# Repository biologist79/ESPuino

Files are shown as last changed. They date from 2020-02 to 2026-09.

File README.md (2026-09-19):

# ESPuino - RFID-controlled Audio Player based on ESP32 with I2S-DAC Support



## Forum

- EN: I've set up a primarily German-speaking community with much documentation. Also an
  international corner for non-German-speakers is available at <https://forum.espuino.de>.
  GitHub login can be used for signing in there (optional).
- DE: Ich habe ein primär deutschsprachiges Forum aufgesetzt, welches ich mit reichlich Doku
  versehen habe. Würde mich freuen, euch dort zu sehen: <https://forum.espuino.de>. Ihr könnt euch
  dort mit eurem Github-Login einloggen, jedoch auch "normal" anmelden. Dokumentation findet ihr
  insbesondere hier: <https://forum.espuino.de/c/dokumentation/anleitungen/10>.

## Handbook

- EN: A comprehensive handbook (German, English, French) covering setup, hardware, the web
  interface, and troubleshooting is available at <https://biologist79.github.io/ESPuino-Docs/>. It
  always describes the current state of the `dev` branch.
- DE: Ein ausführliches Handbuch (Deutsch, Englisch, Französisch) zu Aufbau, Hardware, Webinterface
  und Troubleshooting gibt es unter <https://biologist79.github.io/ESPuino-Docs/>. Es beschreibt
  immer den aktuellen Stand des `dev`-Branches.

## Firmwares

Ready-to-use firmwares are available for [download](https://github.com/biologist79/ESPuino-Firmware) for several
HALs with or without bluetooth support enabled. These are provided for
[master](https://github.com/biologist79/ESPuino-Firmware/tree/main/Firmwares/master) and
[dev-branch](https://github.com/biologist79/ESPuino-Firmware/tree/main/Firmwares/dev).

## News

> :warning: Due to memory restrictions and complexity, ESPuino doesn't run safely on ESP32
without PSRAM. So please make sure to use an ESP32-WROVER!

> :warning: As of January 8, 2026, MQTT topics have changed! Further infos [here](https://forum.espuino.de/t/neues-namensschema-fuer-mqtt/2553/34).

## Current development

There is a [development branch (dev)](https://github.com/biologist79/ESPuino/tree/dev) that contains
new features, that will be introduced and tested there first until they become part of the master
branch. Feel free to test but be advised this could be unstable.

## ESPuino - what's that?

The concept of ESPuino is a [more-or-less small enclosure](https://forum.espuino.de/t/zeigt-her-eure-espuinos/554/)
that contains a speaker so it can play music and audiobooks. Here is an example of a 3D-printed
unit, the [Biobox 3d](https://forum.espuino.de/t/biobox-3d/3130):

Biobox 3d

Primarily the device is controlled using RFID tags (usually cards), similar to those used for access control
(ski lifts, office access, etc.). To uniquely identify an RFID card, it carries a fixed ID.
ESPuino reads that ID (a 12-digit number) with an RFID card reader and triggers an action associated
on it. Which action to take is taught beforehand via ESPuino’s web interface: you upload audio
files to a microSD card, pick the desired audio file (or an entire folder) in the web interface’s
file browser and link it to the RFID card you placed. You mostly just click through the
web interface while manual input is possible (but usually unnecessary). When the RFID tag is presented
again, ESPuino loads the mapping and starts the desired playback. Present a different RFID tag and
the playback associated with that tag starts. In addition to audio files from the local microSD
card, web streams can be played, too. In Bluetooth mode you can also stream to the ESPuino from
your phone using [A2DP](https://de.wikipedia.org/wiki/A2DP), for example.

Further control elements on ESPuino are buttons and a [rotary encoder](https://forum.espuino.de/t/drehencoder-by-espuino/2414).
Buttons can be assigned dozens of different actions via the web interface — even double assignments (short
press vs. long press) are possible. By default, turning the rotary encoder controls the volume, but it
includes an integrated button, that's usually used to switch on ESPuino and
starts measurement of battery's voltage which is instantly indicated via LEDs (Neopixel). Additionally,
holding down a configured button while turning the encoder runs that button's own assigned rotary action
instead - e.g. seeking within a track or adjusting Neopixel brightness - freely configurable per
button and turning direction via the web interface. By default,
ESPuino is designed for three buttons and one rotary encoder, but this can be varied: from 0 up to 5
buttons, and no rotaty encoder or one rotaty encoder. If no rotary encoder is present, volume
control is handled, for example, via buttons.

A key feedback element is color-programmable LEDs (Neopixels), typically used as a
[Neopixel ring](https://duckduckgo.com/?t=ffab&q=neopixel+ring&ia=images&iax=images). They can
show, for example, track progress (if half the LEDs are lit, the track is half done), volume,
battery level, and error states — and
[much, much more](https://forum.espuino.de/t/was-zeigt-der-neopixel-des-espuino-alles-an/86)! ESPuino
also works without Neopixels, but that is not recommended because they convey a lot of information.

There is also an optional [headphone jack](https://forum.espuino.de/t/kopfhoererplatine-basierend-auf-ms6324-und-tda1308-bzw-lm4808m/1099)
that mutes the speaker when headphones are plugged in. Alternatively, Bluetooth headphones can be used.

ESPuino also communicates with the outside world: besides the web interface, it supports
[MQTT](https://de.wikipedia.org/wiki/MQTT), a [REST API](https://github.com/biologist79/ESPuino/blob/master/REST-API.yaml)
and an FTP server. New audio files can be copied to the microSD card via the web interface or
FTP — so the microSD card does not need to be removed.

## Hardware setup

You could start on a breadboard with jumper wires. However, the simplier way is to kickstart right away
with a PCB that was especially developed for ESPuino. There are [several available](https://forum.espuino.de/c/hardware/pcbs/11),
but ["ESPuino Complete"](https://forum.espuino.de/t/espuino-complete/3817) can be considered being the
latest one. This pcb can obtained via the [forum](https://forum.espuino.de/). It covers a charger
for LiFePO4 or LiPo batteries (for sure also runs with USB-C only) and provides connectors for up to 5 buttons,
rfid-reader, rotary encoder, i2c external, Neopixel, USB-C, µSD, speaker, [headphones PCB](https://forum.espuino.de/t/kopfhoererplatine-basierend-auf-ms6324-und-tda1308-bzw-lm4808m/1099) and some custom stuff.
[Port-expander](https://www.nxp.com/docs/en/data-sheet/PCA9555.pdf) and [MAX98357a](https://www.analog.com/en/products/MAX98357A.html)
are integrated, too. A [buck boost converter](https://www.ti.com/product/TPS63000) provides
stable 3.3 V while battery's voltage is [supervised](https://www.sg-micro.com/product/SGM809)
in order to prevent it from deep discharge. However, NEVER(!) use a lithium battery without a
further protection circuit that's already part of the battery pack!

Complete

> :warning: However, feel free to develop PCBs yourself. But again, be advised your ESP32 needs PSRAM in order to run ESPuino properly.

Optionally a [headphone-pcb](https://forum.espuino.de/t/kopfhoererplatine-basierend-auf-ms6324-und-tda1308/1099/)
can be attached to [Complete](https://forum.espuino.de/t/espuino-complete/3817) in order to connect headphones.
While headphone's plugged in, speaker is automatically disabled.

## Getting started (for users)

- [Much more documentation in german
  language](https://forum.espuino.de/c/dokumentation/anleitungen/10).
- There are already ready-to-use firmwares for [download available](https://github.com/biologist79/ESPuino-Firmware) that
  probably already fit your needs. Further informations can be found [here](https://forum.espuino.de/t/fertige-espuino-firmwares-zum-runterladen/3941). [Complete](https://forum.espuino.de/t/espuino-complete/3817) is always already shipped with running firmware, so your ESPuino should start right away.
- ESPuino opens a wifi access point that you need to join. For further details please refer [the first start](https://forum.espuino.de/t/der-erste-start-deines-espuino/29).
- Please make sure to read the [documentation of the web interface](https://forum.espuino.de/t/dokumentation-webinterface/2807).

## Getting started (for developers)

- In case you want (or need) to compile your own firmware, first you need to install Microsoft's [Visual Studio Code](https://code.visualstudio.com/).
- Install [PlatformIO Plugin](https://platformio.org/install/ide?install=vscode) into [Visual Studio
  Code](https://code.visualstudio.com/) and make sure to have a look at the
  [documentation](https://docs.platformio.org/en/latest/integration/ide/pioide.html).
  Step-by-step-manual is available
  [here](https://randomnerdtutorials.com/vs-code-platformio-ide-esp32-esp8266-arduino/.)
- Install [Git](https://git-scm.com/downloads) and make a copy ("clone") of my repository to your local
  computer using `git clone https://github.com/biologist79/ESPuino.git`. Using Git you can keep your
  local repository easily up to date without doing copy'n'paste. To keep it up to date run `git pull
  origin master`. Further infos
  [here](https://stackoverflow.com/questions/1443210/updating-a-local-repository-with-changes-from-a-github-repository)
  and
  [here](https://forum.espuino.de/t/espuino-in-platformio-anlegen-und-mit-git-aktuell-halten/891).
- (Optional) Install [GitLens](https://marketplace.visualstudio.com/items?itemName=eamodio.gitlens)
  as plugin (to have advanced Git features in VSCode).
- Now, that the Git repository is saved locally, import this folder into Platformio as a project.
- Select the [desired
  environment](https://forum.espuino.de/t/projekt-und-profilwechsel-in-visual-studio-code/768) (e.g.
  complete).
- Edit `src/settings.h` according your needs.
- Edit board-specific (`HAL`) config-file (e.g. `settings-complete.h` for Complete PCB) and switch to
  that HAL in VSC. If you're running a board that is not listed there: start with `settings-custom.h`
  and change it according your needs.
- Connect your PCB/develboard via USB, click the alien-head icon in the left sidebar, choose the project
  task that matches your desired HAL and run `Upload and Monitor`. All libraries necessary are
  fetched automatically and compilation of the code gets started. After that, your ESP32 is flashed
  with the firmware.
- Now have a look at the serial output at the bottom of Visual Studio Code's window. At the first
  run there might appear a few error messages (related to missing entries in NVS). Don't worry, this
  is just normal. However, make sure the µSD card is detected as this is mandatory for ESPuino to boot!
- If everything is fine, at the first run, ESPuino should open an access-point and ESPuino offers a
  captive portal (available in your browser's language, if supported) that is shown on your computer.
  If that's not the case, join a WiFi called
  "ESPuino" and enter `http://192.168.4.1` to your webbrowser. Enter WiFi credentials and the
  hostname there (or in the captive portal). Before saving, you can test the entered credentials
  directly from this page: ESPuino tries connecting to your WiFi in the background while the setup
  access point stays up, and reports success or a specific failure reason (e.g. wrong password,
  network not found) right there - no need to save, reboot and hope. After saving the configuration,
  restart ESPuino.
- After reboot ESPuino tries to join your WiFi (with the credentials previously entered). If that
  was successful, an IP is shown in the serial console. You can access ESPuino's web interface using a
  webbrowser via this IP; make sure to allow Javascript. If the mDNS feature is active in
  `src/settings.h`, you can use the hostname configured extended by .local instead the IP. So if you
  configured `espuino` as hostname, you can use `http://espuino.local` for web interface and FTP.
- Via FTP and web interface you can upload data (expect a throughput of roughly 650 kB/s via the web interface).
- FTP needs to be activated after boot if you need it! Don't forget to assign action
  `ENABLE_FTP_SERVER` in `settings.h` to be able to activate it. Neopixel flashes green (1x) if
  enabling was successful. It'll be disabled automatically after next reboot. Means: you have to
  enable it every time you need it (if reboot was in between). Sounds annoying and maybe it is,
  but's running this way in order to have more heap-memory available (for webstream) if FTP isn't
  needed.
- Via webbrowser you can configure various settings and pair RFID tags with actions. If
  MQTT/FTP-support was not compiled, their config tabs won't appear.

## SD-card: SPI or SD-MMC (1 bit)-mode? (for developers)

Having the µSD card working is mandatory, ESPuino doesn't start without working SD card (at least
unless `NO_SDCARD` hasn't been enabled previously). However, there are two modes available to
interface µSD cards: SPI and SDMMC (1 bit). Be advised that SDMMC is twice as fast as SPI and
needs one GPIO less. So basically it's a no-brainer and SDMMC is used for "ESPuino Complete".

## Which RFID-reader: RC522 or PN5180?

RC522 is in a way the ESPuino standard: it's cheap and works, but RFID tags have to be placed close
to the reader. PN5180 instead has better RFID range/sensitivity and can read ISO-15693 / iCode
SLIX2-tags aka 'Tonies' (you need a password to read Tonies), too. You can also wake up ESPuino with
the a RFID tag (after flashing PN5180 with a new firmware). This feature is called LPCD.
Disadvantages PN5180: it's more expensive and needs more GPIOs (6/7 instead of 4). In my opinion
it's worth it! Refer to PN5180's wiring section below for further information. Hint: if using 3.3 V
only make sure to connect these 3.3 V to PN5180's 5 V AND 3.3 V. Sounds weird but it's necessary.

## 3.3 V only or 5 V, too? (for developers)

ESP32 itself runs at 3.3 V only. But what about the periphery? Spoiler: "Complete" internally runs at
3.3 V only.

- My opinion: 3.3 V! Because it's simple. If you plan to use battery mode with LiPo/LiFePO4,
  there's no 5 V available (unless USB is connected or you make use of a boost converter).
- MAX98357A: provides more power at 5 V but also runs at 3.3 V. Anyway: it's still loud enough (in
  my opinion).
- Neopixel: specification says it needs 5 V but runs at 3.3 V absolutely fine.
- RC522: needs 3.3 V (don't ever power with 5 V!)
- PN5180: at 3.3 V make sure to connect both 5 V and 3.3 V pins to 3.3 V. If 5 V is available all
  the time: connect 5 V to 5 V and 3.3 V to 3.3 V.
- SD card: needs 3.3 V but if voltage regulator is onboard, it can be connected to 5 V as well
- Rotary encoder: 3.3 V (don't power with 5 V! Encoder doesn't care if connected to 3.3 or 5 V, but
  GPIOs of ESP32 do!)

## WiFi

WiFi is mandatory for web interface, FTP, MQTT and webradio. However, it can be temporarily or
permanently disabled (and ESPuino remembers this state after the next restart). There are two ways
to (re-)enable/disable WiFi:

- Use a special [modification card](https://forum.espuino.de/t/was-sind-modifikationskarten/37) that
  can be configured via web interface.
- Assign action `CMD_TOGGLE_WIFI_STATUS` to a button (or multi-button). This toggles the current
  WiFi status.

## Bluetooth

> :warning: **Bluetooth can now run in parallel with WiFi**, so streaming webradio via
  Bluetooth or accessing the web interface while a Bluetooth mode is enabled is possible.
  However, this combination is still not well tested and both stacks running at once puts
  considerably more pressure on the ESP32's limited RAM, so memory problems (up to crashes)
  are possible - use with caution. Switching between Bluetooth modes (or back to normal
  mode) still requires a restart.

### ESPuino as A2DP sink (stream to ESPuino)

ESPuino can be used as Bluetooth sink (A2DP sink). In this mode you can stream audio (e.g. from a
mobile device) via Bluetooth to your ESPuino. This mode can be enabled/disabled via a RFID
modification card or by assigning action `CMD_TOGGLE_BLUETOOTH_MODE` to a button (or multi-button).
Applying this will restart ESPuino immediately. Activated Bluetooth is indicated by four
slow rotating _blue-violet_ LEDs. After the Bluetooth device is paired the LEDs turn to blue.

### ESPuino as A2DP source (stream from ESPuino)

ESPuino can also be used to stream audio (A2DP source) to a Bluetooth headset or external Bluetooth
speakers. This mode can be enabled/disabled via a RFID modification card or by assigning action
`CMD_TOGGLE_BLUETOOTH_SOURCE_MODE` to a button (or multi-button). Applying this will restart ESPuino
immediately. Activated Bluetooth is indicated by four slow rotating _blue-violet_ LEDs. After the
Bluetooth headset is connected LEDs turn to blue.

## Port expander (for developers)

There might be situations where you run out of GPIOs. To address this, a port expander
[PCA9555](https://www.nxp.com/docs/en/data-sheet/PCA9555.pdf) can be used to extend the number of
input channels (output mode is only supported in special cases). PCA9555 provides 2 ports with 8
channels each - so 16 channels in total. To activate PCA9555 you need to enable
`PORT_EXPANDER_ENABLE`. Like GPIOs in your develboard-specific settings-file, you can assign
numbers. Range is `100` (port 0 channel 0) -> `115` (port 1 channel 7). Via `expanderI2cAddress` the
port expander's I2C-address can be changed. It's `0x20` if pins `A0`, `A1`, `A2` are wired to GND.

## After ESPuino is connected to your WiFi

After making ESPuino part of your LAN/WiFi, the 'regular' web interface is available at the IP assigned by
your router (or the configured hostname). Using this interface you can:

- configure WiFi
- make bindings between RFID tag, file/directory/URL and playback mode
- make bindings between RFID tag and a modification type
- configure MQTT and its topics (if enabled)
- configure FTP (if enabled)
- configure initial volume, minimum volume, maximum volume (speaker / headphone), brightness of
  Neopixel (night mode / default) and inactivity time
- configure voltage levels for battery mode (and optionally let ESPuino shut down automatically on
  critically low voltage)
- configure type of rfid reader (however, not necessary because of [autodetection](https://forum.espuino.de/t/autoerkennung-von-rfid-reader/4453))
- view logs / status / current track / cover art (if available)
- control player
- run modifications (like modification card)
- upload audiofiles (called web transfer)
- do OTA updates (ESP32-WROVER with 16 MB of flash memory only)
- import + delete NVS-RFID-assigments
- restart + shutdown ESPuino

> :information_source: As you apply a RFID tag to the RFID reader, the corresponding ID is pushed to
  the web interface automatically. So there's no need to enter such IDs manually (unless you want to). The
  file path is filled out automatically by selecting a file/directory in the file browser.

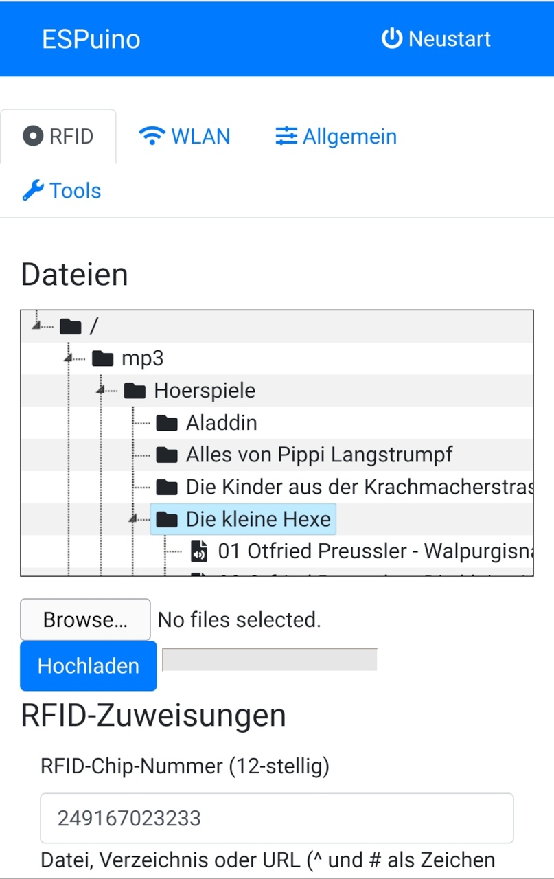
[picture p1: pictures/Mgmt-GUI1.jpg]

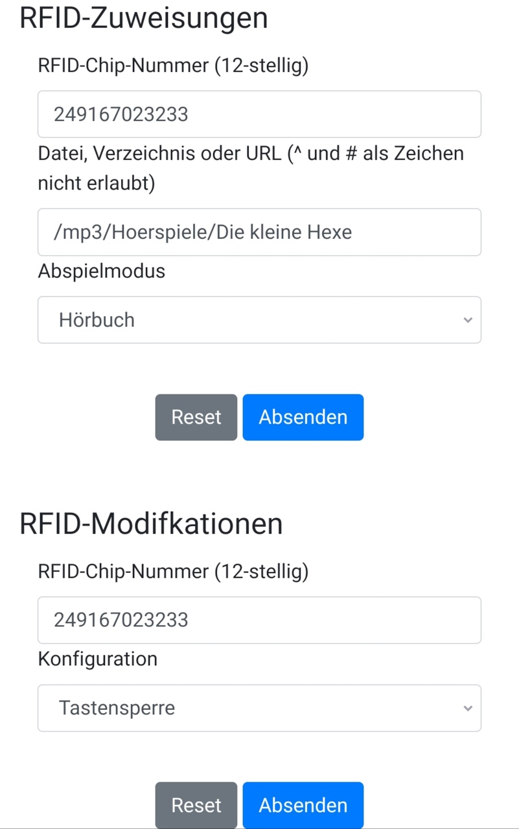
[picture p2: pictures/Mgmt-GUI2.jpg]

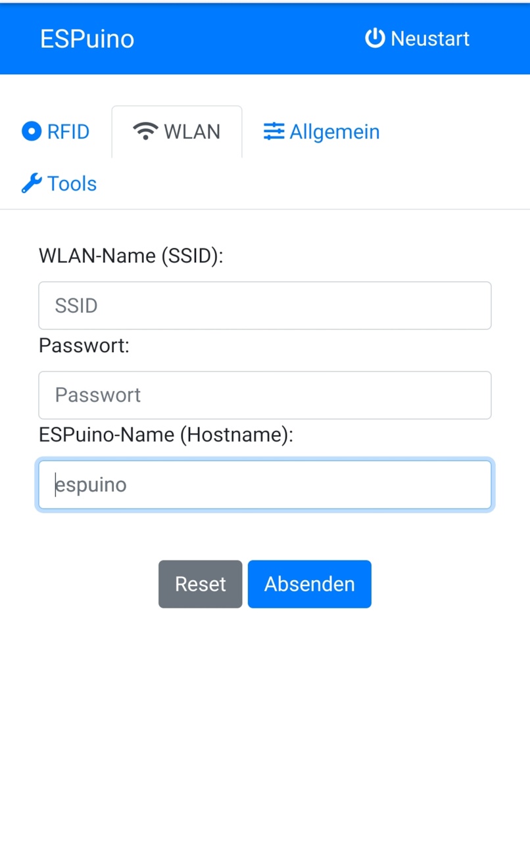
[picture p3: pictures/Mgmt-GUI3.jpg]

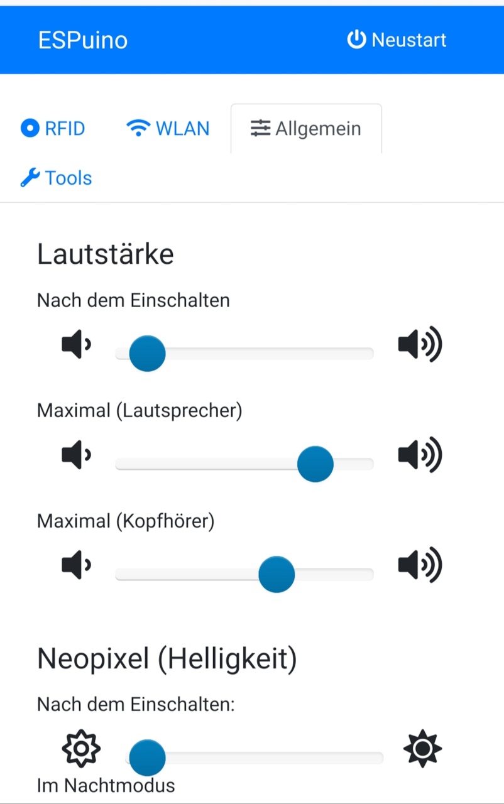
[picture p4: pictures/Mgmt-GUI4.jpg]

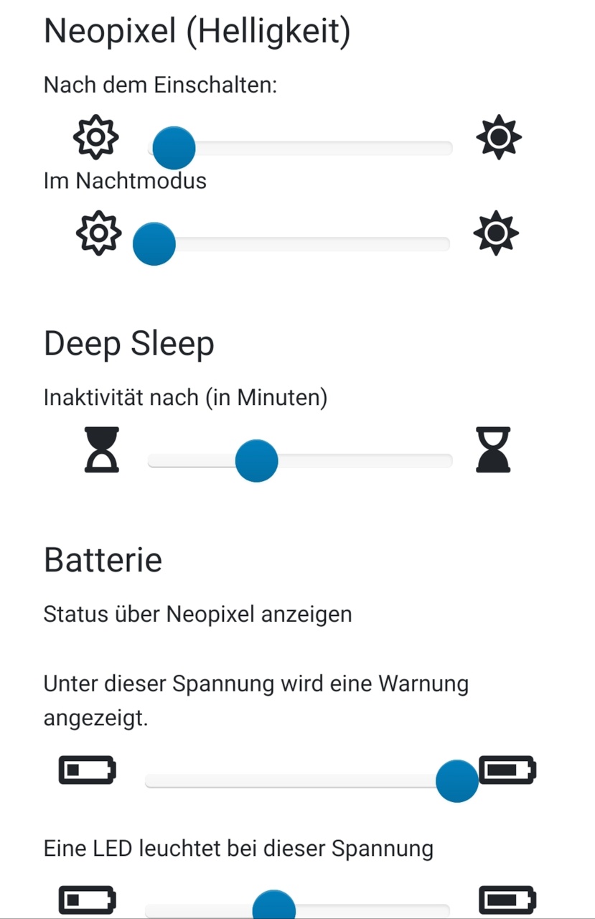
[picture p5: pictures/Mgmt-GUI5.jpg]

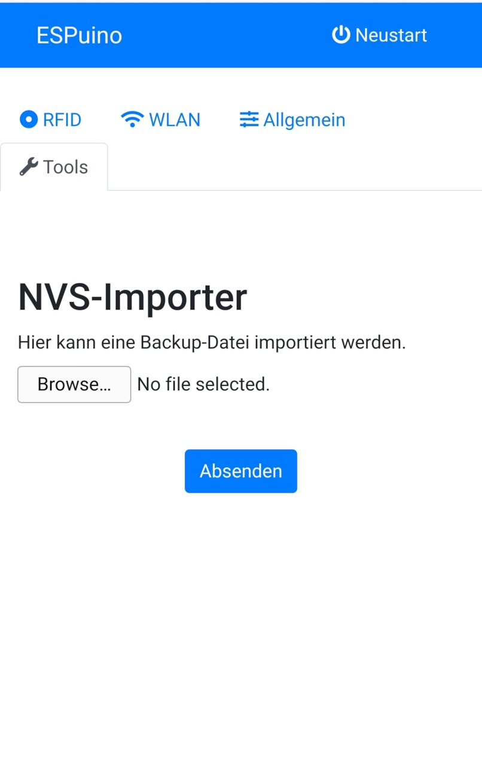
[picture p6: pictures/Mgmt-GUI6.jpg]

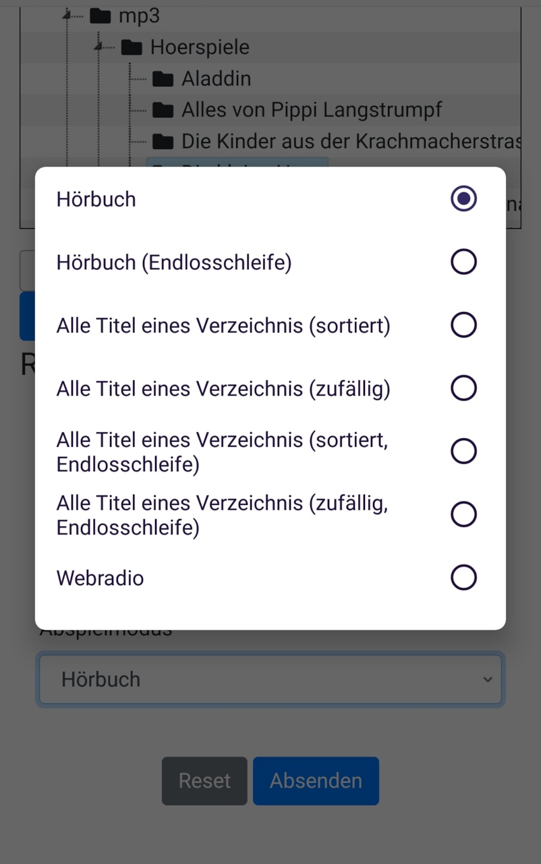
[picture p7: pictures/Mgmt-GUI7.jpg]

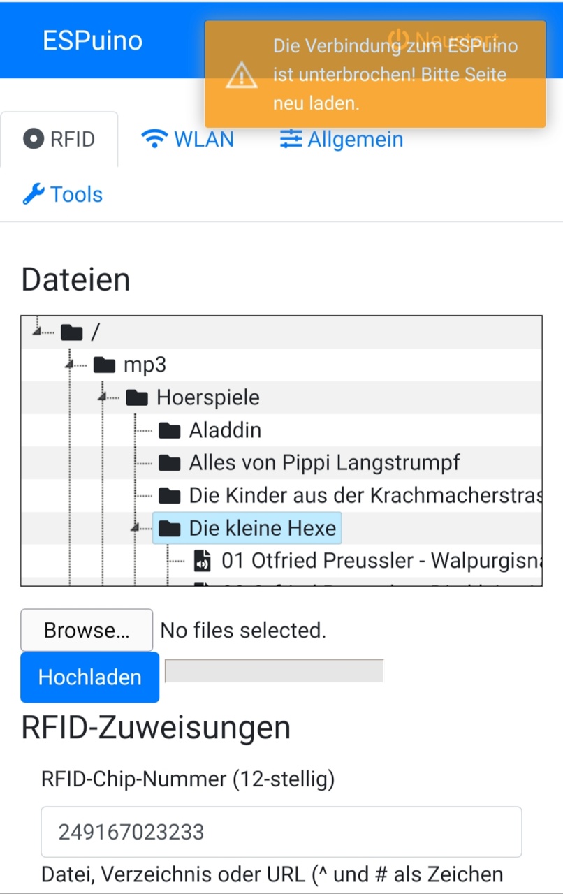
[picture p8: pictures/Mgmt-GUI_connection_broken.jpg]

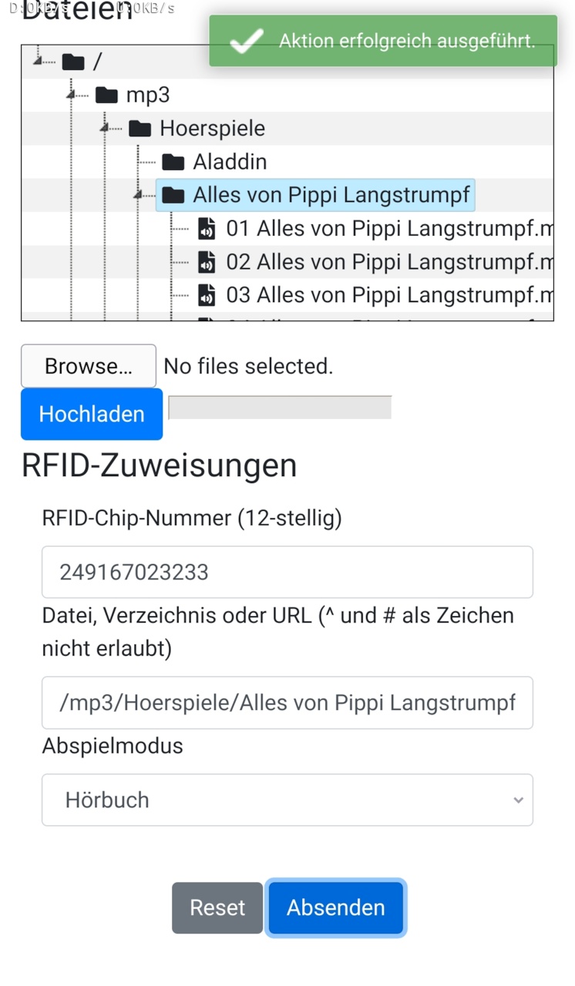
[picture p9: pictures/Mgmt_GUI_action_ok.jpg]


## Interacting with ESPuino

### Playback modes

It's not just simply playing music; different playback modes are supported:

| Type | Action |
| --- | --- |
| `Single track` | Plays one track one time |
| `Single track (loop)` | Plays one track forever |
| `Single track of a directory (random). Followed by sleep` | Picks and plays one single track out of a directory and falls asleep subsequently. Neopixel gets dimmed.|
| `Audiobook` | Single file or playlist/folder; last play position (file and playlist) is saved (when pushing pause or moving to another track) and reused next time |
| `Audiobook (loop)` | Same as audiobook but loops forever |
| `Audiobook with subdirectories (recursive)` | Same as audiobook, but with subdirectories |
| `Folder/playlist (sorted)` | Plays all tracks in order from a folder one time |
| `Folder/playlist (random order)` | Plays all tracks in random order from a folder one time |
| `Folder/playlist (sorted)` | Plays all tracks in order from a folder forever|
| `Folder/playlist (random order)` | Plays all tracks in random order from a folder forever |
| `All tracks of a random subdirectory (sorted)` | Plays of tracks in order of a randomly picked subdirectory of a given directory |
| `All tracks of a random subdirectory (random order)` | Plays all tracks in random order of a randomly picked subdirectory of a given directory |
| `All tracks of a directory + subdirectories (random, recursive)` | Same as All tracks of a random subdirectory (random order) but with subdirectories |
| `All tracks of a directory + subdirectories (sorted, recursive)` | Same as All tracks of a random subdirectory (sorted) but with subdirectories |
| `Webradio` | always only one "track": plays a webstream |
| `List (files from SD and/or webstreams) from local .m3u-File` | Can be one or more files / webradio stations with local .m3u as sourcefile |

### Modification RFID tags

There are special RFID tags, that don't start music by themselves but can modify ESPuinos behaviour. If applied
a second time, it's previous action/modification will be reversed.

So first make sure to start the music then use a modification card in order to apply your desired
modification:

| Type | Action |
| --- | --- |
| Lock/unlock all buttons | Locks / unlocks all buttons (might be useful for toddlers|
| Sleep after 5/30/60/120 minutes | ESPuino falls asleep automatically after the given period |
| Sleep after end of current track | ESPuino falls asleep after the current track |
| Sleep after end of playlist | ESPuino falls asleep after the current playlist |
| Sleep after five tracks | ESPuino falls asleep after five tracks |
| Dim Neopixel | Dim Neopixel to nightmode |
| Loop track | Loops / unloops current track |
| Loop playlist | Loops / unloops current playlist |
| Toggle WiFi (enable/disable) | Enables / disables WiFi. Please note: disabling WiFi while webstream is active will stop a running webstream instantly! |
| Toggle Bluetooth sink (enable/disable) | Restarts ESPuino immediately. In this mode you can stream to your ESPuino via BT whereas websteam / SD is not available. Hint: if you lost this modification card you can 'escape' this mode with an RFID tag that's unknown to ESPuino. |
| Toggle Bluetooth source (enable/disable) | Restarts ESPuino immediately. In this mode your ESPuino can stream via BT to an external device whereas websteam / SD is not available. Hint: if you lost this modification card you can 'escape' this mode with an RFID tag that's unknown to ESPuino.|
| Toggle through the different modes | Normal => BT-Sink => BT-Source => Normal |
| Speech output of IP-address or current time | Speech output of IP address or current time |
| Toggle Ambient Light | Enables / disables ambient light |

> :information_source: All sleep modes do dimming (Neopixel) automatically because it's supposed to
  be used in the evening when going to bed. Well, at least that's my children's indication :-)
>
> :information_source: Track and playlist loop mode can both be activated at the same time, but
  unless track loop isn't deactivated, playlist loop won't be effective

### Neopixel LEDs (optional)

Indicates various things. Don't forget configuration of number of LEDs via via webinterface.
Most ESPuino designs make use of Neopixel rings, but a linear strip is also possible. Even a single
LED can be used.

> :information_source: Some Neopixels use a reversed addressing which leads to the 'problem', that
  all effects are shown counter clockwise. If you want to change that behaviour, just change it via webinterface.

#### Boot

- While booting: every second LED (rotating orange)
- Unable to mount SD: LEDs flashing red (will remain forever unless SD card is available or
  `SHUTDOWN_IF_SD_BOOT_FAILS` is active)

#### Status

- **Idle**: four LEDs slowly rotating (white if WiFi connected; green if WiFi disabled or ESPuino is
  about to connect to WiFi)
- **Bluetooth**: four LEDs slow rotating coloured blue
- **Error**: all LEDs flashing red (1x) if an action was not accepted
- **OK**: all LEDs flashing green (1x) if an action was accepted
- **Power Off**: red-circle that grows until long-press-time is reached
- **Buttons Locked**: track-progress-LEDs coloured red

#### Playback

- **Busy**: violet; four fast rotating LEDs when generating a playlist. Duration depends on the
  number of files in your playlist.
- **Track Progress**: rainbow; number of LEDs relative to play-progress
- **Playlist Progress**: blue; appears only shortly in playlist-mode with the beginning every new
  track; number of LEDs relative to progress
- **Webstream**: two slow rotating LEDs that change their colours rainbow-wise as the stream
  proceeds
- **Volume**: green => red-gradient; number of LEDs relative from current to max volume
- **Paused**: track-progress-LEDs coloured orange
- **Rewind**: if single-track-loop is activated a LED-rewind is performed when restarting the given
  track

#### Battery Status (optional)

- **Undervoltage**: flashes three times red if battery-voltage is too low. This voltage-level can be
  configured via web interface. Optionally, ESPuino can be told to shut down automatically once the
  voltage drops below a configurable critical level (off by default; enable it via web interface).
- Short press of rotary encoder's button provides battery-voltage visualisation via Neopixel. Upper
  und lower voltage cut-offs can be adjusted via web interface. So for example if lower voltage is set to 3.2
  V and upper voltage to 4.2 V, 50% of the LEDs indicate a voltage of 3.7 V.

### Buttons

> :warning: This section describes my default-design: 3 buttons + rotary-encoder. Feel free to
  change number of buttons (up to 5) and button-actions according your needs in `settings.h` and
  your develboard-specific config-file (e.g. `settings-complete.h`). At maximum you can activate five
  buttons + rotary-encoder. Minimum duration for long press (to distinguish vom short press) in ms
  is defined by `intervalToLongPress`. All actions available are listed in `src/values.h`. If using
  GPIO \>= 34 make sure to add a external pullup-resistor (10 k).

- **Previous** (short): previous track / beginning of the first track if pressed while first track
  is playing
- **Previous** (long): first track of playlist
- **Next** (short): next track of playlist
- **Next** (long): last track of playlist
- **Pause/Play** (short/long): pause/play
- **Rotary Encoder** (turning): vol +/-
- **Rotary Encoder** (button long): switch off (only when on)
- **Rotary Encoder** (button short): switch on (when switched off)
- **Rotary Encoder** (button short): show battery-voltage via Neopixel (when switched on and
  `MEASURE_BATTERY_VOLTAGE` is active)
- **Previous** (long; keep pressed) + **Next** (short) + release (both): toggle WiFi
  enabled/disabled
- **Any button** (held) + **Rotary Encoder** (turning): runs that button's own configured rotary
  action (e.g. seek within the track, adjust Neopixel brightness) instead of changing the volume -
  freely assignable per button and turning direction via the web interface, off (`--`) by default
  for most buttons

#### Virtual RFID cards

Any of the button actions can also be assigned to [virtual RFID cards](https://forum.espuino.de/t/virtual-rfid-cards/3218/2).
Those cards then can be assigned on the web interface like normal cards.
To select a virtual RFID card, just press the configured button action,
the virtual RFID automatically gets filled in in the web interface.

### Audiobook mode

This mode is different from the others because the last playback position is saved, when...

- next track starts.
- first/previous/last track requested by button.
- pause was pressed.
- track is over.
- playlist is over (position is reset to the first track and file position 0).
- As per default last playback position is not saved when applying a new RFID tag. You can change this
  this behaviour via webinterface.
- As per default last playback position is not saved when doing shutdown. You can change this
  this behaviour via webinterface.

### FTP (optional)

- FTP needs to be activated after boot! Neopixel flashes green (1x) if enabling
  was successful. It'll be disabled automatically after next reboot. Means: you have to enable it
  every time you need it (if reboot was in between). Sounds annoying and maybe it is, but it's
  running this way in order to save heap memory when FTP isn't needed.
- Why FTP? In order to avoid exposing the SD card or disassembling ESPuino all the time for
  adding new music, it's possible to transfer music to the SD card using FTP. Another possibility
  is to do via web interface (webtransfer).
- Default user and password are set to `esp32` / `esp32` but can be changed via web interface.
- Secured FTP is not available. So make sure to disable SSL/TLS.
- Software: my recommendation is [Filezilla](https://filezilla-project.org/) as it's free and
  available for multiple platforms.
- Please note: if music is played in parallel, the transfer rate decreases! So consider to stop
  playback when doing file transfers.

### Energy saving

As already described in the modifications section, there are different sleep modes available.
Additionally the ESP32 controller will be put to deep sleep after 10 minutes of inactivity
(configurable via `maxInactivityTime`) unless ESPuino doesn't play music, has a FTP client connected
and any input via buttons. Every button interaction resets the counter.

### Backups

As all assignments between RFID IDs and actions (playback mode, file to play, ...) is saved in ESP32's
NVS, the problem is that it's all gone when the ESP is broken. So that's where a backup comes in
handy. Every time you change or add a new assignment between a RFID tag and an action via web interface, a
backup file is saved on the SD card. The file's name can be changed via `backupFile`. So better
don't delete it! Using the web interface you can use the upload form to import such a file.

### MediaHub (optional)

MediaHub is an optional way to manage the RFID-tag assignments of one or more ESPuinos
**centrally**, instead of configuring each device's SD card and NVS individually. It's a small,
self-hosted server (a Docker container running on your own network) that holds the assignments. A
card assigned to a MediaHub server fetches its content and playback mode from the server when
tapped, and downloads the referenced files to its own SD card on first use - kept in sync
afterwards, with force-refresh and integrity checks. Webradio/webstream assignments work too. You
register your MediaHub server(s) in the web interface (Files/RFID → MediaHub); the hub itself runs
separately, see [ESPuino-MediaHub](https://github.com/biologist79/ESPuino-Mediahub).

For a full description, setup and discussion, refer to the [MediaHub thread in the
forum](https://forum.espuino.de/t/espuino-mediahub/4607).

### Smarthome/MQTT (optional)

Everything that can be controlled via RFID tags and buttons, can also be controlled via MQTT
(excepting toggling WiFi status as this doesn't make sense). All manual interactions (buttons, RFID
tags) are also sent to MQTT in parallel, so everything is always in sync (unless
Wifi/MQTT-connection is broken).

In order to use it it's necessary to run a MQTT broker; [Mosquitto](https://mosquitto.org/) for
instance. After connecting to it, ESPuino subscribes to all command-topics. State-topics are used to
push states to the broker in order to inform others if anything changed (change of volume, new
playlist, new track, you name it).

In my home setup I'm using [openHAB](https://www.openhab.org/) to "encapsulate" MQTT into a nice
GUI, that's accessible via app + web. For further information (and pictures) refer to the [openHAB
directory](https://github.com/biologist79/ESPuino/tree/master/openHAB).

> :information_source: I [described](https://github.com/biologist79/ESPuino/tree/master/openHAB) a
  sample config for openHAB2. However, meanwhile openHAB5 is available and all the stuff described
  can also be configured via web interface. Be advised that openHAB is pretty complex and you have to spend
  some time to get familiar with it.

However, there's also stuff available for [Home Assistant](https://forum.espuino.de/t/home-assistant-integration/3763).

#### MQTT topics

Feel free to use your own smarthome environments (Home Assistant, Node Red...). The MQTT topics available are
described as follows.

> :information_source: Topics follow the pattern: `[<base_topic>/]device_id/topic[/setter_token]`. Command topics use the optional setter token appended to the topic (for example: `<baseTopic>/<deviceId>/<topic>/<setter_token>`, e.g. `home/ESPuino-01/loudness/set`), while state topics are published on the topic without the setter token (for example: `<baseTopic>/<deviceId>/<topic>`, e.g. `home/ESPuino-01/loudness`). For example, to change the volume to `8`, publish `8` to the command topic for `topicLoudness` (e.g. `.../loudness/set`); ESPuino will confirm by publishing the value on the state topic for `topicLoudness` (`.../loudness`). To get hands on MQTT I recommend this [one](https://www.hivemq.com/mqtt-essentials/) as introduction (covers more than you need for ESPuino).

| topic-variable | range | meaning |
| --- | --- | --- |
| topicSleep | Cmnd: 0 or OFF; State: ON or OFF | Cmnd: power off (send '0' or 'OFF'); State: sends current power state |
| topicRfid | Cmnd/State: 12 digits | Cmnd: emulate an RFID tag by sending a 12-digit id (e.g. `123789456089`); State: current RFID tag id |
| topicTrack | String | State: current track info (e.g. "(2/10) /mp3/.../file.mp3") |
| topicTrackControl | 1 -> 9 | Cmnd: playback control (`1`=stop; `3`=play/pause; `4`=next; `5`=prev; `6`=first; `7`=last; `8`=next folder; `9`=previous folder) |
| topicCoverChanged | (flag) | State: indicates cover image may have changed (load only if visible) |
| topicLoudness | Cmnd/State: 0 -> 21 | Set/report loudness (depends on minVolume / maxVolume) |
| topicSleepTimer | Cmnd/State: EOP / EOT / EO5T / 1->2^32 / 0 | Cmnd: set sleep timer (EOP/EOT/EO5T or minutes; 0 to deactivate). State: current timer value (e.g. `EOP`, `EOT`, `EO5T`, `0`, ...) |
| topicSleepTimerState | State: JSON | State: live sleep-timer status as JSON, e.g. `{"mode":"MINUTES","remainingMinutes":29,"remainingTracks":0}`. `mode` is `OFF`/`MINUTES`/`EOT`/`EOP`/`EO5T`; `remainingMinutes` counts down for a minute-timer, `remainingTracks` for `EOT`/`EO5T`/`EOP`. Read-only companion to `topicSleepTimer` |
| topicState | Online, Offline | `Online` when powering on, `Offline` when powering off |
| topicCurrentIPv4IP | IPv4-string | Sends ESPuino's IP-address (e.g. `192.168.2.78`) |
| topicPausePlay | idle, play, pause | Sends playback state: `idle` (no playback), `play` (playing), `pause` (paused) |
| topicLockControls | Cmnd/State: ON or OFF | Set/report whether physical controls are locked |
| topicPlaymode | 0 - 10 | State: current playback mode (single track, audiobook...; see [playback modes](#playback-modes)) |
| topicRepeatMode | Cmnd/State: 0 - 3 | Set/report repeat mode (`0`=no; `1`=track; `2`=playlist; `3`=both) |
| topicLedBrightness | Cmnd/State: 0 - 255 | Set/report Neopixel brightness |
| topicBatteryVoltage | float | Voltage (e.g. 3.81) |
| topicBatterySOC | float | Current battery charge in percent (e.g. 83.0) |
| topicWiFiRssi | int | State: numeric WiFi signal-strength (dBm) |
| topicSRevision | String | State: software revision string |

### REST API

Even [REST API](./REST-API.yaml) is available with various GET, POST, DELETE and PUT-calls.

## Development and Contributions

### Code Formatting

Automatic code formatting via `clang-format` is used. The configuration/rules can be found in
`.clang-format`. If you use Visual Studio Code as IDE, the support for this is automatically
available through the C++ extension.

When editing source code, use Ctrl+Shift+I to run the auto-formatting on the file or Ctrl+K Ctrl+F
for the selected code.

See the [documentation](https://code.visualstudio.com/docs/cpp/cpp-ide#_code-formatting) for more
options like run auto-formatting on saving or editing the file.

The CI (via "GitHub Actions") checks changes when they are pushed in order to keep the source code
clean and provide feedback to the developers and maintainers.

To keep the output of `git blame` clean despite the massive changes when introducing new formatting
rules, we have a `.git-blame-ignore-revs` that lists the commits to ignore. In VSCode this should be
used automatically if you use the "GitLens" extension. Otherwise make sure you apply the config
fragment for git by running `git config --local include.path ../.gitconfig` once in your local
clone.

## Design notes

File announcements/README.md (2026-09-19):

# Announcements

Short spoken messages ESPuino can play while music is running — currently only the low-battery
warning. Playback is interrupted for the length of the announcement and then resumes at exactly the
same spot; the web interface and MQTT never see the interruption.

The feature is off by default. Switch it on under **General → Power**, where you also point it at the
file to play.

## Using the files here

1. Copy the file for your language onto the SD card, e.g. to `/ESPuino/announcements/`.
2. In the file browser, right-click it and choose **Use as battery warning** — that fills in the path
   and jumps to the setting. Alternatively type the path into the field yourself.
3. Tick the checkbox and save.

If the file is missing or cannot be played, playback simply carries on untouched and an error is
written to the log.

| File | Voice | Spoken text |
| --- | --- | --- |
| `battery-low_de.mp3` | Anna | „Der Akku ist fast leer. Bitte laden." |
| `battery-low_en.mp3` | Samantha | "The battery is almost empty. Please charge." |
| `battery-low_fr.mp3` | Thomas | « La batterie est presque vide. Merci de la recharger. » |

MP3, mono, 22.05 kHz, 64 kbit/s, around 20 KB each. `.wav`, `.flac`, `.m4a`, `.aac`, `.ogg` and
`.opus` are played as well, so any format you already have is fine — MP3 is simply the cheapest one
for the ESP32 to decode.

## Recording your own

Nothing here is special — any short audio file does. A different voice, your own wording, or a
parent's voice recorded on a phone all work just as well, and for children the last one is usually
the nicest.

These files were generated on macOS with the built-in `say` plus ffmpeg:

```bash
say -v Anna -o /tmp/announcement.aiff "Der Akku ist fast leer. Bitte laden."
ffmpeg -i /tmp/announcement.aiff -codec:a libmp3lame -b:a 64k -ac 1 -ar 22050 battery-low_de.mp3
```

`say -v '?'` lists the available voices. Besides the neutral system voices there are friendlier ones
such as `Grandma` and `Grandpa`, which tend to suit a children's room better.

The second step is worth it: `say` writes stereo at a high bitrate, and mono at 64 kbit/s cuts the
file to roughly a fifth without any audible difference for speech. Without ffmpeg at hand, macOS can
also produce a playable file on its own — `say -o battery-low_de.m4a "..."` writes AAC directly — but
it cannot encode MP3.

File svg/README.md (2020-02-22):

`holes_n_ring.svg`: Used to CNC a ring and the holes into a wood-enclosure<br />
`inner ring.svg`: Used to cnc a ring that the speaker is screwed to. The ring is glued to the enclosure.

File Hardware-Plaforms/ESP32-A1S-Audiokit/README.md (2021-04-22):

## Things to know
* As there's a lack of GPIOs, it's necessary to share a single SPI-instance by SD and RFID.
* The board provides 6 keys but due to lack of free GPIOs, we need them for other purposes. Additionaly the problem is, that all keys are equipped with capacitors (maybe to debounce) which makes it hard to use those GPIOs for other purposes. That's why I unsoldered R66, 67, 68, 69, 70 (all 0 Ohms) to free these GPIOs from the capacitors.
* Please note: key1 still works but if you additionaly want to use keys2-6, you can use GPIO36 along with analogRead() by using voltage-dividers. But first one has to calculate + solder resistor-pairs 56/61, 57/62, 58/63, 59/64 to 'build' those voltage-dividers. Without doing that online Key1 is usable as it doesn't need resistors. However, didn't solder/test dividers so far.
* When switching over to use analogRead() one has to modify Button_Cyclic() in my code.
* Additionaly I unsoldered resistor R14 in order to deactivate LED D4 (probably not necessary)

## GPIOs (outdated! Best have a look at settings-espa1s.h)
Please note: You need to unsolder R66, 67, 68, 69, 70 first to use the board that way!

| GPIO | Usage | Pin | Comment |
| --- | ---| --- | --- |
| 0 | internal (I2S) | MCLK | |
| 2 | SD (int.) + RFID | SPI.MISO | Solder wire to SD.7 for RFID |
| 4 | Rot. Encoder | BUTTON | Solder wire to SD.8 |
| 5 | Rot. Encoder | CLK | Via 14-pin-header |
| 12 | RFID | SPI.CS | Via JT_MTDI |
| 13 | internal (SD) | SPI.CS | CS for SD |
| 14 | SD (int.) + RFID | SPI.SCK | Via JT_MTMS |
| 15 | SD (int.) + RFID | SPI.MOSI | Via JT_MTDO |
| 18 | Rot. Encoder | DT | Via 14-pin-header |
| 19 | Power | | For switch on/off external hardware via MOSFET (optional) |
| 21 | internal (amp) | | To switch on/off amp |
| 22 | unused? | | Via 14-pin-header |
| 23 | Neopixel | DI | Via 14-pin-header |
| 25 | internal (I2S) | DSIN | |
| 26 | internal (I2S) | LRC | |
| 27 | internal (I2S) | BCLK | |
| 32 | internal (I2C) | CLK | |
| 33 | internal (I2C) | DATA | |
| 34 | internal (SD) | DETECT | To detect if SD is present (not used) |
| 35 | internal (I2S) | DOUT | |
| 36 | internal (Key) | A/D | Analog read for keys 1-6 or digial read for only key 1 |
| 39 | internal (HP) | DETECT | Detects if headphone is plugged in |

Now, question is what to do with GPIO22. Could be used to externally connect keys for analogRead() via voltage-dividers.

## Power-consumption
* IDLE: 105 mA
* Deepsleep (without RFID + Neopixel): 30 mA

## Things to consider
* I didn't battery-power this board (guess it works but didn't test). But as current in deepsleep still is 30 mA, this probably doesn't make sense.
* When using a switch (instead of putting 'only' to deepsleep), GPIO 19 (power) could be omitted. Along with GPIO 22, these buttons could be used as buttons 'previous' and 'next'. Third button could be omitted by assigning short-press-action of rotary-encoder for 'pause/play'.
* In order to safe energy consider the unsolder LEDs.

## Please note
* Some additional informations regarding this board can be found [here](https://www.mikrocontroller.net/topic/474383?goto=6429727) and [here] (https://www.mikrocontroller.net/topic/492149).

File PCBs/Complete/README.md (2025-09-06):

# ESPuino complete

This is a pcb, that was developed by myself in 2025. It's the latest pcb available for ESPuino and fully described (in German language) [here](https://forum.espuino.de/t/espuino-complete/3817). Please contact me via my forum in case you need one fully soldered and ready-to-use.

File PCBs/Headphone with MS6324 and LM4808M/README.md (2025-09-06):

# Headphone-PCB

This is a pcb, that was developed by myself. It makes use of a DAC named 'MS6324' with a LM4808M as amp. It's described in detail with pictures [here](https://forum.espuino.de/t/kopfhoererplatine-basierend-auf-ms6324-und-tda1308/1099). Please contact me via my forum in case you need one fully soldered and ready-to-use.
It's compatible with [ESPuino complete](https://forum.espuino.de/t/espuino-complete/3817) and [mini4L](https://forum.espuino.de/t/espuino-mini-4layer/1661).

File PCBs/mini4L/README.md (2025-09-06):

# ESPuino mini 4-Layer

This is a pcb, that was developed by myself back in 2023. It's used by hundreds of ESPuino users and fully described (in German language) [here](https://forum.espuino.de/t/espuino-mini-4layer/1661). It's successor is [ESPuino complete](https://forum.espuino.de/t/espuino-complete/3817). Kicad and Gerber files will be released soon.
It's compatible with my self-developed [LiFePO4-develboard](https://forum.espuino.de/t/esp32-develboard-d32-pro-lifepo4/1109) and [Wemos Lolin D32 pro](https://www.wemos.cc/en/latest/d32/d32_pro.html). Pin-wise it's compatible with [Wemos Lolin D32](https://www.wemos.cc/en/latest/d32/d32.html), too - but as D32 doesn't feature PSRAM, this is useless for ESPuino.

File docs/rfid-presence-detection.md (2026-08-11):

# RC522 constant-presence detection: root cause & fix

Context: In `pauseIfRfidRemoved` mode, playback would flap (pause/resume) while a
card sat perfectly still on the reader, and card-removal detection was unreliable
on RC522 clones. During debugging we first tried papering over this with a growing
"consecutive misses" debounce (3 → 8 cycles ≈ 400 ms). That treats the symptom.
This note records the actual root cause and the fix.

## Root cause: REQA never reliably re-detects a stationary card

The old presence loop polled with `PICC_IsNewCardPresent()`. Under the hood that
sends **REQA (`0x26`)**. From the MFRC522 library's own header:

| Command | Opcode | Wakes cards in state… |
|---|---|---|
| `REQA`  | `0x26` | **IDLE only** ("Sleeping cards in state HALT are ignored") |
| `WUPA`  | `0x52` | **IDLE and HALT** |
| `HLTA`  | `0x50` | moves an ACTIVE card → HALT |

The ISO-14443A state machine is: `IDLE → (REQA/WUPA) → READY → (Select) → ACTIVE → (HLTA) → HALT`.

In `pauseIfRfidRemoved` mode the old code deliberately did **not** `HaltA()` after
reading the card (`RfidMfrc522.cpp`, the `if (!gPlayProperties.pauseIfRfidRemoved)`
guard around `PICC_HaltA()`). So the card was left in the **ACTIVE** state — and an
ACTIVE card does not answer REQA. The loop then relied on a block of "voodoo"
(from miguelbalboa/rfid issue #188) that re-ran `PICC_ReadCardSerial()`
(anticollision + Select) on retries and checked for a magic `control == 13 || 14`.

Whether that re-Select succeeds on any given poll depends on which state the card
(and a sloppy clone's state machine) happens to be in at that instant. That is the
coin-flip we were seeing. Requiring N consecutive misses only hides dropped polls,
at the cost of N × ~50 ms of removal latency — it can never make the underlying
poll deterministic.

## The fix: keep the card in HALT, poll with WUPA

Park the card in a **known** state (HALT) after every read, and poll with the one
command that wakes a HALTed card. Each poll becomes a clean yes/no.

```cpp
template <typename Reader>
static bool RfidMfrc522_CardStillPresent(Reader &reader) {
    byte bufferATQA[2];
    byte bufferSize = sizeof(bufferATQA);
    // mirror PICC_IsNewCardPresent()'s register reset; some readers need it
    reader.PCD_WriteRegister(Reader::TxModeReg, 0x00);
    reader.PCD_WriteRegister(Reader::RxModeReg, 0x00);
    reader.PCD_WriteRegister(Reader::ModWidthReg, 0x26);
    auto result = reader.PICC_WakeupA(bufferATQA, &bufferSize); // WUPA wakes HALT
    reader.PICC_HaltA();                                        // straight back to HALT
    return (result == Reader::STATUS_OK || result == Reader::STATUS_COLLISION);
}
```

Companion change: in `pauseIfRfidRemoved` mode we now `PICC_HaltA()` immediately
after the initial read, so the card enters the poll loop already in HALT. The
`control`/voodoo block and the 8-cycle debounce are gone; the loop is just:

```cpp
while (RfidMfrc522_CardStillPresent(reader) || ++misses < removalDebounceCycles) { … }
```

`removalDebounceCycles` is kept at **2** (≈100 ms) purely to swallow the rare
genuinely-dropped poll from RF noise. Because each WUPA poll is now deterministic,
this can be dropped to **1** to test raw reliability with zero miss tolerance.

### Template note (both reader types)

`RfidMfrc522_TaskImpl` is instantiated for both the SPI `MFRC522` class and the
I2C `MFRC522_I2C` class. Those two libraries differ in ways that matter here:

- Register addresses: SPI values are `<< 1` shifted (`TxModeReg = 0x24`), I2C are
  raw (`TxModeReg = 0x12`).
- `StatusCode`: SPI `STATUS_OK = 0`, I2C `STATUS_OK = 1`.
- `PICC_WakeupA` returns `MFRC522::StatusCode` (SPI) vs `byte` (I2C).

Using `Reader::TxModeReg` / `Reader::STATUS_OK` and `auto result` lets the compiler
pick the correct constants and types per instantiation, so one helper serves both.

## Verified

`pio run -e esp32-s3-devkitc-1` — recompiles `RfidMfrc522.cpp` and links the full
firmware **SUCCESS**. That env defines `RFID_READER_TYPE_RUNTIME` and
`I2C_2_ENABLE`, so both the SPI and I2C template instantiations are exercised.

(Note: `-e lolin_d32_pro_sdmmc_pe`, the repo default env, fails to build on the
current machine for **unrelated, pre-existing** reasons — a FastLED
`addLeds<CHIPSET, LED_PIN, COLOR_ORDER>` version mismatch in `Led.cpp` and
undeclared `I2S_BCLK/LRC/DOUT` pins in `AudioPlayer.cpp`, i.e. that env's per-user
pin config isn't present here. Neither involves `RfidMfrc522.cpp`.)

## If it's still unreliable after this — secondary avenues

These are hardware/tuning, in rough order of effort-to-payoff:

1. **Antenna gain is at max (`mfrc522Gain` default `0x07`, ~48 dB).** For a card
   sitting *directly* on the coil, max gain can saturate the receiver and garble
   the ATQA. Counterintuitively, try `0x04`–`0x05`. Quick test via the `mfrc522Gain`
   NVS pref.
2. **Power decoupling.** RC522 clones brown out on the RF transmit burst. Add a
   10–100 µF cap across the module's 3V3/GND and make sure the 3.3 V rail is solid.
   Many "random" dropped polls are actually supply dips.
3. **Hardware swap — PN532.** If the clone is simply bad, no firmware saves it. The
   PN532 has proper in-field target detection (vs. repeated REQA/WUPA polling) and
   is the reliable choice for continuous-presence use; several Tonuino/Toniebox-style
   builds moved to it for exactly this reason.

## Live test results (2026-07-05, ESP32-S3 + RC522 clone, SPI, version reg 0x82)

Bench-tested for ~2 h on real hardware in `pauseIfRfidRemoved` mode with an
audiobook playlist and multiple Mifare cards:

- **Protocol fix confirmed.** No pause/resume flapping while a card sits
  stationary on the reader; verified stretches of 38+ s continuous presence
  with playback progressing. Genuine removals are detected in 100–400 ms
  (2-cycle debounce) — down from the 400 ms+ the old 8-cycle debounce needed
  just to stay stable.
- **Secondary avenue #1 (antenna gain) also confirmed.** With the default
  `mfrc522Gain` (7 = 48 dB max), a card lying *directly on* the reader coil
  got a phantom removal 100–400 ms after every detect (receiver saturation) —
  log signature: `RFID-tag removed` → immediate pause at position 0. The same
  card at ~3 cm was rock solid. Setting `mfrc522Gain = 5` fixed contact
  distance completely. Reminder: the pref is only read in `RfidMfrc522_Init`,
  so it needs a reboot to apply.
- Side effect worth knowing: with max gain those phantom removals paused
  playback instantly after a card was applied, which presents as "the box
  doesn't start playing" — an audio-looking symptom whose actual cause is RF.

## Optional hardening (not yet done)

`WUPA` confirms *a* card is present, not that it's the *same* UID — a card swapped
during playback would read as "still present". If that matters, change the poll to
`WUPA → PICC_Select → compare UID → HaltA`. Slightly slower, still deterministic.

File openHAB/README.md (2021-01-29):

# OpenHAB-integration for ESPuino

## Disclaimer
[OpenHAB](https://www.openhab.org/) is a pretty complex software for home automation. I just extracted that parts of my local config, that are necessary for ESPuino. Hopefully I didn't forget anything :-) Said this I want to rule out I didn't test this minimal setup and that this document's aim isn't to provide a fully-featured howto. For further informations please have a look at the project's [documentation](https://www.openhab.org/docs/) or the [community](https://community.openhab.org/).

## What's necessary (hardware)
* I always recommend Raspberry Pi as it consumes only a few watts.
* Make sure to at least use model 3b+. If you don't yet own a Raspi, go for Raspi 4b with at least 2 GB of RAM (maybe better 4 GB).
* Important is a good power supply. If in doubts use the [official one](https://www.amazon.de/Raspberry-Pi-offizielles-Netzteil-Model/dp/B07TMPC9FG). Better don't use one from an "old cellphone" as it's hard to know if it fits Raspi's needs.
* Raspberrys usually use µSD-card as main-storage. In general, this is fine and tiny-sized as well, but the problem is, that openHAB logs extensively. And unfortunately this is something, that µSD don't like so this probably leads to fast wear. So better use a SSD instead of µSD. Unfortunately, Raspi4b doesn't support to boot from SSD out-of-the-box. Please refer these [instructions](https://kofler.info/usb-boot-fuer-den-raspberry-pi-4/) to know what's necessary to "persuade" Raspi4b to boot from an USB-drive. Trust me: it's really worth it to use a SSD-drive. Especially with a Raspi4b (that provides USB3) it's much much more faster than µSD.
* Good news for people using Raspi3b+: it supports booting from USB-drive out-of-the-box.
## What's necessary (software)
* In order to make use of my config-files you need to have a running openHAB-installation. Mine is running on a Raspberry Pi 4b (4GB Ram) with openHAB3. In general there are two ways to install openHAB:
* [Raspberry Pi OS with manual openHAB-installation](https://www.openhab.org/docs/installation/rasppi.html)
* [openHABian](https://www.openhab.org/docs/installation/openhabian.html). After testing it myself I also recommend to use openHABian as it's much simplier.
* Make sure to choose openHAB3 as openHAB2 will be discontinued mid-term.
* After completing the installation, [UI](http://<ip>:8080) should be browsable. In order to get ESPuino running you need at least the MQTT-binding (Add-ons -> Bindings) and the Map-transformation (Add-ons -> transformations). And you need to setup items, rules and sitemap.
* Beside of openHAB you need a MQTT-broker. You can use a public one but if there's already a Raspberry Pi running with openHAB, it probably makes sense to install [Mosquitto](https://mosquitto.org/) as MQTT-broker in parallel.

## GUI or text?
* When it comes to configuration, there are two possibilities: GUI or txt-Files.
* It seems to be sorta religion of which one to choose :-) However, as of openHAB3, GUI is simplier, but's a lot of stuff to click that would be probably faster to configure as text-file. Refer [this one](https://www.openhab.org/docs/configuration/#textual-vs-graphical-configuration) for further informations.
* Please note: my examples are txt-based and taken from openHAB2. With changing from openHAB2 to openHAB3, I moved over to configuration via GUI. Anyway: the sitemap still needs to be configured as txt-file.
## MQTT
After your MQTT-broker is set up have look at mqttConnections.things in order to configure the MQTTT-connection between openHAB and the broker. In doubt restart openHAB as changes sometimes don't get recognized immediately without restart. If nothing happens have a look at the logfiles /var/log/openhab/openhab.log or /var/log/openhab/events.log. In general, to debug MQTT-stuff, [MQTT fx](https://mqttfx.jensd.de/) is a good tool to refer.

## How does it look like?
Depends on you like it :-) Here's some screenshots of my sitemap-presentation as described in my GitHub-repository.
App's screen when ESPuino is running and playing a music-folder:<br />
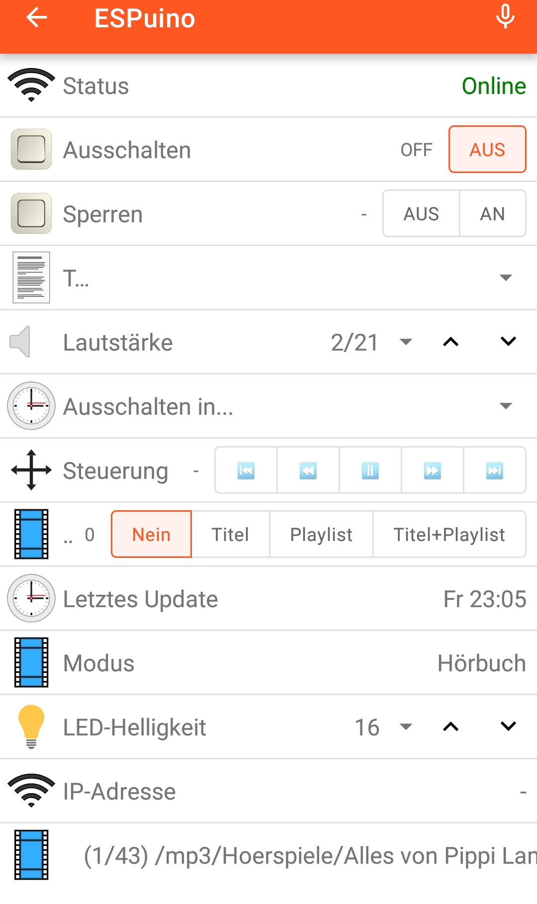
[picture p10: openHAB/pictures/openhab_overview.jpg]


RFID-tags can also be 'emulated' via app. It's not really comfortable, as this list isn't synced with the RFIDs known to ESPuino, but at least it's possible (+handy for a few RFIDs):<br />
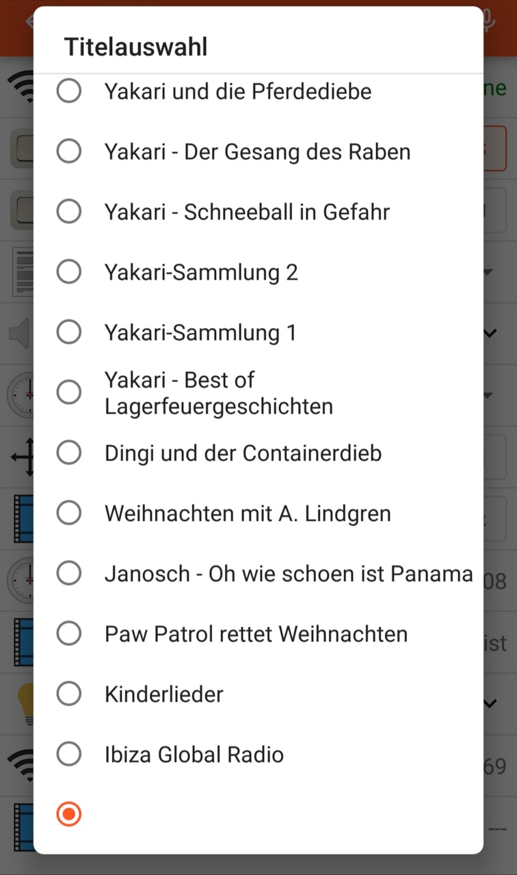
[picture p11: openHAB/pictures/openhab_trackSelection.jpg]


Sleep-timer can be adjusted this way:<br />
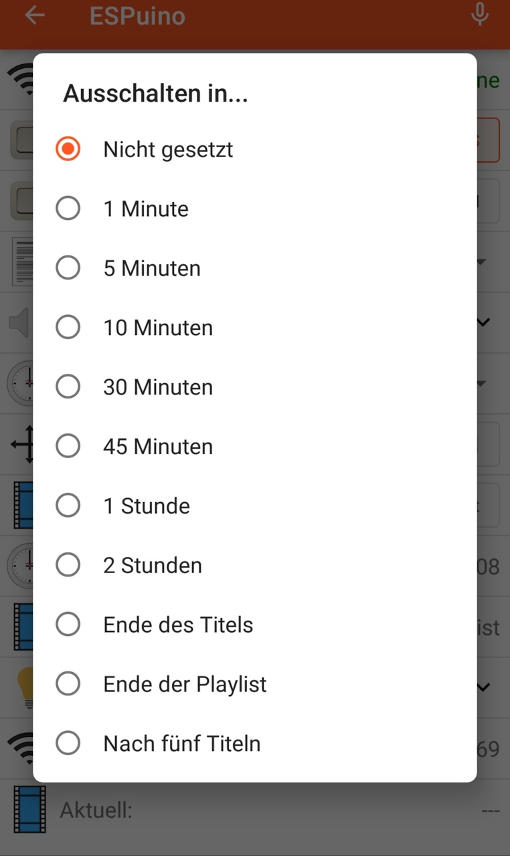
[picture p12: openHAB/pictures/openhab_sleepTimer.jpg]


When ESPuino is not online (doesn't matter if deepsleep or totally powered off):<br />
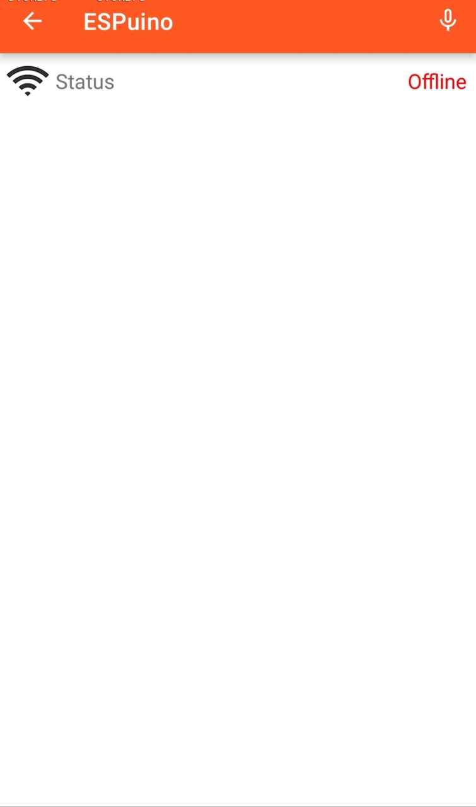
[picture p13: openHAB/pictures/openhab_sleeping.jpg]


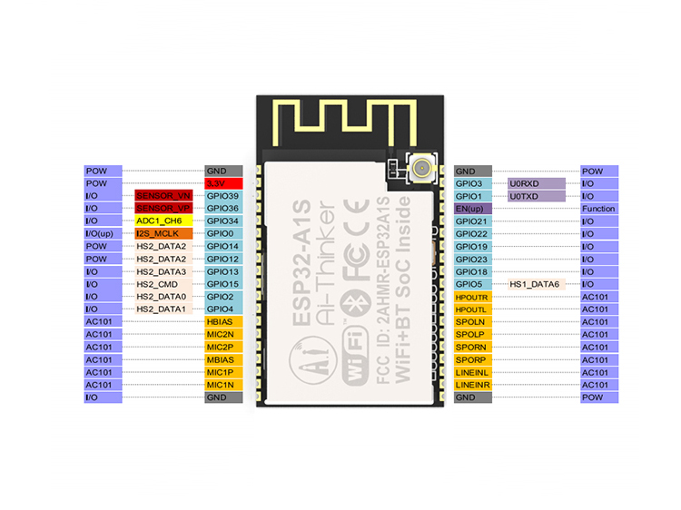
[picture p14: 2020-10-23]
Hardware-Plaforms/ESP32-A1S-Audiokit/docs/ESP32-A1S-Pinout.jpg

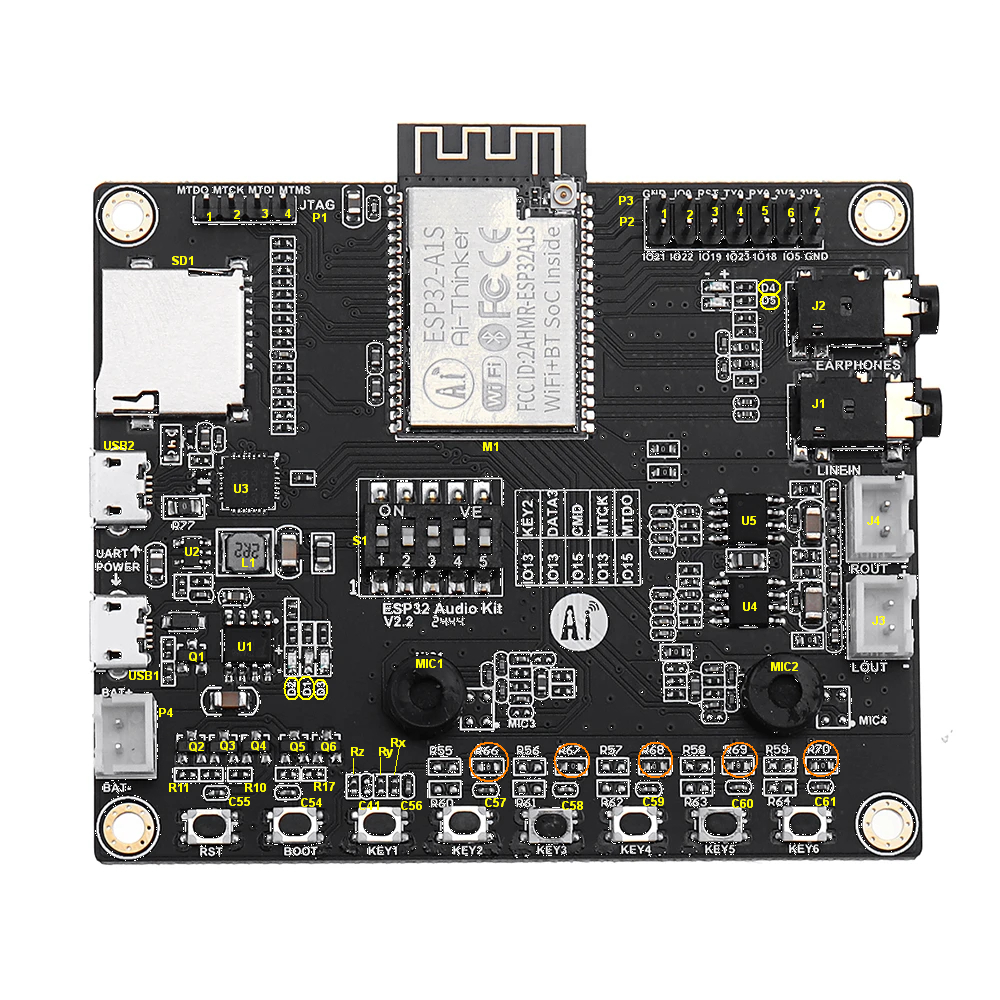
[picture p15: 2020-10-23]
Hardware-Plaforms/ESP32-A1S-Audiokit/docs/ESP32-Audio-Kit2.2 ff.png

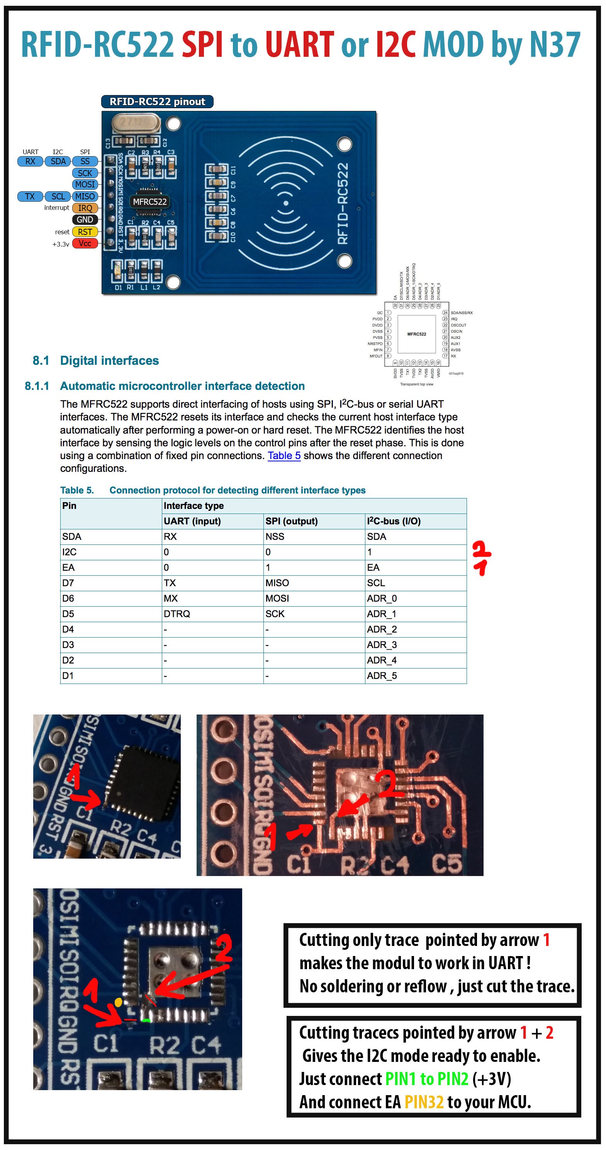
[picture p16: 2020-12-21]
Hardware-Plaforms/MRFC522-RC522-RFID.jpg

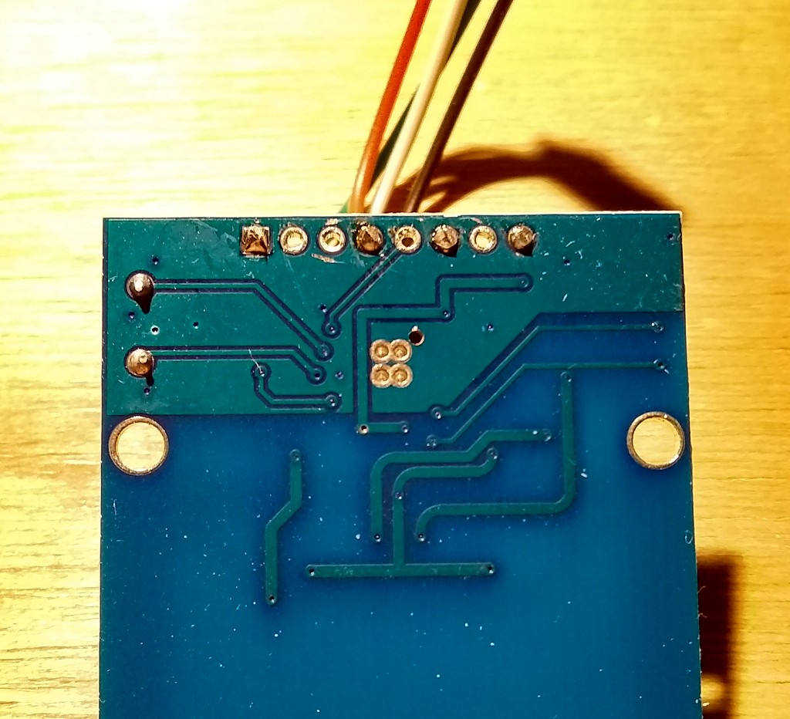
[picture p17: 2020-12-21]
Hardware-Plaforms/drill.jpg

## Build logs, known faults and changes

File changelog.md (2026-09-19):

# Changelog

## DEV-branch

## Version 3.1 (19.09.2026)

* 18.09.2026: Optionally speak a warning when the battery runs low, instead of only blinking the LEDs - nobody looks at the ring while a story is playing. Playback is interrupted for the announcement and resumes at exactly the position it left off, while title, position and progress stay frozen so neither the web interface nor MQTT sees the interruption. Off by default; set it up under General -> Power, ready-made announcements in German, English and French ship in `announcements/` (#463). Idea and discussion: [forum #4766](https://forum.espuino.de/t/ansage-wenn-akku-fast-leer/4766).

* 18.09.2026: Bluetooth: the tab is now a single mode switch (off / headphones / speaker) with a live connection indicator instead of three separate panels, connect and reconnect handling is more robust, and the volume finally reaches Bluetooth headphones - rotary encoder, buttons and web interface now control the headset (#461), thanks to @joker-mik.

* 15.09.2026: Optionally flash all LEDs green when an RFID tag is accepted - visible confirmation that the card was recognized (off by default, General -> LED); so far only modification cards acknowledged themselves. It is hooked to the accepted tag rather than to the reader detecting one, so a card resting on the antenna in "pause when card is removed" mode cannot make the ring flicker.

* 14.09.2026: Add an optional volume limit for night mode: when night mode is switched on, the volume in effect at that moment becomes a temporary upper limit (plus one step of headroom), lifted again when night mode ends - so a player taken to bed cannot be turned up to full blast with the speaker right at a child's ear. A fixed maximum configured up front was the obvious alternative but a poor one, since audiobooks differ so much in loudness that the limit would have to be set very low and then corrected in the web interface all the time. The ceiling is taken once, on activation, and then frozen (letting it follow the volume down would pin you to whatever level you briefly dialled in during a quiet passage), it is never persisted, and it covers every volume source - rotary encoder, buttons, web interface, MQTT and Bluetooth. Off by default; enable it under General -> Options ("Limit volume in night mode"). Along the way night mode moved from `Led.cpp`, where it lived inside `#ifdef NEOPIXEL_ENABLE` and therefore did not exist at all on builds without LEDs, to `System.cpp`; and a latent bug was fixed where night mode and ambient light shared a single saved-brightness slot, so after switching both off again the brightness stayed at the inner mode's level. Also fixes the LEDs jumping back to full brightness when the settings were saved while night mode was active: reloading the settings overwrote the current brightness with the configured initial one, a special case the ambient light already had and night mode never did. Idea and discussion: [forum #4755](https://forum.espuino.de/t/maximale-lautstaerke-im-nachtmodus/4755).

* 14.09.2026: Fix a reboot loop on boards that run the SD card over SPI (e.g. a Lolin D32 pro built before the switch to SD-MMC). FastLED's clockless-SPI backend, enabled unconditionally since May 2025, claims `SPI2_HOST` via its own private bookkeeping - which on those boards is the very same peripheral `SdCard.cpp` already drives as Arduino's `HSPI`. Arduino's SPI implementation writes the registers directly and never registers with the IDF `spi_master` driver, so nothing fails at startup and both end up driving SPI2 at once; as soon as an SD access overlapped an LED refresh the device panicked (`spi_hal_setup_trans` assert, `led_strip_refresh_wait_done` timeouts) and rebooted, with garbled white/yellow output on the LED ring on the way. The SPI backend is now only used when the SD card runs in SD-MMC mode - which is what all three ready-made firmwares build with, so nothing changes for the Complete or the mini4L, while SPI-SD builds fall back to the RMT driver they used before. Reported and confirmed fixed in [forum #4758](https://forum.espuino.de/t/espuino-nach-update-in-reboot-schleife/4758).

* 14.09.2026: Fix the build failing when `MQTT_ENABLE` is disabled in `settings.h`. The `sleep_timer_state` code added on 27.08.2026 landed in the gap between two `#ifdef MQTT_ENABLE` blocks, so `Mqtt_PublishSleepTimerState()` was compiled unconditionally even though the topic constant it publishes on only exists with MQTT enabled (`'topicSleepTimerState' was not declared in this scope`). Affects self-compiled firmware without MQTT only - nothing was broken at runtime, and the ready-made firmwares all build with MQTT. Reported in [forum #4758](https://forum.espuino.de/t/espuino-nach-update-in-reboot-schleife/4758/5).

* 13.09.2026: Web-UI: clicking a help question mark no longer scrolls the page back to the top. The help icons were anchors with `href="#"`; they are focusable via `tabindex="0"` anyway, which is all the focus-triggered popover needs.

* 13.09.2026: Make both seek step sizes configurable in the web UI (Encoder/buttons tab) instead of only at compile time. The **button** seek step (`jumpOffset`, default 30s) was a compile-time constant in `settings.h` with no runtime override, so changing how far "seek forwards"/"seek backwards" jumps required rebuilding the firmware; it is now stored in NVS and adjustable from 1 to 120 seconds. The **rotary** seek step (`rotSeekStep`, default 10s per detent, used when a turn action is mapped directly to seek instead of the seek preview) already existed in the settings API but had no control in the web interface at all, so it could only be changed with a raw REST call - it now has one too (1 to 60 seconds). Both are read per use, so a change applies immediately without a restart. The compile-time knobs are gone: `jumpOffset` and `JUMP_OFFSET_ROTARY` no longer live in `settings.h` (nor in `settings-override.h.sample`) but as internal defaults `SEEK_STEP_BUTTON_DEFAULT` / `SEEK_STEP_ROTARY_DEFAULT` in `values.h`, so nobody is misled into configuring them at compile time. **Breaking for custom builds**: a `settings-override.h` that still defines `jumpOffset` or `JUMP_OFFSET_ROTARY` has no effect any more - set the values in the web interface instead.

## Version 3.0 (07.09.2026)

* 05.09.2026: Make the battery-voltage correction (`offsetVoltage`) configurable in the web UI (General -> Battery) instead of only via `settings-*.h`. The ADC calibration offset was previously a compile-time constant; it is now stored in NVS and adjustable in hundredth-volt steps, positive or negative. It takes effect immediately on save (`Battery_Init()` re-reads it) and the per-board compile-time value is kept as the default fallback (Complete: -0.04 V). Handbook: [Feinjustierung](https://biologist79.github.io/ESPuino-Docs/hardware/aufbau/#nach-dem-zusammenbau-die-feinjustierung).

* 01.09.2026: Add MediaHub - an optional way to manage RFID-tag assignments **centrally** from a small self-hosted server (a Docker container on your own network) instead of configuring each device on SD/NVS individually. A card assigned to a MediaHub server (playmode 18; the assignment stores `mediahub://<host:port>`) fetches its content and playback mode from that server's manifest when tapped and downloads the referenced files to SD on first use, keeping them in sync afterwards (force-refresh, resync-on-change, SHA-256 verification, an LED download animation and SD-full handling); webradio/webstream assignments are supported too. Servers are registered in the web UI (Files/RFID -> MediaHub). The firmware side lives in `src/MediaHub.cpp`; the hub itself runs separately as [ESPuino-Mediahub](https://github.com/biologist79/ESPuino-Mediahub). Details/discussion: [forum #4607](https://forum.espuino.de/t/espuino-mediahub/4607) (#435).

* 28.08.2026: Fix the "sleep after 5 tracks" (EO5T) RFID modification card - it never actually put the device to sleep (it toggled a `sleepAfter5Tracks` flag that `AudioPlayer_Loop()` never reads, while the real "sleep after N tracks" mechanism keys off `playUntilTrackNumber`, only ever set by the MQTT EO5T command) and it was missing from the modification-card dropdown in the web UI entirely. The card now sets `playUntilTrackNumber` like MQTT does and is selectable in the UI; it reports correctly on the `sleep_timer_state` topic (which detects EO5T via `playUntilTrackNumber`). Also fixes `sleep_timer_state` briefly reporting the full playlist length instead of 0 right before an EOP/EO5T timer sleeps.

* 27.08.2026: MQTT: add a live sleep-timer status topic `sleep_timer_state` publishing JSON (`{"mode":...,"remainingMinutes":...,"remainingTracks":...}`) so a home-automation system can show the remaining time/tracks - `mode` is `OFF`/`MINUTES`/`EOT`/`EOP`/`EO5T`, updated once per minute (minute-timer) and on track changes (`EO5T`/`EOP`). A single JSON topic instead of several scalar topics, published non-retained like the other state topics and re-published on reconnect. The existing `sleep_timer` topic is unchanged (backward compatible). Also fixes two `sleep_timer` bugs along the way: reconnect published the internal millis-timestamp instead of the configured value, and cancelling/rejecting a timer published to the wrong topic (`state` instead of `sleep_timer`). Reimplemented from the idea in #446, thanks to @TMHEINE.
* 27.08.2026: Fix MQTT topics using an all-zero MAC (`ESPuino-000000000000`) instead of the real one - the `<MAC>` token in the device id is resolved in `Mqtt_Init()` at early boot, before the WiFi driver is up, and `WiFi.macAddress()` returns zeros until then. `Wlan_GetMacAddress()` now reads the MAC straight from eFuse via `esp_read_mac()`, which is always available and yields the same value; the web interface already showed the correct MAC because it reads it later at request time.
* 16.08.2026: Apply the configured maximum volume (speaker / headphone) immediately after saving instead of only after the next restart - lowering the limit in the web UI now takes effect right away, and a currently-higher volume is clamped down to the new maximum (#454), thanks to @joker-mik.
* 16.08.2026: Web-UI: fix horizontal overflow on narrow/mobile screens - file-selector and submit buttons now stack on small screens (RFID/NVS import and firmware upload), the audiobook auto-save-interval control moves to its own row, and the RFID-assignment list renders better on mobile (#452), thanks to @joker-mik.
* 16.08.2026: Web-UI: show SD-card storage usage (used / total / free / percentage with a progress bar, in decimal MB/GB) above the file browser, refreshed when opening the Files/RFID tab and after file operations; includes DE/EN/FR translations (#451), thanks to @joker-mik.
* 16.08.2026: Web-UI: report settings that block saving instead of failing silently - the general settings form spans several tab-panes, and native validation cannot flag an invalid control on a hidden pane, so Save did nothing and only left a "not focusable" console error. The form is now validated in JS: an error toast names the offending settings and the tab holding the first one is opened so it can be corrected. Hidden sections that don't apply to the device (no LEDs / no battery) are disabled so they no longer block saving either (#449), thanks to @mgoodfellow.
* 16.08.2026: RfidMfrc522: don't treat a corrupted WUPA reply as a removed card in `pauseIfRfidRemoved` mode - only a clean timeout (empty field) now counts toward removal, while a transmission error (parity/CRC out of the reader's ErrorReg - a card did answer, the frame was just mangled by RF noise) no longer does, with a 1.5s no-clean-answer backstop. After a removal the RF field is now cycled so a card that never actually left returns to IDLE and is seen again by REQA, instead of staying invisible until physically re-applied (#448), thanks to @mgoodfellow.
* 13.08.2026: Reduce audio-decode CPU load so buttons/rotary stay responsive with heavy codecs (AAC/m4a) - the decode task shares core 1 with `loop()` (which polls the controls), and a CPU-hungry decoder could starve it, making input sporadic and playback stutter (forum #4675). The audio library's per-sample VU-meter computation is now disabled outright (ESPuino never reads it), and its per-sample IIR tone filter is only enabled while the equalizer is actually non-flat (all gains 0 by default), so the common case runs neither. No functional change; the equalizer re-enables the filter automatically as soon as a gain is set.

## Version 2.10 (11.08.2026)

* 11.08.2026: Fix build failing when `NEOPIXEL_ENABLE` is disabled - `LED_BRIGHTNESS_STEP`/`LED_BRIGHTNESS_MIN` were only defined inside the `#ifdef NEOPIXEL_ENABLE` block in Led.h, but Cmd.cpp references them in the always-compiled `CMD_BRIGHTNESS_UP/DOWN` handler (the LED functions it calls are already no-op stubs without NEOPIXEL). Both constants are now defined unconditionally, so a build without Neopixels compiles again (#453), thanks to @z3ky for reporting.
* 08.08.2026: Enable firmware-update-over-web on the ESP32-S3 devkit - the S3 environment never set a partition table, so it silently fell back to the global `[env]` default (`custom_4mb_noota.csv`): half of the devkit's 8MB flash was unusable and, with a single factory-app and no `otadata`/`ota_0`/`ota_1` partitions, an update over the web interface could never work. The env now uses `custom_8mb_ota.csv` and defines `BOARD_HAS_16MB_FLASH_AND_OTA_SUPPORT`, like the equally-sized `esp32-wrover-devkitc-v4-8mb` board, so "Firmware-Update" no longer answers with "OTA not supported". **Breaking for existing S3 installs**: the partition layout changes, so this build has to be flashed over USB once, and because NVS moves with it the saved settings are reset - back them up via the web interface first.
* 30.07.2026: Fix folder uploads via the web interface flattening their structure - since the switch to raw per-file uploads (#434) each file was stored under its bare name, dropping any subfolders, so a whole folder got "unpacked" into the target directory. The upload now sends each file's `webkitRelativePath` (its path within the selected folder) so the subfolder structure is preserved again; plain single-file uploads are unaffected. Thanks to Jonas1 for reporting.
* 23.07.2026: Add a configurable minimum volume ("Minimal") to the volume settings - the volume can no longer be turned below this floor from any source (rotary, buttons, Bluetooth, web), e.g. so a box can never be accidentally muted entirely. The boot volume (initial or remembered-last) is also raised to the floor if it sits below it. Defaults to 0 (unchanged behaviour); must be lower than both maximum volumes. The runtime clamp already existed but was never wired to a setting; based on the idea in #392, thanks to @lukas227.
* 23.07.2026: Fix "RFID-Karte wurde entfernt" incorrectly triggering a "Playmode kann nicht verändert werden, wenn keine Playlist aktiv ist" error when a card is removed after the playlist has already finished naturally - `pauseIfRfidRemoved`'s card-removed handler in both RfidMfrc522.cpp and RfidPn5180.cpp now only queues the PAUSEPLAY command while a playlist is actually active/paused.
* 23.07.2026: RfidMfrc522: deterministic WUPA/HALT presence poll for `pauseIfRfidRemoved`, replacing the non-deterministic REQA-based removal detection that caused spurious pause/resume flapping on a perfectly stationary card (and, as a result, NVS write wear from repeated position saves and occasional spurious deep-sleep due to desynced play/pause state). Also fixes reassigning a tag via the web UI having no effect until reboot while `pauseIfRfidRemoved` is active - the reader's last-seen-tag cache is now invalidated on every path that changes what a tag means (assign, mod-card, delete, NVS erase/restore) (#413), thanks to @mgoodfellow.
* 23.07.2026: PN5180: deterministic re-reads for a resting ISO-14443 card - poll with WUPA instead of REQA and park read cards in HALT so a stationary card answers every poll instead of only from the IDLE state, plus one silent re-init sweep at the debounce boundary to tell a temporarily wedged reader apart from a genuinely removed card before declaring removal. Fixes the same spurious pause/resume flapping and phantom-removal symptoms as the MFRC522 fix above (#444), thanks to @sadilek.
* 22.07.2026: Fix defensive `strncpy` call for `gPlayProperties.playRfidTag` to reserve space for and explicitly write the NUL-terminator, instead of copying into the full buffer size - not currently exploitable (the source is always a fixed-length RFID tag ID), but matches the pattern fixed for a genuinely unterminated case in #443, thanks to @oberbichler for flagging it.
* 22.07.2026: Fix timer and port-expander ISRs missing `IRAM_ATTR` on Arduino-ESP32 v3 - if either ISR fired while the flash cache was disabled (e.g. during an NVS/flash write), it would crash; the port-expander ISR was the higher risk since it can fire at any time. Both are now unconditionally kept in IRAM regardless of Arduino-ESP32 version (#442), thanks to @oberbichler.
* 22.07.2026: Fix missing NUL-termination when copying a track path from NVS - a stored path of ≥255 characters left the buffer unterminated, risking an out-of-bounds read when passed on to the audio player (#443), thanks to @oberbichler.
* 21.07.2026: Remove compile-time LED/NeoPixel defaults (`NUM_INDICATOR_LEDS`, `NUM_CONTROL_LEDS`, `CONTROL_LEDS_COLORS`, `NUM_LEDS_IDLE_DOTS`, `OFFSET_PAUSE_LEDS`, `PROGRESS_HUE_START`, `PROGRESS_HUE_END`, `ATMO_HUE`, `ATMO_SATURATION`, `DIMMABLE_STATES`, `LED_OFFSET`) - all of these were already fully runtime-configurable via the web interface, the macros only fed the pre-first-save NVS default (now hardcoded, same values as before). `CHIPSET`/`COLOR_ORDER` are unaffected - those are genuine compile-time FastLED template parameters and can't be runtime-configurable. **Breaking for custom builds**: a `settings-override.h` still defining one of the removed macros will silently no longer have any effect - set the value once via the web UI instead.
* 21.07.2026: Web-UI: give settings sliders live value badges and circular +/- step buttons instead of a bare drag handle, and group related settings across all tabs into rounded cards for a clearer, more compact layout.
* 20.07.2026: Make the MFRC522 scan interval a web-UI setting ("MFRC522 Scan-Intervall") instead of the compile-time-only `RFID_SCAN_INTERVAL` - default unchanged at 100ms. A restart is required for a change to take effect, same as the other MFRC522/PN5180-specific settings.
* 20.07.2026: Fix LEDs staying lit forever in deepsleep after `SHUTDOWN_IF_SD_BOOT_FAILS` triggers - the LED task was still running its idle animation when `esp_deep_sleep_start()` was called, and NeoPixels simply hold their last-sent color with no active refresh. Now clears the LEDs before sleeping.
* 20.07.2026: Remove unused compile-time macro `PLAY_MONO_SPEAKER` - mono/stereo playback has long been a runtime web-UI setting only (nothing in the codebase ever checked this macro), so it was dead documentation.
* 20.07.2026: Battery: make automatic shutdown on critical voltage a web-UI toggle instead of the compile-time-only `SHUTDOWN_ON_BAT_CRITICAL` - off by default, same as before for anyone who didn't compile with the flag. **Breaking for custom builds**: a `settings-override.h` still defining `SHUTDOWN_ON_BAT_CRITICAL` will silently no longer have any effect - enable "Bei kritischer Spannung automatisch abschalten" in the battery settings instead.
* 20.07.2026: Remove compile-time toggles `STATIC_IP_ENABLE`, `PLAY_LAST_RFID_AFTER_REBOOT`, `PAUSE_WHEN_RFID_REMOVED`, `DONT_ACCEPT_SAME_RFID_TWICE`, `RESUME_ON_SAME_RFID` and `NEOPIXEL_REVERSE_ROTATION` - these were already fully configurable at runtime via the web interface; the macros only controlled the pre-first-save default (`true` vs `false`) and are now always initialized to `false`. **Breaking for custom builds**: a `settings-override.h` that still defines one of these macros will silently no longer have any effect - enable the corresponding option in the web UI instead. Static IP itself is unaffected, it has been a fully runtime/per-network web-UI setting for a while; the removed macro only fed a one-time migration for pre-multi-network configs.

## Version 2.9 (19.07.2026)

* 19.07.2026: Rotary gestures: add CMD_SEEK_PREVIEW as a second seek variant for "hold button + turn encoder" - turning previews a target position (yellow ring + blue LED cursor) instead of jumping immediately, committing once the encoder is idle for a configurable delay or on release; selectable independently per button/direction alongside the existing immediate-jump seek gesture (#439)
* 18.07.2026: AudioPlayer: opt-in periodic play-position checkpoint for long audiobook chapters - saves progress every N seconds (NVS "savePosIntv", default off) so a mid-chapter power loss doesn't lose up to an hour of progress (#438), thanks to @mgoodfellow
* 18.07.2026: AudioPlayer: fix audiobook resume-seek for CBR MP3s without a Xing/Info header - the audio library's seek-on-connect only works when a nominal bitrate is known; the seek is now deferred until the first stable bitrate reading instead (#437), thanks to @mgoodfellow
* 17.07.2026: "hold button + turn encoder" gestures - holding a configured button while turning the rotary encoder runs that button's assigned action (seek, LED brightness, ...) instead of changing the volume, configurable per button/direction in the web UI (#436), thanks to @mgoodfellow
* 16.07.2026: Tools tab: keep the saved-RFID-assignments List/Export/Erase buttons always visible instead of hiding them (with dangling separator lines) when there are no assignments yet - grey them out and show the assignment count in each button label instead
* 16.07.2026: Explorer file upload: send each file as its own raw (application/octet-stream) request instead of bundling the whole batch into one multipart/form-data POST - no MIME boundary parsing on the ESPuino side, ~450 -> ~650 kiB/s measured (#434)
* 15.07.2026: Wlan/Web/accesspoint: test WiFi credentials live from the setup page - after saving, the box tries them on the station interface while the setup AP stays up, and shows connecting/failed/success right there instead of save -> reboot -> hope (#433), thanks to @mgoodfellow
* 15.07.2026: Bt: small memory tweaks (#427), thanks to @Joe91
* 14.07.2026: Wlan/Web/accesspoint: tell the user WHY a WiFi connection attempt failed (wrong password / network not found / rejected / associated but no IP) instead of a silent retry-then-fallback (#432), thanks to @mgoodfellow
* 14.07.2026: accesspoint: honor browser language and add a language selector, instead of always defaulting to German (#431), thanks to @mgoodfellow
* 14.07.2026: accesspoint: fix the blank save button caused by a locale key renamed during the settings-tabs restructure (#429), thanks to @mgoodfellow
* 13.07.2026: CI: also publish bootloader.bin and partitions.bin per board alongside firmware.bin
* 12.07.2026: Add missing help tooltips across the web UI settings (WiFi, MQTT, FTP, Bluetooth, volume/playlist, LED, sleep/battery) and align tooltip placement next to the field label consistently
* 12.07.2026: GitHub firmware update list: show 10 builds instead of 5, and show the ESPuino commit's description as a hover tooltip on the commit link
* 11.07.2026: Fix intermittent false "card removed" events with PN5180: avoid an unnecessary hardware reset on every poll while a tag is being tracked, clear stale IRQ flags before each ISO15693 inventory poll, switch to a PN5180-Library fork with shorter RF-field/transceive timeouts, and make the removal-debounce configurable in the web UI (General -> RFID-Reader) (#428)
* 11.07.2026: Improve web-upload throughput: disable WiFi power-save and enlarge the TCP receive window during uploads/OTA (~360-400 -> ~430-464 kiB/s measured), restored again afterwards to keep idle power draw low (#416)
* 11.07.2026: Restructure web UI settings tabs: split "General" into focused sub-tabs (Playback, RFID-Reader, Rotary encoder & buttons, LED, Power), add a new "Updates" tab, consistent row layout and left-aligned buttons across WiFi/MQTT/FTP/Bluetooth/RFID-reader, compact button-assignment tables, scrollable RFID assignments modal, and various smaller UX fixes
* 10.07.2026: Automatically derive Software-revision from the Git commit date at build time instead of maintaining it by hand in src/revision.h
* 10.07.2026: Fix connection watchdog false-positive and spurious "action performed successfully" toasts (#426)
* 10.07.2026: Add firmware update from GitHub: list and install the last 5 builds from biologist79/ESPuino-Firmware directly in the web UI, with OTA progress shown on the LED ring
* 10.07.2026: Self-host management webinterface locally (no more CDN dependency) & make AP SSID/password/timeout configurable via the web UI (#417)

## Version 2.8 (10.07.2026)

* 10.07.2026: Fix stack buffer overflow in RfidPn5180_WakeupCheck() when formatting the card UID for NVS lookup (#421)
* 10.07.2026: Fix intermittent boot-hang with PN5180-LPCD enabled by deferring RFID-task start until after peripheral init (#420)
* 09.07.2026: Remove unmaintained MAX17055 fuel-gauge support (MEASURE_BATTERY_MAX17055). Voltage-based battery measurement (MEASURE_BATTERY_VOLTAGE) is unaffected. (#419)
* 08.07.2026: Fix DONT_ACCEPT_SAME_RFID_TWICE / PLAY_LAST_RFID_AFTER_REBOOT in combination with WiFi not yet available
* 25.06.2026: update some libaries and platform (#411), thanks to @Joe91
* 19.06.2026: Feature: ResumeOnSameRFID (#398), thanks to @joker-mik
* 07.06.2026: Memory and stability improvements and more (#407), thanks to @Joe91
* 25.05.2026: Fix broken BT, FTP, support special chars in filesystem (#405), thanks to @Joe91

## Version 2.7 (12.05.2026)

* 08.05.2026: Type to rfid (PN5180, RC522-spi, RC522-i2c is now being autodetected at start (#403), thanks to @Joe91
* 05.05.2026: Add missing mqtt topics in preview of webinterface
* 19.04.2026: improvement to the i18n files (#399)
* 28.03.2026: Bug fix: Suppression of sound artifacts on the speaker during Bluetooth playback (#397)
* 28.03.2026: feature: Atmolight (#393)

## Version 2.6 (28.02.2026)

* 08.01.2026: More flexible MQTT-handling and new MQTT naming scheme (#373)

## Version 2.5 (01.01.2026)

* 01.01.2026: Add bluetooth source connection handling and flushing (#384)
* 01.01.2026: Refactor button handling logic (#387)
* 01.01.2026: Refactor shutdown button logic for clarity (#385)
* 01.01.2026: Simplify channel to bit mapping in Port_ChannelToBit (#386)
* 09.12.2025: Web UI: Allow escape from Bluetooth mode
* 07.12.2025: WiFi / Bluetooth coexistence
* 30.11.2025: Allocate playlist, tasklist in PSRAM if available
* 30.11.2025: Web UI: Show SD card icon and volume label
* 30.11.2025: BT-Source: Allocate ringbuffer in PSRAM to save heap, use lazy initialization
* 26.11.2025: Web UI: Add missing WiFi & BT commands in button command selects
* 24.11.2025: Audio Library Update: Switch to callbacks, restore cover images (#383), thanks to @sfields !
* 24.11.2025: Bugfix crash in BT-Sink mode
* 31.10.2025: Audio_Loop necessary after task removal
* 26.10.2025: Make LFP-voltages default

## Version 2.4.4 (24.10.2025)

* 24.10.2025: Fix: Remove of error indication while track change
* 23.10.2025: New feature: recursive playlists (#381)
* 23.10.2025: Cleanup log messages
* 22.10.2025: Switch to long commit IDs
* 17.10.2025: Regression fix: remove volume-queue from IRreceiver.cpp

## Version 2.4.3 (09.10.2025)

* 08.10.2025: Bump to ESP-IDF 5.5.1
* 08.10.2025: Use importlib instead of setuptools
* 28.09.2025: Update PN5180 lib
* 27.09.2025: Enable firmware builds with BT

## Version 2.4.2 (18.09.2025)

* 16.09.2025: Fix broken Bluetooth headset mode (BT-Source)
* 15.09.2025: Fix "Abspielposition beim Ausschalten merken"

## Version 2.4.1 (14.09.2025)

* 11.09.2025: Update audio-lib and Fast-LED (#375), thanks to @Joe91
* 27.08.2025: support of virtual RFID-Cards in Webserver (#376), thanks to @Joe91

## Version 2.4 (24.08.2025)

* 16.08.2025: Measuring of battery voltage: analogRead() -> analogReadMilliVolts()
* 15.08.2025: Reduce voltage-stepping in webinterface from 0.1 V to 0.05 V
* 13.08.2025: Enforce usage of port-expander for some HALs
* 13.08.2025: No more Audio-Task (#374), thanks to @Joe91 !
* 12.06.2025: Fix compilation error with NEOPIXEL_REVERSE_ROTATION (#369), thanks to @SZenglein !
* 12.06.2025: Clear ping- and trackProgress intervals when websocket reconnects (#368), thanks to @SZenglein !
* 10.05.2025: MQTT: switch from pubsubclient to IDF-MQTT (#363), thanks to @Joe91
* 05.05.2025: Switch DEV-branch to Arduino 3.2.0 (ESP-IDF 5.4.1)
* 30.04.2025: Fix loosing Websocket Ping/Pong connection, thanks to @Joe91 !
* 24.04.2025: Make PAUSE_WHEN_RFID_REMOVED & DONT_ACCEPT_SAME_RFID_TWICE configurable at runtime (#362)
* 18.04.2025: Make MQTT compatible with Arduino 3, thanks to @Joe91 !
* 22.03.2025: Make PLAY_LAST_RFID_AFTER_REBOOT configurable at runtime
* 17.03.2025: Refactor select fields for buttons & modifications, thanks to @trainbird !
* 08.03.2025: Bluetooth: Support avrc (buttons), thanks to @sfields !
* 03.02.2025: ESPAsyncWebServer moved to new location: <https://github.com/ESP32Async/ESPAsyncWebServer>
* 03.02.2025: PlatformIO package 6.10.0 (Arduino 2.0.17, ESP-IDF 4.4.7)
* 28.01.2025: Make led, rotary & button settings configurable at runtime #358
* 27.12.2024: Fix audio dropouts in BT-Source mode
* 27.12.2024: ArduinoJson 7 (#357)
* 18.12.2024: Use saved SSID as LAST_SSID, when no successfull connection was possible #355, thanks to @nona00 !
* 18.12.2024: Check if #POWER defined, thanks to @QDaniel !
* 18.12.2024: Prepare for Arduino 3.1.0
* 16.12.2024: Add verbose log to indicate, that the restart is on purpose (#356), thanks to @thebino !
* 16.12.2024: LPCD: Only wake up if card is present in NVS (#352), thanks to @fox34 !
* 25.11.2024: Moving some settings to the Web UI (#350), thanks to @trainbird !
* 17.11.2024: Simplify 'SdCard_ParseM3UPlaylist' and fix parsing, thanks to @h4kun4m4t4t4 !
* 29.10.2024: Update Audio lib
* 29.10.2024: Enable CONFIG_ESP32_REV_MIN_3 to save some IRAM
* 22.10.2024: Cleaning up `management.html` (#348), thanks to @trainbird !
* 22.10.2024: Update Arduino-IRremote to support the ESP 3.0 core
* 29.09.2024: Removal of support for non-PSRAM HALs (Lolin32, LolinD32, DevkitC) and ESP32-A1S
* 29.09.2024: Prepare for Arduino 3.0.5
* 27.09.2024: PlatformIO package 6.9.0

## Version 2.3 (23.09.2024)

* 19.09.2024: Document the virtual cards in the UI #333, thanks to @caco3 !
* 18.09.2024: Re-designed tools page (#337), thanks to @caco3 !
* 16.09.2024: Fix sleep after playlist not toggling nightmode #336, thanks to @dneukirchen !
* 12.09.2024: PlatformIO package 6.8.1 (Arduino 2.0.17, ESP-IDF 4.4.7)
* 12.09.2024: Change default settings to match "ESPuino-mini 4Layer" board
* 11.09.2024: Fix string's expected length for rfid-cmnd via mqtt
* 11.09.2024: Ignore mqtt messages with length zero
* 10.09.2024: Porting to new web server library completed
* 09.06.2024: Consume about 50% less CPU time in Audio library
* 09.06.2024: Replace 3rd party library toastr (#331), thanks to @trainbird !
* 09.06.2024: Modernized webserver & optimized JSON delivery (#332)
* 20.05.2024: PlatformIO package 6.7.0 (Arduino 2.0.16, ESP-IDF 4.4.7)
* 20.05.2024: Disable bluetooth support for A1S (IRAM too small)
* 09.05.2024: Upgrade to Bootstrap v5.0 + Web-UI Enhancements (#328), thanks to @caco3 !
* 23.04.2024: Enhance UI minification (#323), thanks to @caco3 !
* 22.04.2024: Added virtual RFID-Cards (#319), thanks to @caco3 !
* 18.04.2024: Correct calculation of newFilePos for SEEK_POS_PERCENT, thanks to @sfields!
* 18.04.2024: Correct calculation of gPlayProperties.currentRelPos, thanks to @sfields!
* 18.04.2024: Get title from-VORBISCOMMENT and ID3, thanks to @sfields!
* 18.04.2024: Correct log for SSID name, thanks to @sfields!
* 18.04.2024: Add button to expand/shrink file list (#317), thanks to @caco3 !
* 18.04.2024: Fix remote UI debugging (#316), thanks to @caco3 !
* 14.04.2024: Embed swagger UI #314, thanks to @caco3 !
* 07.04.2024: Equalizer settings to WebUI #313, thanks to @trainbird !
* 28.03.2024: Audio lib, fix a memory leak with flac files
* 28.03.2024: Fix some warnings with upcoming Arduino 3 (ESP-IDF v5.1)
* 16.03.2024: Reduce memory usage by measurement of JSON payload length
* 15.03.2024: MQTT receive: Bug fix and avoid payload copy (#309), thanks to @eikel
* 15.03.2024: Add coverimage support for ogg, vorbis, opus (and some flac), thanks to @sfields !
* 19.02.2024: Add coverimage support for M4A files in Web-UI
* 18.02.2024: Add coverimage support for flac files in Web-UI, thanks to @sfields !
* 15.02.2024: Rework playlist generation (#275), thanks to @laszloh !
* 15.02.2024: Update sorting strings (#306), thanks to @freddy36 !
* 15.02.2024: Set title and navbar heading to hostname (#305), thanks to @freddy36 !
* 15.02.2024: Include mac address in info (#304), thanks to @freddy36 !
* 12.02.2024: Use natural sort (#296), thanks to @freddy36 !
* 09.02.2024: Remove explorerCreateParentDirectories (#301), thanks to @freddy36 !
* 08.02.2024: Remove convertFilenameToAscii (#298), Playlist fixes (#299), thanks to @freddy36 !
* 08.02.2024: Apple touch icon
* 07.02.2024: Fix dangling pointer in explorerHandleFileStorageTask (#297), thanks to @freddy36 !
* 07.02.2024: Reduce WiFi memory consumption (#295), thanks to @laszloh !
* 05.02.2024: Increase JSON buffer for /debug endpoint
* 02.02.2024: Improve progress calculation/indication, thanks to @freddy36 !
* 01.02.2024: Use NVS interator when reading RFID keys, save 4KB RAM , thanks to @laszloh !
* 01.02.2024: Use dynamically allocated buffer for file upload, save 32KB RAM , thanks to @laszloh !
* 30.01.2024: Add French Language (#292), thanks to @damda58 !
* 30.01.2024: Fix some audio dropouts with high-quality OPUS files
* 30.01.2024: Keep original mtime for gzip compressed files, avoiding uneccesary Web.o rebuilds (#293), thanks to @freddy36 !
* 23.01.2024: Updated documentation on LPCD setting, thanks to @derpicknicker1 !
* 21.01.2024: Build (tag 2.2) is broken when NEOPIXEL_ENABLE is not set #289, thanks to @RolinBert !
* 21.01.2024: PN5180: Save about 500 Bytes of RAM

## Version 2.2 (17.01.2024)

* 14.01.2024: Modify CMD_DIMM_LEDS_NIGHTMODE to toggle night light mode (#287), thanks to @laszloh !
* 11.01.2024: More free heap on boards with PSRAM (CONFIG_SPIRAM_MALLOC_ALWAYSINTERNAL)
* 10.01.2024: LPCD for ISO-15693 cards
* 05.01.2024: REST-API specification, thanks to @pauel !
* 02.01.2024: Partly revert: Fix webstream playlist abort when track fails (#285), thanks to @sfields !
* 02.01.2024: Show critical voltage slider only if SHUTDOWN_ON_BAT_CRITICAL defined
* 29.12.2023: Show station logo in Web-UI (if available)
* 29.12.2023: /rfid endpoint: List all assigned nvs entries (#280)
* 29.12.2023: Enhanced capabilities for task runtime debugging
* 28.12.2023: Bugfix 1: DONT_ACCEPT_SAME_RFID_TWICE_ENABLE and web frontend, thanks to @sfields !
* 28.12.2023: Add configuration for critical (shutoff) voltage in Web-UI, thanks to @SZenglein !
* 28.12.2023: New official PlatformIO package 6.5.0 (Arduino 2.0.14, ESP-IDF 4.4.6)
* 28.12.2023: Improve port expander handling (#283), thanks to @r-schmidt !
* 23.12.2023: Update audio library, avoid waiting in i2s_channel_write() to have more time in other tasks #636
* 22.12.2023: Web-UI: Preselection of root folder after load to avoid nasty warning when uploading files
* 17.12.2023: Update audio library, fixes click-noise seeking in file
* 13.12.2023: Immediately go to sleep if battery is critical (#274), thanks to @SZenglein !
* 12.12.2023: Long press behaviour, execute cmd directly after longpress-time (#279), thanks to @Joe91 !
* 12.12.2023: Fix false-positive error (Audio playback timeout)
* 10.12.2023: Distribute vTaskDelay() in main loop to avoid rare audio dropouts
* 10.12.2023: Fix wrong states on PE output pins (and SD-card failure on restart) #278, thanks to @36b6fp6s !
* 09.12.2023: Fix webstream playlist abort when track fails (#276), thanks to @laszloh !
* 07.12.2023: Show RC522 firmware version at startup, same as PN5180
* 04.12.2023: fix stuttering sound with some WAV & MP3 files, thanks to @wolle !
* 04.12.2023: change trackprogress communication from websocket to http to improve stability
* 04.12.2023: Remove some convertAsciiToUtf8() #272
* 30.11.2023: Fix a nullptr access after trying to replay an invalid filename (#271), thanks to Olaf!
* 29.11.2023: Updated audio library to play more MP3s, faster track change & delivery of the cover image
* 25.11.2023: Save some cpu time in audio task by only updating the playtime statistics every 250ms
* 22.11.2023: Web-UI: Search for files feature #268
* 21.11.2023: New command CMD_TOGGLE_MODE to switch Normal => BT-Sink => BT-Source
* 21.11.2023: Bugfix: Some commands e.g. Play/Pause did not work in BT-Source mode
* 21.11.2023: Faster pairing animation in BT-Source mode to better distinguish between the two BT modes
* 19.11.2023: Give audiotask a higher task priority, fixes crackling sound
* 19.11.2023: bugfix_same_rfid_twice init #262, see Github comments
* 17.11.2023: Show track progress, current playtime & duration in web-ui (#267)
* 16.11.2023: Fix delay with getLocalTime()
* 14.11.2023: Multi Wlan improvements (#266), thanks to @laszloh !
* 13.11.2023: Update third party libraries
* 08.11.2023: Fix HTML syntax errors, found with static code analysis tool "HtmlHint"
* 08.11.2023: Better logging for boards without PSRAM, fewer logs when compiling with NO_SDCARD
* 07.11.2023: Set timezone after startup, thanks to @Joe91 !

## Version 2.1 (07.11.2023)

* 04.11.2023: LPCD: wakeup check for ISO-14443 cards also with IRQ connected to port-expander
* 04.11.2023: Bugfix for showing wrong loglevel
* 03.11.2023: Web-ui: Fix overlapping info/log after pressing refresh button
* 01.11.2023: Fix folder upload with special chars & playtime formatting
* 31.10.2023: Code Formatting via clang-format #264, thanks to @laszloh & @fschrempf !!
* 27.10.2023: PlatformIO package 6.4.0, Arduino version stays at 2.0.11
* 26.10.2023: LPCD, RFID_IRQ on port-expander: fix compiler warning
* 26.10.2023: portTICK_RATE_MS is deprecated, use portTICK_PERIOD_MS instead (<https://github.com/espressif/esp-idf/issues/51>)
* 26.10.2023: Cppcheck: Fix some warnings/hints
* 22.10.2023: Bugfix PortExpander: beginTransmission()/endTransmission() must be balanced
* 21.10.2023: Enhanced logging: Show Loglevel
* 14.10.2023: New define NO_SDCARD, enable to start without any SD card, e.g. for a webplayer only.
* 05.10.2023: Enable "Arduino as component" by default
* 02.10.2023: Optimize Arduino as component (Disable BLE, BT-HFP & SPI ethernet)
* 25.09.2023: Handle unicode characters in NVS backup, write UTF-8 BOM in backup.txt
* 23.09.2023: Fix some log messages, update FTP & A2DP libraries
* 22.09.2023: Bugfix_same_rfid_twice init (#262) - Thanks to @Joe91 !!
* 06.09.2023: Arduino as component #261 - Thanks to @Joe91 !!
* 01.09.2023: Regression: start an initial WiFi scan on startup, fix redirect to captive portal
* 31.08.2023: Show nvs rfid assignments in web-ui & allow to delete single tags
* 31.08.2023: invoke "/rfid" endpoint (#260)
* 22.08.2023: Unify endpoints for accesspoint.html/management.html (#258)
* 15.08.2023: Web-ui: Change /restart endpoint to POST, refresh button for info & log modal
* 12.08.2023: Web-ui improvements
* 08.08.2023: check & avoid excessive "PING" calls from web-ui
* 08.08.2023: Configurable volumecurve #256, thanks to @Niko & @Wolle
* 08.08.2023: Refactor "/info" endpoint to make frontend/backend more independant #257
* 07.08.2023: LOG message for starting mDNS service
* 04.08.2023: Support for .oga audio files (Ogg Vorbis Audio container)
* 04.08.2023: Web-UI: Replace the template processor (#253)
* 02.08.2023: Bugfix M3U-playlist + PREVIOUSTRACK, thanks to @Niko!
* 31.07.2023: Restart system: avoid peripheral power down while restarting
* 31.07.2023: increase stacksize for audio-task (audio-streams with SSL)
* 22.07.2023: New command CMD_TELL_CURRENT_TIME for announcing the current time
* 21.07.2023: Show overall playtime total in web-ui
* 21.07.2023: Refactor shutdown procedure, add new command CMD_RESTARTSYSTEM
* 20.07.2023: Allow to configure the timezone in settings.h
* 19.07.2023: Show received timestamp of NTP request in log
* 11.07.2023: Fix regression, SD-card was not working in SPI mode
* 09.07.2023: New ftp server by peterus #254. Thanks to @Joe91 for contribution !!
* 08.07.2023: Allow to compile without SD-card (webplayer only)
* 04.07.2023: fix volume jumping at startup when initVolume <> factory default (3u)
* 29.06.2023: Update PN5180 library to fix compilation with DCORE_DEBUG_LEVEL=5
* 25.06.2023: Some spelling corrections, thanks to @SciLor !
* 23.06.2023: CMD_TELL_IP_ADDRESS: IP as text (replace thousand separator with word "point")
* 23.06.2023: web-upload improvement (#249). Thanks to @Joe91 !!
* 23.06.2023: Refactor web: Move dependant html-code from web.cpp to management.html (#250)
* 20.06.2023: PlatformIO package 6.3.2
* 20.06.2023: Move ScanWiFiOnStart to global WiFi configuration (#248)
* 18.06.2023: Stricter hostname validation (#246). Thanks to @SZenglein !!
* 18.06.2023: Some Web-UI improvements (#247)
* 17.06.2023: CMD_TOGGLE_WIFI_STATUS: Escape from BT-mode, WiFi cannot coexist with BT and can cause a crash
* 13.06.2023: Bluetooth configuration tab in web-interface (#244)
* 13.06.2023: Introduce new playmode "RANDOM_SUBDIRECTORY_OF_DIRECTORY_ALL_TRACKS_OF_DIR_RANDOM"
* 07.06.2023: Use bssid to connect to best WIFI and added option to always perform a WIFI-scan #241
* 06.06.2023: List available WiFi's in accesspoint view
* 06.06.2023: Remove support for Arduino 1.0.6 & playlist cache
* 05.06.2023: FastLED 3.6.0, PlatformIO package 6.3.1
* 01.06.2023: Improve neopixel display in Bluetooth speaker mode (BT-Sink) (#239)
* 01.06.2023: Reduce floating the log with redundant RSSI-messages: Log RSSI value only if it has changed by > 3 dBm
* 31.05.2023: Wifi: Log BSSID in scan and connection success, Wifi fixes (#240)
* 26.05.2023: Fix compiler warnings if MQTT_ENABLE is not defined
* 26.05.2023: Error in log: `[E][Preferences.cpp:96]` remove(): nvs_erase_key fail
* 23.05.2023: Migration from single-wifi setup: Initialize "use_static_ip"
* 22.05.2023: DEV branch has stricter compiler rules, fix some of (mostly harmless) warnings
* 22.05.2023: BTSource: fix Stack canary watchpoint triggered (BtAppT)
* 19.05.2023: Show Arduino version at startup & in web-info
* 19.05.2023: Add support for saving multiple wifi networks (#221)
* 09.05.2023: Bluetooth.cpp: Fix logging crash in sink mode (#238)
* 06.05.2023: README.md: Improve formatting, style, language and content
* 03.05.2023: Add support for control LEDs to be connected at the end of the NeoPixel Ring (#198)
* 27.04.2023: Remove usage of pgmspace.h header
* 27.04.2023: Move message formatting into LogMessages
* 26.04.2023: Configure button with active HIGH
* 20.04.2023: Speedup playlist generation & file listing by factor > 20
* 14.04.2023: Removing HAL for ESPmuse (stale development)
* 12.04.2023: Restrict value ranges to guard array access
* 11.04.2023: Merge pull request #226 from fschrempf/bugfix_rfid_assign
* 08.04.2023: Enforcing uniform codestyle
* 08.04.2023: Allow to escape from bluetooth mode with an unknown card, switch back to normal mode
* 03.04.2023: Merge pull request #223 from laszloh/bugfix/snprintf_warning, fix for snprintf trunctation warnings
* 03.04.2023: Add missing translations
* 31.03.2023: build.yml: Trigger workflow for all branches
* 27.03.2023: Merge pull request #219 from laszloh/feature/modern_cpp
* 25.03.2023: Transition to c++17
* 24.03.2023: Lost feature „PLAY_LAST_RFID_AFTER_REBOOT“
* 23.03.2023: Change volume animation to triggered mode
* 22.03.2023: Merge pull request #215 from fschrempf/execute-commands
* 22.03.2023: Change rotary encoder to delta mode
* 22.03.2023: Fix errorous indicator in case no audio is playing
* 22.03.2023: Fix for stuck LED-Shutdown animation
* 21.03.2023: Pause some tasks for speedup & smoother HTTP upload
* 21.03.2023: Feature: command-execution on control-site of webserver
* 21.03.2023: Merge pull request #210 from fschrempf/led_rework_cleaned_frieder
* 21.03.2023: Set default environment to arduino2 on dev-branch
* 18.03.2023: Bugfix: Corrupted files after HTTP-upload
* 18.03.2023: Major rework of LED animation task
* 13.03.2023: Fix for playing files via Web-UI for Arduino >=2.0.5
* 13.03.2023: Fix captive portal, Add fallback text AP setup
* 10.03.2023: Merge pull request #204 from laszloh/bugfix/heap_handling
* 10.03.2023: Always free playlist memory when SdCard_ReturnPlaylist is called
* 10.03.2023: Fix heap corruption due to insufficent memory allocation
* 10.03.2023: Harmonize return value of SdCard_ReturnPlaylist
* 10.03.2023: Correct the name of the "sort" function to randomize
* 10.03.2023: Create DEV(eloper) branch

## Version 1

* 22.04.2021: Introduced refactoring-branch
* xx.05.2021: Fixing/stabilizing code
* 08.06.2021: Added global support for PA/HP-enable
* 15.06.2021: Added interrupt-handling to PCA9555
* 22.06.2021: Changed ESP32's partition-layout in order to provider bigger NVS-storage
* 30.06.2021: Added directive `CACHED_PLAYLIST_ENABLE` for faster playlist-generation
* 08.07.2021: Added support to monitor WiFi's RSSI
* 09.07.2021: Making branch `refactoring` the the master
* 09.07.2021: Making master the new branch `old` (not maintained any longer!)
* 13.07.2021: Adding OTA-support via webGUI
* 23.07.2021: Adding new playmode: from local .m3u-file (files or webstreams)
* 30.09.2021: Added feature `PAUSE_WHEN_RFID_REMOVED` for RC522 after having it already for PN5180 (thanks @elmar-ops for contribution)
* 27.10.2021: Added feature `SAVE_PLAYPOS_BEFORE_SHUTDOWN`. When enabled last playposition for audiobook is saved when shutdown is initiated. Without having this feature enabled, it's necessary to press pause first, in order to do this manually.
* 28.10.2021: Added feature `SAVE_PLAYPOS_WHEN_RFID_CHANGE`. When enabled last playposition for audiobook is saved when new RFID-tag is applied. Without having this feature enabled, it's necessary to press pause first, in order to do this manually.
* 13.11.2021: Command `CMD_TELL_IP_ADDRESS` can now be assigned to buttons in order to get information about the currently used IP-address via speech.
* 29.01.2022: Directive `INVERT_POWER` can now be used it invert power-GPIO. And port-expander can now be used for power.
* 28.02.2022: Directive `MEASURE_BATTERY_MAX17055` added. Provides support for [MAX17055](https://www.maximintegrated.com/en/products/power/battery-management/MAX17055.html).
* 31.08.2022: Directive `DONT_ACCEPT_SAME_RFID_TWICE` added. Blocks unwanted reapplies of the same rfid-tag (in case it's not a modification-card or rfid-tag is unknown in NVS).
* 02.10.2022: ESPuino is now able to stream audio to external BT-devices. This is currently in testing. Big thanks to @tueddy for providing this feature!
* 18.10.2022: New playmode: pick random subdirectory of a given directory and play it's content alphabetic ordered
* 08.01.2023: New feature: `PAUSE_ON_MIN_VOLUME`. Playback is paused automatically if volume reaches minVolume (usually 0).

## Old (monolithic main.cpp)

* 11.07.2020: Added support for reversed Neopixel addressing.
* 09.10.2020: mqttUser / mqttPassword can now be configured via webgui.
* 16.10.2020: Added English as supported lanuage.
* 01.11.2020: Added directive `SD_NOT_MANDATORY_ENABLE`: for debugging puposes SD can be bypassed at boot.
* 17.11.2020: Introduced a distinct volume for headphone for optional headphone-PCB.
* 20.11.2020: Added directive `MEASURE_BATTERY_VOLTAGE`: monitoring battery's voltage is now supported.
* 25.11.2020: WiFi can now be enabled/disabled instantly by pressing two buttons.
* 28.11.2020: Battery's voltage can now be visualized by Neopixel by short-press of rotary encoder's button.
* 28.11.2020: Added directive `PLAY_LAST_RFID_AFTER_REBOOT`: ESPuino will recall the last RFID played after reboot.
* 05.12.2020: Added filebrowser to webgui (thanks @mariolukas for contribution!)
* 05.12.2020: Moved all user-relevant settings to src/settings.h
* 06.12.2020: Added PCB for Wemos Lolin32
* 08.12.2020: Reworked MQTT-timeout-Management
* 09.12.2020: mDNS-feature added. If ESPuino's name is "ESPuino", you can use `ESPuino.local` instead it's of IP-address.
* 11.12.2020: Revised GUI-design (thanks @mariolukas for contribution!) + (untested) PCB added for Wemos Lolin D32 + gerberfiles for headphone-PCB
* 18.12.2020: Added SD-MMC 1 Bit-mode (`SD_MMC_1BIT_MODE`). This mode needs one GPIO less and provides almost doubled speed (compared to SPI) for FTP-transfers (thanks @tueddy for contribution!)
* 18.12.2020: Added support for RFID-reader PN5180 (`RFID_READER_TYPE_PN5180`). PN5180 has better RFID-range/sensitivity and can read ISO-15693 / iCode SLIX2-tags aka 'Tonies' (thanks @tueddy for contribution!)
* 20.12.2020: Due to memory-issues with webstreams, FTP needs to be activated by pressing pause+next-button now
* 23.12.2020: User-config is now split into general part (settings.h) and develboard-specific part (e.g. settings-lolin32.h)
* 13.01.2021: Added fileexlorer to webgui (thanks @grch87 for contribution!). Now files and directories can be renamed, uploaded and deleted via webgui.
* 17.01.2021: Added directive `STATIC_IP_ENABLE`: (optional) static IPv4-configuration
* 18.01.2021: Added directive `PN5180_ENABLE_LPCD`: awake from deepsleep with PN5180 is now possible (but needs another GPIO)
* 25.01.2021: Added directive `USE_LAST_VOLUME_AFTER_REBOOT`: Remembers volume used at last shutdown after reboot. This overwrites initial volume from GUI.
* 28.01.2021: Removed cached RFID-filebrowser and replaced by realtime-browser
* 01.02.2021: Introducing PCB: Lolin32 with SD_MMC + PN5180
* 06.02.2021: German umlauts now supported. When uploading via FTP make sure to change charset to CP437.
* 09.02.2021: Added support for bluetooth-sink (a2dp). Thanks @grch87 & @elmar-ops for providing this feature!
* 25.02.2021: Added support for dynamic button-layout. Rotary-encoder is now optional and up to five buttons can be used.
* 25.02.2021: Actions can be freely assigned to buttons (multi-button, single-button (short), single-button (long))
* 25.02.2021: Added support for webcontrol: basic control (volume, play/pause, next, previous, first, last track) can now be controlled via webgui.
* 25.02.2021: Added support for .m4a and .wav-files.
* 26.02.2021: Shutdown via webgui is now available.
* 05.03.2021: Added support for remote control via infrared. Make sure to enable `IR_CONTROL_ENABLE` to use this feature and don't forget to assign corresponding rc-commands of *your* remote control to actions.
* 19.03.2021: Added support for port-expander PCA9555. Can be used for everything, that is "button-like": buttons, headphone-detect, PN5180.IRQ.
* 28.03.2021: Added support for fileseek. With commands `CMD_SEEK_FORWARDS` and `CMD_SEEK_BACKWARDS` it's possible to jump a number of seconds defined in `jumpOffset`.
* 30.03.2021: Added support for stereo/mono via `PLAY_MONO_SPEAKER`. If active, mono is used while headphones remain stereo (if `HEADPHONE_ADJUST_ENABLE` is active).
* no more updates will follow!

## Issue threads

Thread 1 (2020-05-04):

RC522 very slow / unresponsive with this code

georg90, 2020-05-04:
Hi! First of all - great job! I was looking for adding FTP support to the Tonuino project when I found your repo, thanks for the great documentation.
I really like the way of handling audio on the esp rather than using the dfplayer.

When trying out your image, I noticed that the RFID reader is quit slow / doesn't pick up cards as easy as with sample code from the repo.

I changed cables etc, but when I use a basic sketch to try out the chip, it works as supposed.

I had a quick look at your code and couldn't find a delay other than the 300ms in line 1467.

Since I am not too much into the library for the RC522, my fist guess is, that line https://github.com/biologist79/Tonuino-ESP32-I2S/blob/bfb8d81af2914f16de721057272625c5ad056082/src/main.cpp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 will check for a new card. If I hold the same card, it will not trigger. However, if I try three different tags, all not known to the device, it will only pick up 1 of them instantly. Sometimes it helps to hold the card above or underneath the device, however it picks them up rather slow..

I will investigate further, maybe others have the same issue and we can exchange ideas here. Thanks!

biologist79, 2020-05-05:
Thanks for your feedback!

Did this coding-part in the very beginning of my project. When I remember right my goal was to eliminate issues with triggering "new card present" too many times at once. However, try to set it to 1 ms and see, if it fits your needs.

Anyway, I'm aware there's a fork that was especially made for changing rfid-behaviour in the way that music stops, when the card is removed (https://github.com/mcgreg1/Tonuino-ESP32-I2S/blob/master/src/main.cpp#L1573). As it seems he has reduced the "rfid-debounce" to 100 ms as well.

georg90, 2020-05-06:
It's better now. Thanks for the hint ;-) 100ms seems to help.

I will create a fork and upload my code at some point. Maybe its helpful (I added remote debugging and changed the button logic to my needs. and a few other things)

Closed 2020-05-06.

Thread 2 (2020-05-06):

Feature: Add Audio Feedback

georg90, 2020-05-06:
Hi again.
I am currently trying to implement audio feedback. So e.g. when the box starts, next track etc. there is also a voice output.

Currently I see two options:
1. Working with the Queue system in place (drawback: When interrupting a queue (=playlist) we loose the state of where we where.
2. Have an independet implementation that handles audio feedback.

I like option 2, I tried option 1 and it breaks the playlist, when being used within a queue being played. For option 1 I am currently missing more information on how the MAX device and the I2S protocol is designed. Can we have a parallel connection ? Or how can we enable sound output while keeping te queue structure in place?

Any ideas welcome.

Thanks a lot.

biologist79, 2020-05-07:
One thing first: Is it really necessary to give an audio-feedback? Just asking because what I personally like more or less the most about my tonuino-project is the Neopixel So I ended up in showing some informations using leds. Don't want to say your way is wrong, just want to make sure you gave it a thought So for jumping to the first or last track there's already an animation available.

However, regarding your questions...
I2S: Just had a look at Espressif's specs and they say "ESP32 contains two I2S peripherals. These peripherals can be configured to input and output sample data via the I2S driver.". So at least in theory it should be possible to run two instances in parallel. You could try to use a second instance of the audio-library used but I don't know if there's enough global memory available to do that (was by far the biggest issue I had while developing my fork). If that happens (just as hint) the ESP will end up in a boot-loop. I just mention this as it took me a while to point out the problem. But to be honest I don't know if I2S technically supports such a 2:1-connection. Anyway, I2S seems to be very robust. If you play music for instance and disconnect an I2S-pin, the music is gone (and possibly you hear ugly noises) but after reconnecting music is immediately back. So I cannot answer it - just a few thoughts about it.

Changing playQ later is not easy
1) Guess you already recognized the big array (bit-field) starting at around line 130 that stores all properties of the playlist. I'd enrich this structure by uint8_t specialFileNumber and give it a 4 bit adress-space. As per default it's zero indicating that playing feedback-file is inactive. For states 1-7 I'd reuse what I called track-control (starting at around line 90). So 1 = stop; 2 = play... Additionaly, as you mentioned startup-sound is desired, maybe add an 8th state called startup or so. Next you need an array of char-arrays that contains the special file-names to play - call it maybe specialFiles[]. Make sure to store these char-arrays (strings) in PROGMEM to save memory. Inside there's something like "/mp3/specialFiles/pause.mp3". specialFiles[0] is null. Starting with specialFiles[1] you reuse track-control's numerical logic as this enables you to address this array later simply using the states of track-control.

2) For playAudio() re-use the existing track-control-structure. So for example if pause/play was hit, add a line in the section of pause-handling setting specialFileNumber = PAUSE. Same for next track and so on...

3) Introduce a global if/else-branch to distinguish between "normal play mode" und "special file mode". So if playProperties.specialFileNumber > 0 special-file-handling is called. When playling special file is over give control back to normal play mode by setting playProperties.specialFileNumber back to 0.

Should work this way in general but maybe in detail it's a bit more complicated

Things to mention:

a) For pause/play it's a bit complicated because you have to jump back into the old file at the right position. So you have to make sure to save the current playPosition every time pause/play is pressed. Currently playPosition is only saved in audiobook-mode.
b) Make sure vTaskDelay() is called if no track is played. If you don't do ESP will end up in a crash as the infinite loop will run that fast there's no time left for the ESP to manage other things (Wifi for example).

Hope that helps.

georg90, 2020-05-07:
First of all, thanks for the detailed description and thoughts.
I, too, like the neopixels a lot! However, my enclosure currently doesn't feature LEDs other than for status (on/off). Therefore I'd like to enable audio output for the most basic tasks.

I followed you're approach and got it working (partially).

When the music playback is stopped, I can successfull play the audio commands using this function in `trackQueue`:

```
// Audio feedback handling
            #ifdef AUDIO_FEEDBACK_ENABLE
                if (playProperties.specialFileNumber > 0) {
                  playProperties.trackFinished = false;
                  loggerNl("Handling audio feedback", LOGLEVEL_NOTICE);
                  audio.connecttoSD(specialFiles[playProperties.specialFileNumber]); // this is the array with the path to the mp3
                  playProperties.specialFileNumber = 0; // setting back to default mode
                  audio.loop(); // starting the audio loop
                  vTaskDelay(portTICK_PERIOD_MS*10); // delaying the task to keep esp alive
                }
            #endif
```

When the box is playing, this is firing, too, but nothing is played (no audio output). My assumption is the following track (e.g. the next track) is overwriting the output of the audio. I though this is prevented by using `playProperties.trackFinished = false;` which is set to `true` when `eof_mp3` is called. But it seems this is still continuing and breaking the audio playback when a playlist is there.

biologist79, 2020-05-07:
I guess the problem is that you revert `playProperties.specialFileNumber` back to 0 immediately. Because in this case `audio.loop()` is only called exactly once. But this isn't sufficient as it has to be called on and on until track's end was reached. So make sure to allow this.

Unfortunately the audio-lib used doesn't provide a method that allows checking if music is still playing. Would make things a bit easier but `eof_mp3` works too.

georg90, 2020-05-07:
Yes, I had this in mind and changed it already. But without success.

```
␛[0m(D) Kontroll-Kommando empfangen via Queue: 5
␛[0m(D) Handling audio feedback
␛[0m(D) info        : Reading file: 03_prev_track.mp3
␛[0m(D) info        : file has no mp3 tag, skip metadata
␛[0m(D) info        : stream ready
␛[0m(D) info        : syncword found at pos 0
␛[0m(D) info        : Channels=1
␛[0m(D) info        : SampleRate=44100
␛[0m(D) info        : BitsPerSample=16
␛[0m(D) info        : Bitrate=32000
␛[0m(D) info        : Reading file: Bobo Siebenschl04.mp3 // This is the next file (no eof_mp3 being called)
```

Using this in `eof_mp3`
```
void audio_eof_mp3(const char *info) {  //end of file
    snprintf(logBuf, sizeof(logBuf) / sizeof(logBuf[0]), "eof_mp3     : %s", info);
    loggerNl(logBuf, LOGLEVEL_INFO);
    #ifdef AUDIO_FEEDBACK_ENABLE
        if (playProperties.specialFileNumber > 0) {
            playProperties.specialFileNumber = 0;
        }
    #endif
    playProperties.trackFinished = true;
}
```

It seems the file is not played at all and being overwritten. `eof_mp3` is never called.

georg90, 2020-05-07:
Did some more try/error:

Moved the check up (above `trackQStatus`) and changed the logic to something like this:
```
        // Audio feedback handling
        #ifdef AUDIO_FEEDBACK_ENABLE
            if (playProperties.specialFileNumber > 0) {
              playProperties.trackFinished = false;
              loggerNl("Handling audio feedback", LOGLEVEL_NOTICE);
              audio.connecttoSD(specialFiles[playProperties.specialFileNumber]);
              while(!playProperties.trackFinished) {
                audio.loop();
              }
              vTaskDelay(portTICK_PERIOD_MS*300);
            }
        #endif
```
This works, but the played files are played with a little noice / cut at the beginning and end. Did you experience something like this with the MAX device? The files play fine on my PC. Maybe it's due to only being mono sound files? Longer files play fine..

biologist79, 2020-05-08:
Sounds good :-) Glad to hear my idea works.
Indeed I had such issues but wasn't sure if it's maybe a hardware-issue. To be honest I didn't do more investigastion on it as playing of short files was out of scope for me.

While developing the feature "play whole folder" I used some tiny mp3s in order to save time and doing a sort of stress test. In fact I took some files from the original tonuino-project that are used to spell numbers 1-4. So really short. Do not really remember if it was noisy but at least it was cut.

But yes, maybe mono is the problem, because usually (when I got it right) stereo-files are so to say multiplexed into a single channel. By having only one channel maybe this is an issue.

Regarding noises I recently had a private chat with somebody that reported ugly noises when changing volume fast via rotary encoder. In fact I also discovered this as a little bit of an issue but wasn't really "impressive". However, by reducing gain on the MAX for him it seems to be far better now. Per default it's 9dB and because volume @1 was too lood for me (primary usage is my son's sleeping room) I changed it very early down to 3 dB. So just as hint, don't know if that would things make better for you.

georg90, 2020-05-08:
Thanks again. Gain was something I was thinking about changing anyway. However, a quick test revealed it didn't help in this case.

For everyone ending up here from google etc.

I could "fix" it by adding some silence (50/100ms) in front and the back of the audio track. My files (<2 seconds) play fine now.

I consider this "done" now :)

biologist79, 2020-05-09:
Good job!
Thanks a lot for your reply. Guess this is something I could consider to integrate into my repository as weel.

Closed 2020-05-08.

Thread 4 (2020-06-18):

Board

BluetriX, 2020-06-18:
Hi!

Ist geplant ein Board (PCB) für das Projekt zu machen? Ich habe gerade die Bauteile vor mir aber ich bin erst bei der Hälfte und es sieht schon wüst aus.

Ich könnte ein Board entwerfen und es zur Verfügung stellen.

Könntest du dann den Entwurf checken?

biologist79, 2020-06-18:
Hi,

das ist ein recht komplexes Thema :-)
Auf https://discourse.voss.earth/ gibt es unter 3rd-Party (muss man
allerdings registriert sein und hat dann, weil es eben 3rd-Party ist,
auch nicht sofort Zugriff drauf) einen Thread
(https://discourse.voss.earth/t/esp32-fork-tonuino-mit-i2s-und-smarthome-integration/4973),
den ich im Zuge meiner Softwareentwicklung geöffnet habe. Dort gab es
jedenfalls schon verschiedene Vorstöße von verschiedenen Leuten, die da
was gestartet haben. Ich für meinen Teil habe bisher immer alles auf
einer Streifenraster-Platine aufgelötet, weil ich für eine Entwicklung
zu faul war. Insofern: Ja, da existiert was und grundsätzlich ist es
auch wünschenswert, wenn man das etwas mehr in geordnete Bahnen lenkt,
weil die ganze Theorie dahinter nicht jedermanns Sache ist. Tatsächlich
hat mir ein User netterweise zwei Platinen zukommen lassen für einen
ESP32s mit 38 Pins. Das erwähne ich deshalb, weil ich dabei auch gelernt
habe, dass es unterschiedliche ESP32s gibt (meine haben nur 30 Pins).

Nun ist es aber so, dass verschiedene Leute unterschiedliche
Vorstellungen haben, und insofern gibt es da unterschiedliche
Bestrebungen und Schwerpunkte. Ich will in Kürze einen zweiten Tonuino
bauen, der als Devel-Board einen Lolin32 (Vorgänger vom Lolin D32)
benutzt. Der Grund dafür ist, dass der Lolin32 (und auch der D32)
bessere Festspannungsregler haben (deutlich weniger Stromverbrauch im
Deepsleep) und sich insofern besser für den Akkubetrieb eignen.
Gleichzeitig haben sie auch einen Anschluss für einen LiPo-Akku und eine
dafür integrierte Ladeelektronik. Und nicht zuletzt muss man zum Flashen
keine Taste drücken, was insbesondere deswegen interessant ist, weil man
zum Flashen dann den Tonuino nicht mehr öffnen muss.

Das Ganze bringt nur ein Problem mit sich: Im Akkubetrieb hat man keine
5V mehr zur Verfügung. Für den RFID-Reader kein Problem, der braucht ja
eh nur 3.3V. SD-Kartenleser muss man sich einen passenden besorgen, auch
kein Ding. Der beschriebene DAC kommt auch mit 3.3V aus; passt
ebenfalls. Nur den Neopixel betreibt man dann außerhalb der Spec, weil
der eigentlich für 5V gedacht ist. Aber ich habs mal ausprobiert: Der
läuft auch mit 3.3V. Heißt aber natürlich, dass man die
Transistorschaltung auf 3.3V anpassen muss, was auf jeden Fall andere
Bauteile nötig macht. Ich habe vor einer Weile mal zwei Mosfets
bestellt: NDP6020P und IRF530NPBF. Allerdings habe ich noch nicht
ausprobiert, ob das auch wirklich funktioniert, damit 3.3V zu schalten.

Ansonsten gibts noch Leute, die arbeiten mit einer Powerbank - versorgen
also weiterhin mit 5V. Hier hat man jedoch das Problem, dass diese im
Deepsleep alles abschaltet und man dann schauen muss, wie man sie wieder
aufweckt. Aber auch hierfür gibt es Lösungen (mit denen ich mich im
Detail nicht befasst habe), aber ich fand die Variante mit LiPo direkt
an den Lolin 32 "sexy".

Insofern entwickelt sich das Ganze gerade in verschiedene Richtungen und
ich kann dir leider nix Fertiges präsentieren. Die Lolin32-Variante ist
so gesehen schon bei Entwicklung etwas obsolet, da der Lolin32 halt
durch den Lolin D32 abgelöst wurde (was ich bei Bestellung aber nicht
wusste und jetzt habe ich ihn halt hier). Aber im Endeffekt ändert sich
dadurch nur die Pin-Belegung (nehme ich mal an).

Vielleicht schaust mal in o.g. Forum vorbei im genannten Thread. Da
findest auf jeden Fall mehrere Leute, die aktuell dieses Bestreben
haben.

biologist79, 2020-06-18:
Achso, wenn du was entwickelst und mir zukommen lässt, dann kann ich mir
das natürlich auch gerne mal anschauen.  Aber vielleicht musst du dir
die Arbeit auch gar nicht machen. Denn so, wie ich das Projekt aktuell
beschrieben habe (ESP32s, jedoch 38 Pins), gibt es bereits mindestens
eine fertige Platine.

jobe451, 2020-10-04:
Hallo
Leider scheint der obige Link zum Discourse-Thema nicht mehr zu funktionieren.

Also habe ich habe den Versuch unternommen ein Board zu erstellen:
https://easyeda.com/jobe451/tonuino-esp32-i2s

- ESP 32 DevKitC
https://de.aliexpress.com/item/32950878456.html?spm=a2g0s.9042311.0.0.27424c4dD4RElf
- SD-Card-Reader (Regular und Micro)
https://de.aliexpress.com/item/32523546123.html?spm=a2g0s.9042311.0.0.27424c4dTV2BOP
- Lautsprecher
https://de.aliexpress.com/item/4000103165668.html?spm=a2g0s.9042311.0.0.27424c4dKKr5zp
- Verstärker
https://de.aliexpress.com/item/32999952454.html?spm=a2g0s.9042311.0.0.5e2d4c4de9Tqyo
- RFC Reader
https://de.aliexpress.com/item/32647697060.html?spm=a2g0s.9042311.0.0.5e2d4c4de9Tqyo
- Neopixel
https://de.aliexpress.com/item/32835427711.html?spm=a2g0s.9042311.0.0.5e2d4c4de9Tqyo
- Rotary Encoder:
https://de.aliexpress.com/item/33041814942.html?spm=a2g0s.9042311.0.0.5e2d4c4de9Tqyo

Anmerkungen:
- Ich habe versucht einen Verpolungsschutz einzubauen und dazu auch einen IRF9520 vorgesehen. Ob das so klappt weiss ich nicht, theoretisch, ja - bin da aber ein ziemlicher Amateur.
- Ich plane mehrere Boards zu bauen und dazu reguläre SD-Karten oder Micro-SD-Karten zu nutzen. Entsprechend hat es Anschlussstellen für beide Varianten.
- RFID-Karten, Buttons, Neopixel, usw sehe ich vor mit Dupont-Steckern zu verbinden.

Ein Feedback dazu würde ich sehr schätzen.

biologist79, 2020-10-04:
Hi,

der Link funktioniert schon. Das Problem ist nur, dass man im Forum angemeldet sein muss und selbst wenn man das ist, kriegt man das auch dann nicht gleich zu sehen. Grund hierfür ist, dass mein Entwicklungszweig von dem, was die Urheber des Projektes entwickelt haben, komplett abweicht (teilweise funktionell, aber vor allem von der Hardware und insbesondere der Codebasis). Insofern gilt mein Projekt dort als 3rd-party. Und da sich das Originalprojekt insbesondere auch an Anfänger richtet, wird 3rd-party am Anfang erstmal ausgeblendet, um diese nicht zu verunsichern. Ist ein bisschen schade, aber gut, ich bin dort mit meinem Projekt gewissermaßen nur zu Gast und gebe die Regeln nicht vor.

Zum Rest: Ich schaue mir das heute Abend mal genauer an und gebe dann Feedback. Ich wollte ja selbst schon lange eine solche Platine fertig haben, aber irgendwie ist in den Sommermonaten die große Faulheit eingekehrt :-) Ich habe zwar angefangen einen Plan zu zeichnen, aber als es dann zu konkreten Überlegungen wie Kopfhöreranschluss kam, habe ich es dann erstmal aufgeschoben.

biologist79, 2020-10-04:
@jobe451 Sieht ok aus würde ich sagen. Was ich an deiner Stelle noch einbauen würde, ist eine Reduzierung des Gains (https://cdn-shop.adafruit.com/product-files/3006/MAX98357A-MAX98357B.pdf Seite 28). Weil ich habe die Erfahrung gemacht, dass sonst die 21 Lautstärkestufen im unteren Bereich etwas grob gestuft sind. Oder anders gesagt: Ich konnte manchmal nicht so leise abspielen, wie ich es gerne getan hätte.
Zum Verpolschutz kann ich wenig sagen. Außer, dass ich eine Seite gefunden habe, wo es so beschrieben stand, wie du es gemacht hast.
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
biologist79, 2020-12-04:
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

Oben rechts ist ein Anschluss zur optionalen Kopfhörer-Platine. Diese habe ich hier ja bereits hochgeladen. MAX und SD werden einfach eingesteckt. Hab gerade vorhin gesehen, dass die beiden RFID-Stecker in unterschiedlicher Orientierung hier drauf sind. Aber das kannst du dir ja dann selbst aussuchen, wie rum der Stecker montiert ist :-)

biologist79, 2020-12-04:
Sodele, PCBs kamen eben. Heute Abend wird gelötet und getestet 👍

biologist79, 2020-12-05:
Ich habe irgendwie noch ein Problem mit dem RFID-Reader, das ich mir nicht erklären kann. Da muss ich nochmal schauen. Ansonsten läuft die Platine, nachdem ich den Widerstand am Gate des N-Channels-Mosfets von 4.7 auf 1k reduziert habe. Mir völlig unklar, warum das auf dem Breadboard immer funktioniert hat und eingelötet nicht.

biologist79, 2020-12-06:
So. Hab's hochgeladen. Ich werde demnächst auch nochmal einen PCB mit Lolin D32 machen. Da kann man sich den Spannungsteiler für die Messung der Batteriespannung sparen. Aber das wird ein paar Wochen dauern. Abgesehen von geringfügig mehr Arbeit funktioniert die Lolin32-Lösung aber genauso gut.

tuffelh, 2020-12-07:
Vielen Dank dafür! Gleich bestellt... Dann wird die neue Box noch zu Weihnachten fertig :-D

BluetriX, 2020-12-07:
Vielen Dank für das Bord - wenn ich die Gerberfiles (zip) zu jlcpcb hochlade gibt es keine Vorschau und er möchte die Bordmaße haben. Ich vermute ich mache einfach was falsch. Hast du einen Tipp?

biologist79, 2020-12-07:
Lässt einfach so stehen, wie es ist und klickst auf "Quote now". Danach ziehst du das ZIP-File rein und dann wird das selbst korrigiert.

BluetriX, 2020-12-07:
Ok - hab es nun nochmal genauso gemacht wie vorhin und nun kommt eine Vorschau etc, Vermutlich ein Schluckauf bei JLCPCB vorhin. Danke

biologist79, 2020-12-07:
Ich habe vorhin die Teileliste nochmal aktualisiert. Schaut, dass ihr auch den dort genannten uSD-Leser verwendet, damit auch Pin-Kompatibilität gewährleistet ist. Ich mache die Tage nochmal 2-3 Bilder von einer fertig gelöteten Platine und lade sie hoch.

erniberni, 2020-12-10:
hast du eventuell 1 Platine übrig? Würde meine Erfahrunge natürlich einbringen.
Ich habe heute alles als Kabelverhau aufgebaut, es funktioniert, aber ich denke mit Schrecken an den Einbau in ein Gehäuse

biologist79, 2020-12-10:
Also eine habe ich tatsächlich noch übrig. Schreib mir mal ne Mail an tonuino@ts-cs.de.

biologist79, 2020-12-10:
Eine Sache ist mir im Nachgang jetzt noch eingefallen: Und zwar wäre es ganz nett, wenn man einen Reset-Schalter hätte. Hintergrund ist: Betreibt man den Tonuino nicht im Batteriebetrieb, so kann man im Zweifelsfalle einfach den Stecker rausziehen. Mit Batterie geht das halt nicht. Ich habe mir jetzt für meine eigenen Tonuinos überlegt, dass ich einen Mikroschalter unten oder hinten am Gehäuse platziere und diesen an den Pins EN + GND anschließe. Drückt man das, so startet der ESP neu. Grundsätzlich wäre es natürlich schöner, diese beiden Pins auch auf der Platine zu haben. Ich lade nochmal demnächst eine rev2 hoch, bei der ich das mache. Ist jetzt für die rev1 aber auch kein Beinbruch: Lötet man die Drähte halt an EN + GND mit dran auf der Platine; so mache ich das bei mir jetzt auch.

biologist79, 2020-12-10:
Ich mache das hier jetzt mal zu. Wenn's dazu weitere Anmerkungen/Fragen gibt: Discussions hier habe ich vorhin freigeschaltet.

biologist79, 2020-12-11:
Jungs, ich habe eben eine aktualisierte Version des Lolin32-PCBs hochgeladen. Darin habe ich die eine JST-Buchse vom RFID-Reader rumgedreht, einen Reset-Pinheader hinzugefügt und einen Kondensator. Die Idee mit dem Reset kam mir erst die Tage. Und zwar wenn halt alles eingebaut ist in ein Gehäuse und man den Tonuino im Batteriebetrieb laufen hat, hat man keine Möglichkeit mehr, ihn neu zu starten. Einen Reset kann man erreichen, indem man GND auf EN schaltet. Genau die beiden Pins führe ich auch raus. Dort kann man dann zB einen Mikroschalter anschließen, den man halbwegs versteckt am Gehäuse platzieren kann. Ihr kennt das ja bestimmt von Geräten, die man kaufen kann. Da gibt's dann manchmal auch so kleine Löcher, wo man mit ner Stecknadel oder so rein muss. Also wenn ihr für sowas auch Verwendung habt, dann lötet euch halt einfach an EN und GND einen Draht mit dran und führt es zum Schalter. So mache ich das mit meinen bereits bestückten Platinen jetzt auch.
Den 10 uF-Kondensator habe ich eingefügt, um die Spannungsmessung am Akku ein bisschen zu dämpfen. Habe ich mir beim Platinenlayout von Wemos beim Lolin D32 abgeschaut und es bringt tatsächlich auch was. Also muss man nicht machen, aber es dämpft auf jeden Fall die Schwankungsbreite der Wert. Habe den Kondensator bei mir jetzt einfach an der Unterseite der Platine mit angelötet; fertig.

Closed 2020-12-10.

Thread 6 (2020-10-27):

Files (mp3) are not playing from the beginning.

mariolukas, 2020-10-27:
After a couple of weeks playing with the device i figured out that files don't play from the beginning. Mostly the file starts a couple of seconds after the regular beginning of the file. Sometimes it seems to start somewhere in the middle of the file. The file is ok so far. When i play it on another device it works. This behaviour does not match all my mp3 files. I tried all of the play (audiobook, single track etc.) modes but it occurs in all play modes.

Anybody who can confirm a similar issue?

I am coming to the conclusion that this might be a mp3 encoding issue, cause it works with some of my older files. I am using the suggested hardware components.
Can some people please share some encoding information about the used mp3 files like sample rate etc. That might help debugging the issue.

biologist79, 2020-10-27:
Did you have a look at the debugging-commands at the serial interface? Just asking because it should show some information about at which position the file starts to play. Keep in mind when using audiobook-mode, the last play-position is saved when a new track starts or when you press pause. What you could do else is to have a look at backup.txt. All RFID-assigments/actions are saved there in a template like:
<file/folder>#<startPlayPositionInBytes>#<playmode>#<trackNumberToStartWith>
If <startPlayPositionInBytes> != 0, it won't start there. If in doubts: re-assign/learn RFID-tag to the action indended and check if it's working as expected then.

mariolukas, 2020-10-28:
> Did you have a look at the debugging-commands at the serial interface? Just asking because it should show some information about at which position the file starts to play.

The backup file was ok. Anyway i removed it for having a clean state. I have not selected audiobook-mode now. With a connected serial output i am getting thee following information.

A file that works:
```
info        : End of file test.MP3
eof_mp3     : test.MP3
info        : buffers freed, free Heap: 121696 bytes
info        : Reading file: 002.MP3
info        : MP3Decoder has been initialized, free Heap: 98052 bytes
info        : ID3 version=4
info        : ID3 framesSize=1176
info        : ID3 normal frames
```

A file that dit not work:
'/musik/test/01.MP3' wird abgespielt (2 von 12)
```
info        : stream ready
info        : syncword found at pos 117
info        : syncword found at pos 0
info        : MP3 decode error -2 : MAINDATA_UNDERFLOW
info        : syncword found at pos 0
info        : MP3 decode error -2 : MAINDATA_UNDERFLOW
info        : syncword found at pos 0
info        : Channels=2
info        : SampleRate=44100
info        : BitsPerSample=16
info        : BitRate=128000
```

`MP3 decode error -2 : MAINDATA_UNDERFLOW` shows that maybe something with my files is wrong. I am also wondering why the first sync word is found at pos 117.

biologist79, 2020-10-28:
Could you please this (short) sketch? https://github.com/schreibfaul1/ESP32-audioI2S/blob/master/examples/I2Saudio.ino
Try to play the corresponding file (needs to be hard-coded within the sketch).
However, it's the lib I'm using to decode mp3s.

mariolukas, 2020-10-28:
I solved it. The problem was caused by id3 tags. Especially special chars seem to be a problem. In my case german umlauts (like Hörspiel) caused the issue. Due this issue might be a "hidden" one it should be mentioned in the Readme.md.

biologist79, 2020-10-28:
Hmm, you're right, I should mention this. Indeed I thought I already did, but seems I only did @Tonuino-Forum. But I only knew Umlaute in filenames could lead to problems. Wasn't aware that id3-tag could be critical.
In fact I recently had a problem on my son's Tonuino with mp3s but didn't spend time on it yet. Maybe it's also due to id3-tag. Will have a look.
However, thanks for reporting!

mariolukas, 2020-10-28:
I just created a small bash script for normalising the file names and removing id3 tags. But be careful you should use it on a copy of your original files. This script changes the files and does not create a new copy of it.
It uses find and also depends on [id3convert](http://manpages.ubuntu.com/manpages/bionic/man1/id3convert.1.html) and rename. I think rename is installed by default on most linux distributions. I am using  macos and needed to install the tools with homebrew.

However it is a quick and dirty hack. Maybe it helps other people to prevent a manual renaming procedure.

```
#!/bin/bash

DIR=$1

find $DIR -depth -execdir rename 's/Ä/Ae/g;s/Ö/Oe/g;s/Ü/Ue/g;s/ß/ss/g' "{}" \;
find $DIR -depth -execdir rename 's/ä/ae/g;s/ö/oe/g;s/ü/ue/g;s/\"//g;s/\?//g' "{}" \;
find $DIR -depth -execdir rename "s/\'//g;s/\`//g;s/\'//g;s/\&/und/g;s/\ /_/g;y/A-Z/a-z/" "{}" \;

for file in $DIR/*; do
   #id3info $file;
   id3convert -s $file;
   #id3info $file;
done
```

Closed 2020-10-28.

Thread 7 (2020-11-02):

RC522 via second I2C instance

kkloesener, 2020-11-02:
Hey!
I want to thank you for the great project so far.

I have the ESP32-A1S Audio-Development-Kit here and i want to ask if its not possible to define a second I2C instance to use for the RC522. Personally i dont want to use the neopixel and rotary encoder. There would be enough GPIO for this and some keys to connect (ex: pause/play, next, stop)
Via this I2C there would also be an optional display possible.

This would be a good solution for everyone not willing to solder.

biologist79, 2020-11-02:
Hi,

AFAIK ESP32 is able to handle two i2c-instances. With having one already "fixed" it's necessary to declare a 2nd instance by assigning custom-GPIOs to it. Have to admit didn't test it yet but shouldn't be a big thing. Will give it a try.
But: if you don't want to use a rotary encoder what's your plan to change the volume? :-)

kkloesener, 2020-11-03:
Good Point.
as i wanted to put this in a child-friendly box, my first thought was to leave it at one level - or change via Web.
But when having a i2c I think about capacitive-touches like here: https://learn.adafruit.com/metal-inlay-capacitive-touch-buttons/overview
This way there are nearly no limits and even a "rotary" would be possible.

kkloesener, 2020-11-15:
After some Research i had to buy new RFID-Reader because the "standard" isn't able to communicate via I2C or UART without resoldering the chip :(
i will start testing on this when everything arrives!

kkloesener, 2020-12-27:
Its complete implemented with
#40

joewa, 2021-02-23:
Hey kkloesener!
> Its complete implemented with
> #40

Great! But can you please provide some more details how you got it the RC522 running via I2C with ESP32-A1S?
- Which RC522-board did you end up using with I2C?
- If this (https://www.az-delivery.de/products/rfid-set) is the "standard" you mean, it is not working for me too.
- Finally, what is the wiring for the board?

Here is a snippet of my settings.h:
```
//################## select SD card mode #############################
#define SD_MMC_1BIT_MODE              // run SD card in SD-MMC 1Bit mode
#define SINGLE_SPI_ENABLE             // If only one SPI-instance should be used instead of two (not yet working!) (Works on ESP32-A1S with RFID via I2C)

//################## select RFID reader ##############################
//#define RFID_READER_TYPE_MFRC522_SPI    // use MFRC522 via SPI
#define RFID_READER_TYPE_MFRC522_I2C  // use MFRC522
//#define RFID_READER_TYPE_PN5180       // use PN5180
```

Cheers,
Jörg

kkloesener, 2021-03-16:
Sorry for the delay.

I've used a board like [this](https://www.ebay.de/itm/13-56-MHz-RFID-Module-Card-Reader-Writer-Interface-I2C-IC-Sensor-Form-RC522-Card/172463236773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)
The Board you've mentioned is the "standard". You can use the board, but you need to resolder the Chip or drill a hole through the pcb (https://forum.arduino.cc/index.php?topic=442750.0). I was not successfully with this and ended up with two pcb with each a hole in the Chip :(

I need to check the exact wiring and will post it later

biologist79, 2021-03-16:
@kkloesener In my forum we've a discussing ongoing regarding the board used: https://forum.espuino.de/t/esp32-audio-kit-esp32-a1s/106
As you've been the one to finally integrate my esp32-a1s-"branch" into my main-branch: maybe you'd like to join us :-)

Closed 2020-12-27.

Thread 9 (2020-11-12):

esp32-audio-kit can't mount SD while MFRC is connected and MFRC is not working

eazy, 2020-11-12:
Hi,

thanks for your work getting tonuino running on ESP32-Audio-kit. I followed your instructions but it won't work with the ESP32-Audio-Kit.
The strange thing is, if I put all together with a normal ESP32-dev board everything works fine.

The Problem:
If I start the ESP-Audio-kit while everything is connected, the mount of the SD-Card fails and keeps trying in the loop. If I disconnect the SDA Wire from of the MFRC while the moutloop is running the loop is ending with a mounted SD-Card but RFID doesn't work. The interessting thing is that I don't get a message for the missing MFRC on boot.

If I'm booting the esp32-audio-kit with disconnected SDA wire of the MFRC the SD-Card can be monted on the first try and I get the message "WARNING: Communication failure, is the MFRC522 properly connected?".

In both cases RFID won't work.

What have I done:
I copied the whole content of the Folder "Hardware-Plaforms/ESP32-A1S-Audiokit" to the root folder of the Project and replaced all existing files. In the platformio.ini I removed the rfid lib "https://github.com/biologist79/rfid.git" and added "yveaux/AC101@^0.0.1".

All the rest is done like you discribed, I removed all the resistor for the Keys and solderd miso of the MFRC522 to Pin 7 of the SD-Card reader gpio 2.

Jumpers are set to off/on/on/off/on

Have you done anything else ? because its running fine with a normal esp32 dev board. Or maybe my board is broken!?

thanks

biologist79, 2020-11-12:
Just to make sure: you've been using RFID-Lib located here: https://github.com/biologist79/Tonuino-ESP32-I2S/tree/master/Hardware-Plaforms/ESP32-A1S-Audiokit/lib/MFRC522 ? I did it a bit dirty in platformio: Lib named in platformio.ini was fetched automatically. However, I overwrote it with that one from the link and deactivated this Lib-dep in platformio.ini subsequently.
And did you solder to the correct pin? #7 is, coming from the direction of the JTAG-GPIOs, the 3rd pin.

Have to say sorry that this part of the project is currently not fully integrated into my master-development-branch. There's still an pull-request ongoing but I'll have to test a bit first. Currently it's more proof-of-concept and to be honest I didn't expect people in being immediately interested in it 👍

eazy, 2020-11-12:
wow, that was a fast answer ;-)

Yes, I use the lib https://github.com/biologist79/Tonuino-ESP32-I2S/tree/master/Hardware-Plaforms/ESP32-A1S-Audiokit/lib/MFRC522 with all the other MFRC libs I'm not able to compile the code. Otherwise the code won't work with the normal esp32-dev board.

And the soldering is also correct, I doublechecked all the wiring and connectivity. Thats why I asked for maybe some other change on the board.

biologist79, 2020-11-13:
Hmm, maybe try this "isolated" sketch:

`#include "Arduino.h"
#include "WiFi.h"
#include "SPI.h"
#include "SD.h"
#include "FS.h"
#include "Wire.h"
#include "AC101.h" //https://github.com/Yveaux/AC101
#include "Audio.h" //https://github.com/schreibfaul1/ESP32-audioI2S
#include <MFRC522.h> //https://github.com/madias123/STM32duino-RFID-Mp3-Player/tree/master/3d%20party%20libraries%20(modified)/MFRC522

// SPI GPIOs
#define SD_CS         13
#define SPI_MOSI      15
#define SPI_MISO       2
#define SPI_SCK       14

// RFID
#define MFRC522_RST_PIN                   22
#define MFRC522_CS_PIN                    12
extern SPIClass SPI_MFRC;
MFRC522 mfrc522(MFRC522_CS_PIN, MFRC522_RST_PIN);

// I2S GPIOs, the names refer on AC101
#define I2S_DSIN      25
#define I2S_BCLK      27
#define I2S_LRC       26
#define I2S_MCLK       0
#define I2S_DOUT      35

// I2C GPIOs
#define IIC_CLK       32
#define IIC_DATA      33

// Tasten
// #define BUTTON_2_PIN 13             // shared mit SPI_CS
#define BUTTON_3_PIN  19
#define BUTTON_4_PIN  23
#define BUTTON_5_PIN  18               // Stop
#define BUTTON_6_PIN   5               // Play

// Amp enable
#define GPIO_PA_EN    21

//Switch S1: 1-OFF, 2-ON, 3-ON, 4-OFF, 5-ON

String ssid =     "ssid";
String password = "pwd";

static AC101 ac;
int volume = 40;                                  // 0...100

Audio audio;

//#####################################################################

void setup()
{
  Serial.begin(115200);
  Serial.println("\r\nReset");
  Serial.printf_P(PSTR("Free mem=%d\n"), ESP.getFreeHeap());

  pinMode(SD_CS, OUTPUT);
  digitalWrite(SD_CS, HIGH);
  pinMode(MFRC522_CS_PIN, OUTPUT);
  digitalWrite(MFRC522_CS_PIN, HIGH);
  SPI_MFRC.begin(SPI_SCK, SPI_MISO, SPI_MOSI);
  SPI_MFRC.setFrequency(1000000);
  while (!SD.begin(SD_CS, SPI_MFRC)) {
    Serial.print(".");
    delay(500);
  }

  mfrc522.PCD_Init();
  mfrc522.PCD_DumpVersionToSerial();

  WiFi.mode(WIFI_STA);
  WiFi.begin(ssid.c_str(), password.c_str());

  uint8_t tryCount=0;
  while (WiFi.status() != WL_CONNECTED && tryCount <= 4)
  {
    Serial.print(".");
    delay(500);
    tryCount++;
    if (tryCount >= 4 && WiFi.status() == WL_CONNECT_FAILED) {
      WiFi.begin(ssid.c_str(), password.c_str());     // Workaround for ESP32-bug
    }
  }

  Serial.printf_P(PSTR("Connected\r\nRSSI: "));
  Serial.print(WiFi.RSSI());
  Serial.print(" IP: ");
  Serial.println(WiFi.localIP());

    Serial.printf("Connect to AC101 codec... ");
    while (!ac.begin(IIC_DATA, IIC_CLK))
    {
        Serial.printf("Failed!\n");
        delay(1000);
    }
    Serial.printf("OK\n");

    ac.SetVolumeSpeaker(volume);
    ac.SetVolumeHeadphone(volume);
//  ac.DumpRegisters();

    // Enable amplifier
    pinMode(GPIO_PA_EN, OUTPUT);
    digitalWrite(GPIO_PA_EN, HIGH);

  audio.setPinout(I2S_BCLK, I2S_LRC, I2S_DSIN);
  audio.setVolume(10); // 0...21

  audio.connecttoFS(SD, "/Led Zeppelin - Stairway to heaven.mp3");
//  audio.connecttoSD("/Banana Boat Song - Harry Belafonte.mp3");
//  audio.connecttohost("http://mp3channels.webradio.antenne.de:80/oldies-but-goldies");
//  audio.connecttohost("http://dg-rbb-http-dus-dtag-cdn.cast.addradio.de/rbb/antennebrandenburg/live/mp3/128/stream.mp3");
//  audio.connecttospeech("Wenn die Hunde schlafen, kann der Wolf gut Schafe stehlen.", "de");

}

//-----------------------------------------------------------------------

void loop()
{
    audio.loop();
    if ( ! mfrc522.PICC_IsNewCardPresent()) {
		return;
	}

	// Select one of the cards
	if ( ! mfrc522.PICC_ReadCardSerial()) {
		return;
	}

	// Dump debug info about the card; PICC_HaltA() is automatically called
	mfrc522.PICC_DumpToSerial(&(mfrc522.uid));
}

// optional
void audio_info(const char *info){
    Serial.print("info        "); Serial.println(info);
}
void audio_id3data(const char *info){  //id3 metadata
    Serial.print("id3data     ");Serial.println(info);
}
void audio_eof_mp3(const char *info){  //end of file
    Serial.print("eof_mp3     ");Serial.println(info);
}
void audio_showstation(const char *info){
    Serial.print("station     ");Serial.println(info);
}
void audio_showstreaminfo(const char *info){
    Serial.print("streaminfo  ");Serial.println(info);
}
void audio_showstreamtitle(const char *info){
    Serial.print("streamtitle ");Serial.println(info);
}
void audio_bitrate(const char *info){
    Serial.print("bitrate     ");Serial.println(info);
}
void audio_commercial(const char *info){  //duration in sec
    Serial.print("commercial  ");Serial.println(info);
}
void audio_icyurl(const char *info){  //homepage
    Serial.print("icyurl      ");Serial.println(info);
}
void audio_lasthost(const char *info){  //stream URL played
    Serial.print("lasthost    ");Serial.println(info);
}
void audio_eof_speech(const char *info){
    Serial.print("eof_speech  ");Serial.println(info);
}`

One important thing: RFID-reading takes place too often. This leads the music to sound ugly. Don't worry, it's just normal for this one.

eazy, 2020-11-14:
Thanks for the code. Awsome, Wifi is working, SDCard mounted and the MFRC is also working.

But, Audio isn't good, maybe half of speed an noisy, I will try another MP3 or stream later on.

Thanks I'll know going for debugging ;-)

eazy, 2020-11-14:
lol .... I've just seen your last sentence ;-) so everything is fine ;-)

biologist79, 2020-11-14:
Hehe.
So finally, did this one run instantly or did you discover a problem with the wiring (or whatever)?

Regarding the "ugly" sound: decoding mp3 seems to be pretty time-critical. So that's finally why I ended up in running rfid, mp3 and neopixel within separated tasks. Because in case the task-scheduling is controlled by freertos which means: not my job! :-)

eazy, 2020-11-15:
it was running instantly. So no wireing problem.
So now I have to find out why the tonuino isn't running with rfid and SD-Card, I'll report if I find out.

biologist79, 2020-12-01:
Any news?

eazy, 2020-12-06:
Sorry, there was too much work the last days.

I've done a bit but not that much, mainpart was the resoldering to shorten the wires (just to go for sure).
deaktivated neopixel and all the stuff which I don't need for the moment bus can't get it work.

Your Isoatited snipped is working alle the time but the normal code has the problem with the sd card and the RFID Reader.

Maybe I'll switch to the Hardware setup of your mainproject, just to get anything working with my less time at the moment.

Zip-o-mat, 2020-12-10:
I dont know if we have the same problem here but it seems that the RFID reader only works if the CS pins are set before SPI_MFRC.begin(). The code now looks like this:
```c++
...
pinMode(SD_CS, OUTPUT);
digitalWrite(SD_CS, HIGH);
pinMode(MFRC522_CS_PIN, OUTPUT);
digitalWrite(MFRC522_CS_PIN, HIGH);

SPI_MFRC.begin(SPI_SCK, SPI_MISO, SPI_MOSI);
SPI_MFRC.setFrequency(1000000);
...
```
if @eazy can confirm this, I can create a pull request for this.

biologist79, 2020-12-10:
To be honest: I still need to put work on this audio-kit-stuff. It needs to be branched I guess in order to keep it in sync with master.

eazy, 2020-12-11:
@Zip-o-mat I'll try out this evening

eazy, 2020-12-11:
@Zip-o-mat with your changes SD Card is mounted and working but RFID is only initialized but not reading any rfid card.
Just no reaction if I put an rfid chip on the reader.

biologist79, 2020-12-11:
Have you been using the Lib provided? https://github.com/biologist79/Tonuino-ESP32-I2S/tree/master/Hardware-Plaforms/ESP32-A1S-Audiokit/lib/MFRC522
I know somehow this should work with the standard-lib but I didn't have time yet to investigate.

Zip-o-mat, 2020-12-11:
I just double checked:
This is the only thing I changed in the source code and I am using the modified MFRC522 Library (I commented out the original Library in my platformio.ini ( ; https://github.com/biologist79/rfid.git ))

eazy, 2020-12-11:
yes, I'm also using the modified one. I also commented the original one from platformio.ini and to go for sure I've done the include with the complete path
#include <..\lib\MFRC522\src\MFRC522.h>

and I tested also the "isolated sketch" to go for sure wiring is ok, this is working

eazy, 2020-12-11:
urgs ... I erased the esp and now it is working with the codechange of @Zip-o-mat

thanks

biologist79, 2020-12-11:
So please send me a pull-request.
However, still need to integrate that stuff into my main-development. The code in audiokit's folder is somewhat outdated.

Closed 2020-12-16.

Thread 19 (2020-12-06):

Wifi problem: Esp doesn't get proper IP assigned

jokober, 2020-12-06:
Hello,
first I want to thank you for your great work!

Unfortunately I am struggling to get everything to work. So far I only have the sd card module and the rfid reader connected. I had some issues to get the sd card reader to work with my Lolin32 Lite (no 5V pin) but managed to solve the issue by using a external 5V source to power the sd card module. This is not a nice solution but it works for the moment.

After connecting to the access point, changing the wifi settings and restarting the esp is not properly connected to the network. I can see the device in the fritz!box settings but it has no IP assigned. DHCP is aktivated.

The output also looks really weird:

```
[D][WiFiGeneric.cpp:374] _eventCallback(): Event: 0 - WIFI_READY
[D][WiFiGeneric.cpp:374] _eventCallback(): Event: 2 - STA_START
Hostname aus NVS geladen: jettebox
Firmware Version: 0xEF = (unknown)
RFID-Tags koennen jetzt gescannt werden...
[D][WiFiGeneric.cpp:374] _eventCallback(): Event: 7 - STA_GOT_IP
[D][WiFiGeneric.cpp:418] _eventCallback(): STA IP: 255.255.255.255, MASK: 255.255.255.255, GW: 255.255.255.255
[D][WiFiGeneric.cpp:374] _eventCallback(): Event: 7 - STA_GOT_IP
[D][WiFiGeneric.cpp:418] _eventCallback(): STA IP: 255.255.255.255, MASK: 255.255.255.255, GW: 255.255.255.255
.Aktuelle IP: 255.255.255.255
SD Card Type: SDHC
Free heap: 153464
Versuche Verbindung zu MQTT-Broker aufzubauen 192.168.2.43
Verbinde zu MQTT-Server mit User und Passwort
Neue Lautstärke empfangen via Queue: 3

```

Have you experienced similar problems or do you have any idea what might cause the problem?

biologist79, 2020-12-07:
Hi,

hmm, I've never been working with a Lolin32 lite. However, I've been told that this boards makes use of a weak voltage regulator. The user said he wasn't able to get the SD-card running until he used an external voltage-regulator. So (to be honest) just a rough guess: maybe a problem due to the regulator?

Have you already been using this board with a simple Wificlient-sketch or so? Just to make sure it's working in this case.

mariolukas, 2020-12-08:
I am not using a Lolin32 Board but sometimes i am running in a similar issue. I have the presumption that MQTT might bring some problems when no broker is configured in your network. Maybe you can try to deactivate MQTT for a first try. Just change your config file from:
`#define MQTT_ENABLE   `
to
`//#define MQTT_ENABLE      `

biologist79, 2020-12-09:
@jokober Have you been testing my latest software-revision? Just asking because I revised MQTT-handling recently. Maybe your problem is resolved now.

jokober, 2020-12-09:
Sounds promising. I will be able to test it tomorrow evening. Thanks for the help

jokober, 2020-12-11:
Disabling MQTT as well as the new software-revision did not fix the problem. Unfortunately I don't have any new information which might help to solve the issue. I will let you know if I sind out more

jokober, 2020-12-13:
I managed to solve the problem. It was kind of obvious but still took me some time. First I realised that I could connect to the network with a static IP.

Next I made sure to connect to the network by removing following line:

https://github.com/biologist79/Tonuino-ESP32-I2S/blob/38556b5d69a39d133b05e957f4475278b675e82d/src/main.cpp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

And voila it works!

biologist79, 2020-12-13:
Thanks you! Fixed it.

Closed 2020-12-13.

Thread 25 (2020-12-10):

Rotary Encoder - no INPUT_PULLDOWN possible

erniberni, 2020-12-10:
I am not sure if this really matters.
The GPIO34 and GPIO35 where the rotary encoder is connected has no sw enable pullup or pulldown.
The used library ESP32Encoder default enables a pulldown on these GPIOs but this is not working.

biologist79, 2020-12-11:
Didn't have any problems so far. Encoder's button is pulled internally (in the encoder) to high if not pressed.

tueddy, 2020-12-11:
I can confirm the encoder works without any problems.

tueddy, 2020-12-18:
This could be the reason why it works flawless:

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

If you put just the rotary encoder on a PCB you should use external pullups. For the breakout module it works because resistors are already on the module.

erniberni, 2020-12-20:
Yes, I am sure, this is the reason. I am using an encoder like this https://www.amazon.de/Rotary-Encoder-Schalter-Drehschalter-Keyswitch/dp/B0085I4D5C/
That type has no pullups. I used an external pulldown, because the library ESP32Encoder is expecting pulldowns as default. I think this doesn't really matter, if the sw is detecting signal edges.

Closed 2020-12-11.

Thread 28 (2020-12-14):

SPI configuration on ttgo t8 v1.7 (SD card reader onboard)

jokober, 2020-12-14:
I am trying to use the ttgo t8 v1.7 in my project. It has an onboard card reader. Unfortunately I can't get the RFID reader (RC522) to work. I saw that you @biologist79  have played around with different SPI configurations on different boards and was wondering if you have an idea what I do wrong or what I could try to get the RFID reader work. Previous to this project I had no experience with SPI.

Here is my configuration:

```
//#define SINGLE_SPI_ENABLE         // If only one SPI-instance should be used instead of two (not yet working!)
// uSD-card-reader (via SPI)
#define SPISD_CS                        13 // <- changed from 15          // GPIO for chip select (SD)
#ifndef SINGLE_SPI_ENABLE
    #define SPISD_MOSI                  15 // <- changed from 13            // GPIO for master out slave in (SD) => not necessary for single-SPI
    #define SPISD_MISO                 2 // <- changed from 16             // GPIO for master in slave ou (SD) => not necessary for single-SPI
    #define SPISD_SCK                   14          // GPIO for clock-signal (SD) => not necessary for single-SPI
#endif

// RFID (via SPI)
#define RST_PIN                         99          // Not necessary but has to be set anyway; so let's use a dummy-number
#define RFID_CS                         21          // GPIO for chip select (RFID)
#define RFID_MOSI                       23          // GPIO for master out slave in (RFID)
#define RFID_MISO                       19          // GPIO for master in slave out (RFID)
#define RFID_SCK                        18          // GPIO for clock-signal (RFID)
```
The ttgo t8 board:
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

tueddy, 2020-12-14:
Hi,

have you checked SD card reader can mount the card?
There might be a conflict with
`#define PREVIOUS_BUTTON                 2`
IO2 is used for MISO in your configuration.
So the software crashed before the RFID reader could be started.
What is the output in serial console?

jokober, 2020-12-14:
Good point. I have changed the PREVIOUS_BUTTON pin.

However it doesn't change anything. The SD card can be mounted. There is no output when scanning a RFID tag:
```
[D][WiFiGeneric.cpp:374] _eventCallback(): Event: 0 - WIFI_READY
[D][WiFiGeneric.cpp:374] _eventCallback(): Event: 2 - STA_START
Firmware Version: 0x92 = v2.0
RFID-Tags koennen jetzt gescannt werden...
[D][WiFiGeneric.cpp:374] _eventCallback(): Event: 4 - STA_CONNECTED
[D][WiFiGeneric.cpp:374] _eventCallback(): Event: 7 - STA_GOT_IP
[D][WiFiGeneric.cpp:418] _eventCallback(): STA IP: 192.168.178.68, MASK: 255.255.255.0, GW: 192.168.178.1
.Aktuelle IP: 192.168.178.68
Free heap: 163664
Neue Lautstärke empfangen via Queue: 3
Batteriespannung niedrig: (0.30 V)
Aktuelle Batteriespannung: 0.30 V
```
After some time following output appeared:
`31169 BAIL 12`

jokober, 2020-12-14:
At least I thought the SD card works. In the web-gui I get following notification:
"SD-Karten-Index muss erstellt werden"

biologist79, 2020-12-14:
Your SD-card needs to be indexed in order to provide the filebrowser. This is because reading from SD all the time is a bit slow. But means: every time you changed anything on the SD-card, the indexfile needs to be refreshed (only takes a few seconds).

Did you connect the RFID-reader to 3.3V?
Try to get RFID only running: https://github.com/miguelbalboa/rfid/blob/master/examples/DumpInfo/DumpInfo.ino
RST is not necessary. SS is CS. So should be necessary to change SS to 21

tueddy, 2020-12-14:
Strange, `Firmware Version: 0x92 = v2.0` means the MFRC522 is wired up fine and running.

biologist79, 2020-12-14:
Indeed I had such problems with RFID not complaining but anyhow not running. But only with single-SPI-mode. With two SPI-instances it is fine.

jokober, 2020-12-14:
I'm sorry the problem was caused by a faulty breadboard. I can confirm that the above configuration works on the ttgo t8. Now everything works well from RFID scan to the audio playing. Thank for your great work!

biologist79, 2020-12-15:
Sounds good :-) I often had problems because of that breadboard-stuff. That's why I started to create PCBs. But it totally makes sense to test this stuff first :-)

Closed 2020-12-15.

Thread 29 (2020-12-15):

Esp32 Reboots sometimes when NVS Data is written

grch87, 2020-12-15:
Hi,
first of all thank you for the great work you did!

I face a problem, that the Esp32 is rebooting from time to time. I narrowed it down, that it happens when NVS data is written.
The reason is that a core panic'ed:

`Titel wurde bei Position 483427 pausiert.
Schreibe '#/ManaMana#483427#3#0' in NVS für RFID-Card-ID 164177162177 mit playmode 3 und letzter Track 0
#/ManaMana#483427#3#0
Guru Meditation Error: Core  0 panic'ed (Cache disabled but cached memory region accessed)
Core 0 register dump:
PC      : 0x401826cc  PS      : 0x00060034  A0      : 0x800813dd  A1      : 0x3ffbe180
A2      : 0x00000000  A3      : 0x3ffc1530  A4      : 0xc86f19be  A5      : 0x00001004
A6      : 0x3ffc5ad0  A7      : 0xffffeffb  A8      : 0x80081332  A9      : 0x3ffbe160
A10     : 0x00000000  A11     : 0x00000000  A12     : 0x0ffd114c  A13     : 0x00000000
A14     : 0x000f8023  A15     : 0x00000002  SAR     : 0x00000014  EXCCAUSE: 0x00000007
EXCVADDR: 0x00000000  LBEG    : 0x00000000  LEND    : 0x00000000  LCOUNT  : 0x00000000
Core 0 was running in ISR context:
EPC1    : 0x4008ad89  EPC2    : 0x00000000  EPC3    : 0x40088e44  EPC4    : 0x401826cc`

To reproduce it I use the Audiobook mode and toggle Play/Pause Button as long as the problem occurs.

It seems that I found with the help of google the reason:
https://esp32.com/viewtopic.php?t=7684

However, I'm not able to solve it so far and created therefore this issue.
Is this a known issue?

biologist79, 2020-12-15:
Hi,

hmm, that's interesting. Indeed in project's description I stated recently "Currently, when re-learning a RFID-tag, Tonuino restarts. Almost certainly it's a memory-issue. Still have to point out.". I discovered this only happens when the music is already playing. So if the music is stopped when NVS-operation takes place, it's fine. Already decoded the stacktrace:

Decoding stack results
0x40170624: rmt_set_tx_intr_en at /home/runner/work/esp32-arduino-lib-builder/esp32-arduino-lib-builder/esp-idf/components/driver/rmt.c line 366
0x40081305: ESP32RMTController::interruptHandler(void*) at .pio/libdeps/lolin32/FastLED/src/platforms/esp/32/clockless_rmt_esp32.cpp line 323
0x40087a78: spi_flash_op_block_func at /home/runner/work/esp32-arduino-lib-builder/esp32-arduino-lib-builder/esp-idf/components/spi_flash/cache_utils.c line 82
0x40083a97: ipc_task at /home/runner/work/esp32-arduino-lib-builder/esp32-arduino-lib-builder/esp-idf/components/esp32/ipc.c line 62
0x40089c11: vPortTaskWrapper at /home/runner/work/esp32-arduino-lib-builder/esp32-arduino-lib-builder/esp-idf/components/freertos/port.c line 143

But didn't have a focus what's the reason so far. Maybe the problem is the same. I'll try to investigate. Try because the link provided is for IDF and not Arduino. We'll see...

Thanks for the hint.

biologist79, 2020-12-15:
Have one thing to add: the problem I described doesn't occur if Neopixel is not enabled.

grch87, 2020-12-15:
Hehe,
just wanted to add the same hint with Neopixel.
It seems, that I have as well a fix for it, but do not know yet exactly why it is working ^^
When pinning the showLed Task to Core1 instead of Core0 the problem is gone.

Maybe it helps to separate the RFID Task with SPI from the showLed Task?

biologist79, 2020-12-15:
Cool. Indeed switching to core 0 seems to solve the problem 👍
Regarding the flickering: for me it massively improved by using a JST-PH 2.0-connector instead of jumperwires. But timing is indeed an issue as via serial this is indicated via "BAIL"-stuff. Don't know if that's because it's running as a task.

biologist79, 2020-12-15:
With your fix provided: are you still able to reproduce the audiobook-book-problem when toggling play/pause? I'm not :-)

grch87, 2020-12-16:
With the core change I'm not able to reproduce the problem, so the issue can be closed.
Nevertheless I want to understand the problem and I will invest some time on it. If I have some news I let you know!
Thank you for the hint with the JST-PH connector. I will consider that in a next board revision. Currently the Neopixel cables are soldered onto the board.

biologist79, 2020-12-16:
I guess it's something with interrupts as Neopixel is interrupt-driven. Disabling Neopixel "fixes" the problem as well.
However, big thanks for your input!

biologist79, 2020-12-16:
As it turns out, moving Neopixel-task to the second cpu-core has negative impact to the FTP-transfer-rate (from 185 kB/s down to 165 kB/s). However, it can be rescued a bit if Neopixel-animation is disabled while FTP-transfer is active (176 kB/s). Will have to test a bit...

biologist79, 2020-12-18:
Hi @grch87,
as FTP-performance is highly affected when moving Neopixel to 2nd core, I'm trying something else: if NVS-write is in progress, Neopixel-signalisation is disabled.
Committed it recently and tested it as well for pressing pause/play multiple times in audiobook-mode. Worked for me. Please test if it also works for you.

grch87, 2020-12-19:
Hi @biologist79,
yes your fix is working :)
However, it seems that my LED Task freezes short time after start playing audio.

What I know so far: the new pauseNeopixel flag is not the reason. Either the LED task stucks somewhere in the loop (but then the watchdog should be triggered?), the task is killed (but I have no indication via the serial monitor) or the task is no longer getting computation time?

I guess you don't see that issue?

grch87, 2020-12-19:
ok found the issue: There is something wrong in the FastLED library. It seems to crash silently.
Tried then older FastLED versions. 3.3.3 crashed. The 3.2.10 seems to work.
A lessons learnt would be to use tagged versions for the libraries this project is using.

In the platformio.ini the reference would look like that:
https://github.com/FastLED/FastLED.git#3.2.10

What do you think?

biologist79, 2020-12-19:
Hm ok, gonna add this version to plastformio.ini.
Thanks for your contribution for MMC. Will revise this tomorrow I guess.

biologist79, 2020-12-20:
Seems as there's been a fix 2 hours ago. Discovered that when music's playing and I tried to access the webgui, Tonuino restarted. Not every time but very often. However, this seems to fix that problem: https://github.com/FastLED/FastLED/pull/1144
BAIL-stuff is also gone now (from the logs).

Closed 2020-12-16.

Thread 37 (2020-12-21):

LED Rainbow hue does not seem to work?

weitzj, 2020-12-21:
Edit:

I think I need to understand: `lockControls` better.

I have hooked up an LED ring and it mostly works, i.e.

- white if bootd with wifi (animated)
- blue if started without wifi (animated)
- orange during boot (animated()

But I can't get the rainbow hue working whilst playing a single MP3 file.
When playing a single file the LEDs turn off.

When playing a webstream I get 2 opposite red LEDs (not animated)

My question is:

Is this intended behaviour? (to safe battery)

If I were to implement it, do I need to create another LED state like `ledStatusOk`, `ledStatusError`?

weitzj, 2020-12-21:
I see you have upgraded the master. I will try before openning this issue

biologist79, 2020-12-21:
Currently, as it seems, there are some problems ongoing with the lib I used (Fastled). Recently had serveral restart-issues which is the reason I'm now back at version 3.3.3 for Fastled (see platformio.ini) as reference. So I don't know if that might be reason (but probably not).

However, when it comes to Neopixel, I didn't implement anything different for saving energy. In fact ESP32 doesn't know (and so me) if battery currently is the only source. Well, I could if I'd do an analogRead() via voltage divider of a 5V-pin, but as it's never been my intention.

I never had reports so far, that rainbow-color doesn't work for track-progress. The only thing I noticed is: if brightness is down to 2 or so, colouring changes a bit. Does the rainbow appear/disappear when changing the volume via rotary encoder?

biologist79, 2020-12-21:
Today I only updated README-description.

weitzj, 2020-12-21:
Thank you.

The expected behaviour for webradio is:

2 red leds opposite of each other rotating counterclockwise? And once in a while a green blink?

biologist79, 2020-12-21:
2 leds: yes. But when I remember right, rotation is clockwise (not 100% sure).
However, in settings.h there's a switch available to invert LED-addressing as there are Neopixel around soldered clockwise wheras others are counter-clockwise.

biologist79, 2020-12-21:
Green blink: No. This is a problem with version 3.3.3. Don't have these green blinks with the master-version of Fastled. But this version led to restart-issues. So green blinks is "das kleinere Übel" :-)

weitzj, 2020-12-21:
Sorry for my dumb questions. RTFM

The LED Ring does a progressbar (with green blink once in a while). Now everything works!

Fantastic project

Closed 2020-12-21.

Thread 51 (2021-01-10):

SD could not be mounted

thebino, 2021-01-10:
I'm trying to use [this SD-Modul](https://de.aliexpress.com/item/32523546123.html) but the SD-Card could not be mounted.
> [E][sd_diskio.cpp:739] sdcard_mount(): f_mount failed 0x(3)

Do I need to use the **SD-MMC Mode**?

As ESP I use the [ESP32-WROOM-32 from AZ-Delivery](https://www.amazon.de/gp/product/B074RGW2VQ/)

tueddy, 2021-01-10:
I think this module is for 5V boards. There is a power regulatur, so Vcc must be 5V.
I've tested this board before, works fine with SPI mode. You have to power with 5V or better remove the power regulator abd bridge them. Then you can use the ESP-32 3.3V for Vcc:

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

I don't remember if this board works in SD-MMC mode (I don't think so).

thebino, 2021-01-10:
Ah, I've read something about this power regulation change but didn't check the spec for this module which resistor I have to remote.

tueddy, 2021-01-10:
If you want to test SD-MMC mode on a breadboard, you can solder this simple and cheap Adapter:

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

I can recommend this [article ](https://www.instructables.com/Select-SD-Interface-for-ESP32/)comparing SPI and SD-MMC modes.

thebino, 2021-01-10:
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

Nothing changed, can I measure anything to check the voltage?

biologist79, 2021-01-10:
Moin,

ich wechsele mal kurz auf Deutsch. Wir müssen uns als drei Deutsche hier auch nicht auf Englisch unterhalten :-)
Habe mir die Platine von Mario eben mal in KiCad angeschaut. Denke hier muss ich die Doku noch etwas erweitern. Hier ist ja ein Mosfet und ein NPN-Transistor eingebaut, der die Peripherie abschaltet, wenn der ESP im Deepsleep ist. Allerdings ist es so, dass beim Board von Mario 5V geschaltet werden und nicht 3.3V, wie ich das inzwischen (aus Akku-technischen Gründen) verstärkt propagiere. Ausnahme ist der RFID-Reader, der hängt direkt am GPIO17, der sonst die Transistorstufe ansteuert. Das bedeutet, dass der SD-Reader mit 5V versorgt wird. Da SD nur mit 3.3V arbeitet, braucht es hier einen Festspannungsregler. Den hat das von dir verwendete Board eigentlich auch (habe es selbst hier auch liegen), aber er ist ausgelötet. Warum?
Teste am besten mal im Rechner, ob deine SD-Karte überhaupt noch funktioniert.

tueddy, 2021-01-10:
Kenne jetzt diese Platine/Layout von Mario nicht, was hier wie wo beschaltet wird. Der Vorschlag den Spannungsregler auszulöten bezog sich auf die direkte Ansteuerung mit ESP-32 über 3.3V. Das Breakout Board ist für 5V ausgelegt. Wenn das mit 5V belegt wird bleibt der Spannungsregler natürlich drin..

biologist79, 2021-01-10:
Ach das habe ich übersehen
@thebino Also der Festspannungsregler muss auf jeden Fall rein. Wo du aber auf jeden Fall ansetzen kannst, das sind die Lötpunkte. Achte drauf den Pin, den du festlöten willst, vielleicht erst so 3s mit einem Lötkolben zu erhitzen. Dann gibst du *etwas* Lötzinn dazu und nimmst das Lötzinn wieder weg. Dann wartest du noch kurz und wirst sehen, dass das Lötzinn anfängt zu fließen. Dann nimmst du den Lötkolben erst weg und lässt es abkühlen.

Schau mal hier so bei 6min, da kannst du das gut sehen: https://www.youtube.com/watch?v=Cww1ZGKClXw

biologist79, 2021-01-10:
So, ich habe die Doku mal erweitert/verbessert: https://github.com/biologist79/Tonuino-ESP32-I2S/tree/master/PCBs/ESP32_Breakout_Carrier

thebino, 2021-01-11:
Danke ich hätte vielleicht dazu schreiben sollen, dass ich hier ein Custom PCB verwende. Mit ist später noch aufgefallen, dass die Platine überall auf 5V ausgelegt ist.
Die Lötpunkt sehen deshalb so scheiße aus, weil meine Lötsptitze nach ca. 20 Jahren eindeutig hinüber ist, die neue kommt allerdings erst diese Woche. Dann wird nochmal alles ordentlich gemacht.
Die fehlenden Komponenten folgen dann ebenfalls, die kommen nur nicht direkt auf das Board sondern irgendwo in das Gehäuse wo sie Sinn machen.
Ich wollte nur erstmal den SD-Reader testen und dachte das sollte auch ohne RFID gehen bevor ich noch mehr verbaue.

biologist79, 2021-01-11:
Das ist auch tatsächlich der Fall: SD ohne RFID geht. Nur andersrum nicht :-) Weil es hängt inzwischen so viel von SD ab, dass es ohne nicht mehr geht. Es wird demnächst vermutlich demnächst noch eine Anpassung geben, dass man html-Files vor der Einrichtung auf die SD-Karte kopieren muss.

erniberni, 2021-01-13:
Wenn du die SD Karte zunächst alleine testen willst (ich habe das gemacht, um andere Fehler auszuschliessen), dann empfehle ich dieses Testprogramm, das auf die Verdrahtung im Projekt abgestimmt ist.

[SD_Test.zip](https://github.com/biologist79/Tonuino-ESP32-I2S/files/5808717/SD_Test.zip)

thebino, 2021-01-13:
Habe den Fehler gefunden, hatte falsche Widerstände verbaut wodurch die Spannungsversorgung nicht gepasst hat.

Closed 2021-01-13.

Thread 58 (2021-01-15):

SD Karte wird nicht erkannt

epictechlab, 2021-01-15:
Hallo,

Danke erstmal für das tolle Projekt.
Ich habe bereits die vorherige Version mit einer nodemcu am laufen gehabt, und will mir jetzt die neue Version auf Basis des Lolin32 aufbauen. Habe mir hierzu deine PCBs und die anderen Komponenten bestellt. Das einzige das ich nicht habe ist die Batterie, da ich den Tonuino nicht portable benötige.
Allerdings wird hier die SD Karte nicht erkannt und somit startet der Tonuino nicht in den AP mode.
Kann es sein das ich die Batterie benötige auch wenn ich sie nicht brauche?
Die CHG LED des Lolin32 flackert auch immer wie wild.
Und mein neopixel blinkt rot. Was darauf schließt das die SD Karte nicht erkannt wird.

Woran könnte es denn noch liegen?

biologist79, 2021-01-15:
Moin,

steht auf deinem Lolin32 v1.0.0 drauf? Wenn ja: Dann ist das mit dem ständigen Blinken normal. Mir ist auch unklar, was das soll, aber es geht auf jeden Fall weg, wenn man das Board im Batteriebetrieb hat. Einen Akku brauchst du nicht. Schau dann halt, dass du die Spannungsüberwachung nicht mit einkompilierst.

Mit SD ist das so eine Sache. Üblicherweise liegt das an schlechten Verbindungen auf dem Breadboard (welches man ja üblicherweise nutzt, wenn man das alles mal testen will). Hatten schon einige User Probleme mit; zuletzt zB hier: https://github.com/biologist79/Tonuino-ESP32-I2S/issues/51
Verifiziere nochmal, dass die richtigen GPIOs angeschlossen sind und versuche es vielleicht nochmal mit anderen Jumperwires.
Der Neopixel blinkt rot, weil der Bootvorgang nicht komplettiert wird. Ich hatte mal eine Weile einen Modus, dass man auch ohne SD booten konnte, aber es macht dauerhaft einfach keinen Sinn.

VG.

biologist79, 2021-01-20:
Neuigkeiten?

epictechlab, 2021-01-20:
Ja und nein, das erste Problem war ein GND Problem am neopixel Ring. Dadurch wurde nicht weiß sondern rot als Farbe dargestellt. Heißt der Lolin32 ist normal gebootet und eigentlich würde du SD auch erkannt.

Das eigentliche Problem ist aber das die deepsleep Schaltung mit den 2 MOSFETs nicht richtig funktioniert. Wenn ich diese umgehe und direkt 3,3v auf die source vom P-kanal MOSFET lege, dann läuft alles.

Pin 17 schaltet nach einer gewissen Zeit die Spannung weg. Womit der N-kanal MOSFET nicht mehr durchschaltet und damit den P-kanal MOSFET lahmlegt.

Warum? Keine Ahnung.

Was mir noch aufgefallen ist, kann es sein das die maximal Lautstärke sehr gering ist. Mir kommt es sehr leise vor. Ich werde aber heute Abend Mal einen anderen Lautsprecher dran hängen und nochmal testen.

biologist79, 2021-01-20:
Wie groß ist denn dein Vorwiderstand am Gate des IRF530N? Ich hatte da auch mal 4.7k, aber es hat nicht funktioniert. Wenn ich damit auf 1k runtergegangen bin, hat es geklappt.

biologist79, 2021-01-20:
Achso, dass der Tonuino startet sich nach ein paar Sekunden automatisch neu, wenn das Flag `SHUTDOWN_IF_SD_BOOT_FAILS` gesetzt ist. Grund dafür ist, dass man im Batteriebetrieb, wenn was mit SD schiefläuft, sonst keine Möglichkeit mehr hat, den Tonuino neu zu starten (wenn alles eingebaut ist).

epictechlab, 2021-01-20:
> Wie groß ist denn dein Vorwiderstand am Gate des IRF530N? Ich hatte da auch mal 4.7k, aber es hat nicht funktioniert. Wenn ich damit auf 1k runtergegangen bin, hat es geklappt.

1k so wie es in deiner Anleitung angegeben ist.

epictechlab, 2021-01-20:
> Achso, dass der Tonuino startet sich nach ein paar Sekunden automatisch neu, wenn das Flag `SHUTDOWN_IF_SD_BOOT_FAILS` gesetzt ist. Grund dafür ist, dass man im Batteriebetrieb, wenn was mit SD schiefläuft, sonst keine Möglichkeit mehr hat, den Tonuino neu zu starten (wenn alles eingebaut ist).

Gut zu wissen, die kann ich auskommentieren da ich keine Batterie nutze.

biologist79, 2021-02-01:
Hast du das gelöst bekommen?
Hinweis an dieser Stelle: der IRF530N besitzt eine Vgs von 2 bis 4 V. Ich denke wenn man da ein Modell erwischt, das eher nach oben streut, dann schaltet der nicht durch. Man kann es einfach testen, indem man an das Gate des NDP6020p GND legt (Achtung: Gate ist NICHT der Anschluss in der Mitte!). Inzwischen verwende ich IRL3103, da dieser eine erheblich niedrigere Vgs besitzt.

epictechlab, 2023-08-13:
Hallo,
ist zwar nicht ganz sauber hier rein zuschreiben da das Thema "closed" ist, aber ichg mache es jetzt einfach trotzdem. ich konnte mich jetzt wirklich lange nicht mehr mit dem Projekt auseinander setzten und habe mittlerweile gesehen das sich hier einiges getan hat. ich würde meinen Kindern zu liebe das ganze nochmal neu aufrollen, oder besser gesagt optimieren.
Weil wie damals beschreiben gab es immer weider mal Probleme...

Ich habe damals diese PCB von dir verwendet? **TONUINO LOLIN32 3.3V rev2** sind die noch brauchbar oder ist das inzwischen alles überholt?
Welcher ESP wird denn aktuell verwendet?

Evtl. findest ja mal kurz zeit mir hier zu antworten, Danke dir schonmal.

beste Grüße

tueddy, 2023-08-13:
Kenne jetzt Dein Board nicht aber grundsätzlich wird der Lolin-32 unterstützt, egal ob Softwareversion "master" oder "DEV".
Falls Probleme erstelleeinen Eintrag im ESPuino-Forum: https://forum.espuino.de

Closed 2021-02-08.

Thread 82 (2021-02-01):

Problems with old MP3 Tags (ID3v2.2)

vrjpellenz, 2021-02-01:
With the newest version I experienced problems with MP3 files with older MP3 Tags (ID3v2.2). All the songs with old tags did not play, and on the console the following messages appeared multiple times:
```
...
info        : ID3 framesSize=2337
info        : ID3 version=2
info        : ID3 version must be 3, skip all metadata
info        : ID3 framesSize=2337
info        : ID3 version=2
info        : ID3 version must be 3, skip all metadata
...
```
After writing the tag info with some MP3 Tag software, it was updated (as a side effect) to version ID3v2.3 and the files played again. Maybe a change in the underlying MP3 lib caused this new behavior. (It was working before with the older version of ESPuino / ESP TonUINO from December 2020.)

biologist79, 2021-02-01:
What's the version of the mp3-lib you're using? Just asking as a few weeks ago a method was introduced that's not yet supported by the last esp32-Arduino-Framework. That's why in platformio.ini I stepped away from the newest version (in order to avoid compiling-problems) and added "https://github.com/schreibfaul1/ESP32-audioI2S.git#a816a19".

vrjpellenz, 2021-02-01:
I am using the current platformio.ini:

```
[common]
lib_deps_builtin =
        SPI
        Wire
lib_deps_external =
        https://github.com/schreibfaul1/ESP32-audioI2S.git#a816a19                      ; currently not master-version as commit a816a19 not compatible with latest stable ESP32-Arduino
        https://github.com/madhephaestus/ESP32Encoder.git
        https://github.com/knolleary/pubsubclient.git
        https://github.com/biologist79/ESP32FTPServer
        https://github.com/FastLED/FastLED.git#3.4.0
        ESP Async WebServer
        https://github.com/me-no-dev/AsyncTCP
        https://github.com/bblanchon/ArduinoJson.git
; https://github.com/pschatzmann/ESP32-A2DP.git
```

which results in the following dependency tree:

```
|-- <SPI> 1.0
|-- <Wire> 1.0.1
|-- <ESP32-audioI2S-master> 2.0.0+sha.a816a19
|   |-- <FS> 1.0
|   |-- <SD(esp32)> 1.0.5
|   |   |-- <FS> 1.0
|   |   |-- <SPI> 1.0
|   |-- <SPI> 1.0
|   |-- <WiFiClientSecure> 1.0
|   |   |-- <WiFi> 1.0
|-- <ESP32Encoder> 0.3.8+sha.db7bbf2
|-- <PubSubClient> 2.8.0+sha.2d228f2
|-- <ESP32FTPServer> 0.0.1+sha.f71e97d
|   |-- <SD(esp32)> 1.0.5
|   |   |-- <FS> 1.0
|   |   |-- <SPI> 1.0
|   |-- <FS> 1.0
|   |-- <WiFi> 1.0
|   |-- <SPI> 1.0
|-- <FastLED> 3.4.0+sha.2fe6aeb
|   |-- <SPI> 1.0
|-- <ESP Async WebServer> 1.2.3
|   |-- <AsyncTCP> 1.1.1
|   |-- <FS> 1.0
|   |-- <WiFi> 1.0
|   |-- <ArduinoJson> 6.17.2+sha.1360b6a
|-- <AsyncTCP> 1.1.1+sha.ca8ac5f
|-- <ArduinoJson> 6.17.2+sha.1360b6a
|-- <MFRC522> 1.4.6+sha.cd626f4
|   |-- <SPI> 1.0
|-- <PN5180 Library> 1.1.0+sha.2e3289f
|   |-- <SPI> 1.0
|-- <FS> 1.0
|-- <SD(esp32)> 1.0.5
|   |-- <FS> 1.0
|   |-- <SPI> 1.0
|-- <SD_MMC> 1.0
|   |-- <FS> 1.0
|-- <AsyncTCP> 1.1.1
|-- <ESPmDNS> 1.0
|   |-- <WiFi> 1.0
|-- <Preferences> 1.0
|-- <WebServer> 1.0
|   |-- <WiFi> 1.0
|   |-- <FS> 1.0
|-- <WiFi> 1.0
|-- <nvsdump>
```

biologist79, 2021-02-08:
Have you been trying to use the recent version of the audio-lib (https://github.com/schreibfaul1/ESP32-audioI2S) that is used by ESPuino? A few days a ago there was a commit regarding ID3-stuff: https://github.com/schreibfaul1/ESP32-audioI2S/commit/29806a189cc0ecbfddcd61681b4a793d40e4c82b

tueddy, 2021-02-13:
Some MP3 played fine before but now i get the same error messages.
I have created an issue in the used audio lib:
https://github.com/schreibfaul1/ESP32-audioI2S/issues/113

tueddy, 2021-02-13:
The author of the library has fixed the issue in lightspeed.
Problem was reading ID3 tags in version 2.2

I think this issue can be closed..

Closed 2021-02-17.

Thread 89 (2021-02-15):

Build errors

haukino, 2021-02-15:
Hi, I am getting these errors while compiling the code for the AZ Dev Kit v4: It used to work flawlessly before the integration of different boards :/

EDIT: After fiddling around a bit it changed to these error messages:

```
Processing az-delivery-devkit-v4 (platform: espressif32; board: az-delivery-devkit-v4; framework: arduino)
----------------------------------------------------------------------------------------------------------------------------------------------------------------------------------------------------Verbose mode can be enabled via -v, --verbose option
CONFIGURATION: https://docs.platformio.org/page/boards/espressif32/az-delivery-devkit-v4.html
PLATFORM: Espressif 32 (3.0.0) > AZ-Delivery ESP-32 Dev Kit C V4
HARDWARE: ESP32 240MHz, 520KB RAM, 16MB Flash
DEBUG: Current (esp-prog) External (esp-prog, iot-bus-jtag, jlink, minimodule, olimex-arm-usb-ocd, olimex-arm-usb-ocd-h, olimex-arm-usb-tiny-h, olimex-jtag-tiny, tumpa)
PACKAGES:
 - framework-arduinoespressif32 0.0.0+sha.7ecbb48
 - tool-esptoolpy 1.30000.201119 (3.0.0)
 - toolchain-xtensa32 2.50200.80 (5.2.0)
KeyError: 'PIOBUILDFILES':
  File "C:\Users\hauki\.platformio\penv\lib\site-packages\platformio\builder\main.py", line 177:
    env.SConscript("$BUILD_SCRIPT")
  File "C:\Users\hauki\.platformio\packages\tool-scons\scons-local-4.1.0\SCons\Script\SConscript.py", line 591:
    return _SConscript(self.fs, *files, **subst_kw)
  File "C:\Users\hauki\.platformio\packages\tool-scons\scons-local-4.1.0\SCons\Script\SConscript.py", line 280:
    exec(compile(scriptdata, scriptname, 'exec'), call_stack[-1].globals)
  File "C:\Users\hauki\.platformio\platforms\espressif32\builder\main.py", line 225:
    target_elf = env.BuildProgram()
  File "C:\Users\hauki\.platformio\packages\tool-scons\scons-local-4.1.0\SCons\Util.py", line 658:
    return self.method(*nargs, **kwargs)
  File "C:\Users\hauki\.platformio\penv\lib\site-packages\platformio\builder\tools\platformio.py", line 77:
    os.path.join("$BUILD_DIR", env.subst("$PROGNAME")), env["PIOBUILDFILES"]
  File "C:\Users\hauki\.platformio\packages\tool-scons\scons-local-4.1.0\SCons\Environment.py", line 388:
    return self._dict[key]
==================================================================================== [FAILED] Took 0.90 seconds ====================================================================================
Environment            Status    Duration
---------------------  --------  ------------
az-delivery-devkit-v4  FAILED    00:00:00.904
============================================================================== 1 failed, 0 succeeded in 00:00:00.904 ==============================================================================
The terminal process "C:\Users\hauki\.platformio\penv\Scripts\pio.exe 'run', '--environment', 'az-delivery-devkit-v4'" terminated with exit code: 1.

Terminal will be reused by tasks, press any key to close it.

```
I already reinstalled everything and downloaded the project again but still the same errors

regards

haukino, 2021-02-15:
Reinstalled everything and it works now

Closed 2021-02-15.

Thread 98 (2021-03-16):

kicad project files are now missing in ESP32_Breakout_Carrier

phschoen, 2021-03-16:
hi,
with the Commit cc6df6d032251d630405e257fc5d93730c21d179
you deleted way to much. Now the gerber zip and **kicad project** files are not available any more. Please revert this change of at least the kicad files.
WBR Philipp

biologist79, 2021-03-16:
Hi,

I deleted those as Tonuino is stated everywhere.
If you need it anyway maybe have a look at the fork by mariolokas. He's the one that provided it.

biologist79, 2021-03-16:
But anyway: I agree it'd totally make sense to move all these single gerber-files into a single zip-file

Closed 2021-03-16.

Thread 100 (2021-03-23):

Headphone PCB BOM Issue

dmlr1996, 2021-03-23:
Hello there,

some weeks ago, you have provided the new and detailed BOM for the PCB's. Now we have the problem, that in the BOM for the Headphone PCB is a IC1 (ME6211C33m5g) written but we cant find the IC1 in the Schematic / on the ordered PCB. Do you have a solution fot that?

biologist79, 2021-03-23:
Hi,

I forwarded this question to the guy that has been designing this PCB. He knows best, hehe.

compactflash, 2021-03-23:
Hi @dmlr1996
Maybe you have an old version of the BOM , the current ist [here](https://u.pcloud.link/publink/show?code=kZjJVKkZOYso9U99qILNOMm5ehliaFtxldWX) . I have made a 5V-version too , but the released one is for 3.3V . The ME6211 is not required .

dmlr1996, 2021-03-23:
Hi @compactflash
thanks for your message. I have the BOM you provided to me in #93. I will check it again. Thanks.

dmlr1996, 2021-03-23:
I have checked the BOM in the link you provided. There is a IC1 written for the headphone PCB. It's the same version like I have already.
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

dmlr1996, 2021-03-23:
Another thing we discovered today, neither the TDA1308 not the PT2308 are available at any of the nameable electronics distributors. Do you have any idea, how we can handle this?

biologist79, 2021-03-23:
At least something I can answer :-)
https://de.aliexpress.com/item/33020207730.html

dmlr1996, 2021-03-23:
Thanks @biologist79 the problem about it is the delivery time of 30-60 days .. xD

biologist79, 2021-03-23:
In case you need some and you're from Germany: 20 of those are sitting next to me :-)

dmlr1996, 2021-03-23:
Ja wenn das so ist, können wir auch deutsch schreiben :P
Das klingt gut. Mein kollege und ich bereiten gerade 5 Platinen vor, würdest du uns 5 Stück abgeben? Wenn ja, was sind wir dir schuldig?

biologist79, 2021-03-23:
Mach's so: Melde mich in meinem ESPuino-Forum (https://forum.espuino.de/) am besten mal an - das geht auch mit den Github-Zugangsdaten. Und schreibe mir dort ne PM. Dann machen wir das dort :-)

Closed 2021-04-18.

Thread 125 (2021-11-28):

D32 pro: build in sd card reader in coflict with PN5180

GeneralLuzi, 2021-11-28:
Hi,

it seems, that the build in sd card reader of the D32 pro is not compatible with PN5180-NFC. Let us see if it is a layer 8 issue... ;)

Unneeded pins are set to 99.

The following scenarios are tested:
1. MFRC522_SPI activted, PN5180 deactivated, RFID PINS to 99 --> OK
2. MFRC522_SPI deactivted, PN5180 activated, RFID PINS to 99 --> NOK
3. MFRC522_SPI deactivted, PN5180 activated + PINs set to default, but PN5180 not connected --> NOK
4. MFRC522_SPI deactivted, PN5180 activated + PINs set to default, PN5180  connected --> NOK

(Not tested:  MFRC522_SPI activted, PN5180 deactivated, RFID PINS to default --> I do not have a MFRC522)

Definition of OK: web server is accessible and music can be played.

Why NOK: Output is constant:

```
Maximale Inaktivitätszeit wurde aus NVS geladen: 10
Firmware version=0.0
RFID-Tags koennen jetzt gescannt werden...
[E][sd_diskio.cpp:194] sdCommand(): Card Failed! cmd: 0x37
[E][sd_diskio.cpp:194] sdCommand(): Card Failed! cmd: 0x29
[E][sd_diskio.cpp:775] sdcard_mount(): f_mount failed: (3) The physical drive cannot work
[E][sd_diskio.cpp:194] sdCommand(): Card Failed! cmd: 0x00
SD-Karte konnte nicht gemountet werden.
[E][sd_diskio.cpp:194] sdCommand(): Card Failed! cmd: 0x00
[E][sd_diskio.cpp:775] sdcard_mount(): f_mount failed: (3) The physical drive cannot work
[E][sd_diskio.cpp:194] sdCommand(): Card Failed! cmd: 0x00
SD-Karte konnte nicht gemountet werden.
```

SW-Version:
```
ESP-IDF-version (major): 3
ESP-IDF-version (minor): 3
Software-revision: 20211123-1
```

settings.h:

```

    //########################## MODULES #################################
    //#define PORT_EXPANDER_ENABLE          // When enabled, buttons can be connected via port-expander PCA9555 (https://forum.espuino.de/t/einsatz-des-port-expanders-pca9555/306)
    //#define I2S_COMM_FMT_LSB_ENABLE       // Enables FMT instead of MSB for I2S-communication-format. Used e.g. by PT2811. Don't enable for MAX98357a, AC101 or PCM5102A)
    #define MDNS_ENABLE                     // When enabled, you don't have to handle with ESPuino's IP-address. If hostname is set to "ESPuino", you can reach it via ESPuino.local
    //#define MQTT_ENABLE                     // Make sure to configure mqtt-server and (optionally) username+pwd
    //#define FTP_ENABLE                      // Enables FTP-server; DON'T FORGET TO ACTIVATE AFTER BOOT BY PRESSING PAUSE + NEXT-BUTTONS (IN PARALLEL)!
    //#define NEOPIXEL_ENABLE                 // Don't forget configuration of NUM_LEDS if enabled
    //#define NEOPIXEL_REVERSE_ROTATION     // Some Neopixels are adressed/soldered counter-clockwise. This can be configured here.
    #define LANGUAGE DE                     // DE = deutsch; EN = english
    //#define STATIC_IP_ENABLE              // Enables static IP-configuration (change static ip-section accordingly)
    //#define HEADPHONE_ADJUST_ENABLE       // Used to adjust (lower) volume for optional headphone-pcb (refer maxVolumeSpeaker / maxVolumeHeadphone) and to enable stereo (if PLAY_MONO_SPEAKER is set)
    //#define PLAY_MONO_SPEAKER               // If only one speaker is used enabling mono should make sense. Please note: headphones is always stereo (if HEADPHONE_ADJUST_ENABLE is active)
    #define SHUTDOWN_IF_SD_BOOT_FAILS       // Will put ESP to deepsleep if boot fails due to SD. Really recommend this if there's in battery-mode no other way to restart ESP! Interval adjustable via deepsleepTimeAfterBootFails.
    //#define MEASURE_BATTERY_VOLTAGE         // Enables battery-measurement via GPIO (ADC) and voltage-divider
    //#define PLAY_LAST_RFID_AFTER_REBOOT   // When restarting ESPuino, the last RFID that was active before, is recalled and played
    //#define USE_LAST_VOLUME_AFTER_REBOOT  // Remembers the volume used at last shutdown after reboot
    //#define USEROTARY_ENABLE                // If rotary-encoder is used (don't forget to review WAKEUP_BUTTON if you disable this feature!)
    //#define BLUETOOTH_ENABLE                // If enabled and bluetooth-mode is active, you can stream to your ESPuino via bluetooth (a2dp-sink).
    //#define IR_CONTROL_ENABLE             // Enables remote control (https://forum.espuino.de/t/neues-feature-fernsteuerung-per-infrarot-fernbedienung/265)
    //#define CACHED_PLAYLIST_ENABLE          // Enables playlist-caching (infos: https://forum.espuino.de/t/neues-feature-cached-playlist/515)
    //#define PAUSE_WHEN_RFID_REMOVED       // Playback starts when card is applied and pauses automatically, when card is removed (https://forum.espuino.de/t/neues-feature-pausieren-wenn-rfid-karte-entfernt-wurde/541)
    //#define SAVE_PLAYPOS_BEFORE_SHUTDOWN  // When playback is active and mode audiobook was selected, last play-position is saved automatically when shutdown is initiated
    //#define SAVE_PLAYPOS_WHEN_RFID_CHANGE // When playback is active and mode audiobook was selected, last play-position is saved automatically for old playlist when new RFID-tag is applied

    //################## select SD card mode #############################
    //#define SD_MMC_1BIT_MODE              // run SD card in SD-MMC 1Bit mode (using GPIOs 15 + 14 + 2 is mandatory!)
    //#define SINGLE_SPI_ENABLE             // If only one SPI-instance should be used instead of two (not yet working!)

    //################## select RFID reader ##############################
    //#define RFID_READER_TYPE_MFRC522_SPI    // use MFRC522 via SPI
    //#define RFID_READER_TYPE_MFRC522_I2C  // use MFRC522 via I2C
    #define RFID_READER_TYPE_PN5180       // use PN5180 via SPI

    #ifdef RFID_READER_TYPE_MFRC522_I2C
        #define MFRC522_ADDR 0x28           // default I2C-address of MFRC522
    #endif

    #ifdef RFID_READER_TYPE_PN5180
        //#define PN5180_ENABLE_LPCD        // Wakes up ESPuino if RFID-tag was applied while deepsleep is active. Only ISO-14443-tags are supported for wakeup!
    #endif
```

settings-lolin_d32_pro.h:
```
#ifndef __ESPUINO_SETTINGS_LOLIN_D32_PRO_H__
#define __ESPUINO_SETTINGS_LOLIN_D32_PRO_H__
    #include "Arduino.h"

    //######################### INFOS ####################################
    /* This is a develboard-specific config-file for *Wemos Lolin32*. Specific doesn't mean it's only working with this board.
    Lolin32 is the predecessor of Lolin D32.
    PCB: None so far
    Infos: https://www.wemos.cc/en/latest/d32/d32_pro.html
    Schematics: https://www.wemos.cc/en/latest/_static/files/sch_d32_pro_v2.0.0.pdf
    Caveats: GPIO35 (battery monitoring) + SD can't be changed, it's built in (and because of the SD-pinout used, it is not compatible with MMC-mode)
    Status:
        tested with 2xSPI: RC522 & SD (by biologist79)
    */

    //################## GPIO-configuration ##############################
    // Please note: GPIOs 34, 35, 36, 39 are input-only and don't have pullup-resistors.
    // So if connecting a button to these, make sure to add a 10k-pullup-resistor for each button.
    // Further infos: https://randomnerdtutorials.com/esp32-pinout-reference-gpios/
    // GPIOs 16+17 are not available for D32 pro as they're used to internal purposes (PSRAM).
    #ifdef SD_MMC_1BIT_MODE
        // NOT SUPPORTED BY D32 pro as 15 / 14 / 2 doesn't match D32 pro's SD-pinout
    #else
        // uSD-card-reader (via SPI) => Cannot be changed, it's built in!
        #define SPISD_CS                     4          // GPIO for chip select (SD)
        #ifndef SINGLE_SPI_ENABLE
            #define SPISD_MOSI              23          // GPIO for master out slave in (SD) => not necessary for single-SPI
            #define SPISD_MISO              19          // GPIO for master in slave ou (SD) => not necessary for single-SPI
            #define SPISD_SCK               18          // GPIO for clock-signal (SD) => not necessary for single-SPI
        #endif
    #endif

    // RFID (via SPI)
    #define RST_PIN                         99          // Not necessary but has to be set anyway; so let's use a dummy-number
    #define RFID_CS                         99//21          // GPIO for chip select (RFID)
    #define RFID_MOSI                       99//13          // GPIO for master out slave in (RFID)
    #define RFID_MISO                       99//15          // GPIO for master in slave out (RFID)
    #define RFID_SCK                        99//14          // GPIO for clock-signal (RFID)

    #ifdef RFID_READER_TYPE_PN5180
        #define RFID_BUSY                   99//33          // PN5180 BUSY PIN
        #define RFID_RST                    99//22          // PN5180 RESET PIN
        #define RFID_IRQ                    99//39          // PN5180 IRQ PIN (only needed for low power card detection)
    #endif
    // I2S (DAC)
    #define I2S_DOUT                        25          // Digital out (I2S)
    #define I2S_BCLK                        27          // BCLK (I2S)
    #define I2S_LRC                         26          // LRC (I2S)

    // Rotary encoder
    #ifdef USEROTARY_ENABLE
        #define ROTARYENCODER_CLK           99//34          // If you want to reverse encoder's direction, just switch GPIOs of CLK with DT (in software or hardware)
        #define ROTARYENCODER_DT            99//39          // 39 = 'VN'; Info: Lolin D32 pro is using 35 for battery-voltage-monitoring!
        #define ROTARYENCODER_BUTTON        99//32          // (set to 99 to disable; 0->39 for GPIO; 100->115 for port-expander)
    #endif

    // Amp enable (optional)
    //#define GPIO_PA_EN                      112         // To enable amp for loudspeaker (GPIO or port-channel)
    //#define GPIO_HP_EN                      113         // To enable amp for headphones (GPIO or port-channel)
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
biologist79, 2021-11-28:
In general SPI-bus can be shared by multiple devices. If doing so, all SPI-devices share MOSI/MISO/SCK, but every SPI-devices needs a dedicated CS (chip select). If SPI should be shared this can be enabled for ESPuino via "SINGLE_SPI_ENABLE". However, I never got this working reliable with SD-SPI + RC522. And I never tested it for PN5180 + SD-SPI.
Unfortunately there's a bug with SD-SPI: when doing uploads sometimes because of and internal error (guess it's an ESP32-Arduino-problem) ESP32 stops writing to SD-card. Have not been able to solve this so far.

I'd strongly suggest to use SD_MMC instead of SD-SPI because...
- SD_MMC only needs 3 PINs
- SD_MMC is faster
- SD_MMC does not show this upload-problem

To address this, I developed a PCB that makes use of Lolin D32 pro but with an external SD-Module: https://forum.espuino.de/t/lolin-d32-pro-mit-sd-mmc-pn5180-max-fuenf-buttons-und-port-expander-smd/638

GeneralLuzi, 2021-11-28:
I tested "SINGLE_SPI_ENABLE" on with the PN5180.

The behavior is strange: The SD card issue is gone - however, any rfid card is recognized.  Also I double checked the pin allocation... seems not to work...

GeneralLuzi, 2021-11-28:
also the sound is not working...

GeneralLuzi, 2021-12-03:
I propose to update the HAL for "settings-lolin_d32_pro.h" and refer to this behavior. I was not fully aware of that issue with the build-in sd card.

Now having an external sd card reader and a d32 pro it greatly works... Having had this within the comments beforehand it might saved a lot of time...

Thanks for your hints (and of course your time to reply!)

Please feel free to close this issue.

biologist79, 2021-12-03:
This is already covered:
https://github.com/biologist79/ESPuino/blob/master/src/settings-lolin_d32_pro.h#L22

Closed 2021-12-03.

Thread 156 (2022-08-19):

Battery Visualization while Charging

SZenglein, 2022-08-19:
I have been asked if it were possible to display charging progress while plugged in and turned off. Apparently it can be annoying to not see the charging state easily.

As this is not straightforward to implement, I want to gather a few ideas. Here is what I think is necessary:
* Hardware for "plugged-in" detection: charge controller or if USB has 5V
* A separate charging "off" state: muted, only LED active
* (Optional) An interrupt for instantly detecting being plugged in/out

Maybe it could be implemented without much effort by keeping the LEDs powered on in Deepsleep and waking up every few seconds to update the charging state.
Alternatively, just idling with everything off and only showing percentage on the regular button combination would be a good solution.

biologist79, 2022-08-19:
This is already possible using my [fepo](https://forum.espuino.de/t/esp32-develboard-d32-pro-lifepo4/1109) or [lipo](https://forum.espuino.de/t/esp32-develboard-e32-lipo/1135)-board. TP5000 provides a pin to indicate charge-state, so I routed it to a breakout pin "CHRG" of the develboard.
Please note: this pin is already used by the chrg-LED soldered on the develboard. Keep this in mind if you want to connect another LED. If this LED is removed, this chrg-pin could be connected to the port-expander. As chrg changes it's state when chrg is done, an interrupt is fired in this case. This would cause the ESP to wake up.

Closed 2022-10-17.

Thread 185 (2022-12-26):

Crash when mashing button and reading tag

fschrempf, 2022-12-26:
When repeatedly mashing the `BUTTON_3` assigned to `CMD_MEASUREBATTERY` and having an ISO-15693 tag in range at the same time the system crashes with the following stack trace:

```
[ 83208 ]  Aktuelle Batteriespannung: 3.27 V
[ 83210 ]  Aktuelle Batterieladung: 87.48 %
Guru Meditation Error: Core  0 panic'ed (Unhandled debug exception)
Debug exception reason: Stack canary watchpoint triggered (rfid)
Core 0 register dump:
PC      : 0x4009bcf7  PS      : 0x00060436  A0      : 0x40092958  A1      : 0x3ffdba20
A2      : 0x3ffdc0cc  A3      : 0x3ffdbdf0  A4      : 0x3f4008b0  A5      : 0x3ffdbf40
A6      : 0x3ffdbec0  A7      : 0x00000008  A8      : 0x8012ca22  A9      : 0x3ffdbac0
A10     : 0x3f41ea43  A11     : 0x00060423  A12     : 0x00060420  A13     : 0x00000000
A14     : 0x00000000  A15     : 0x00000000  SAR     : 0x0000000a  EXCCAUSE: 0x00000001
EXCVADDR: 0x00000000  LBEG    : 0x4010a99c  LEND    : 0x4010a9a9  LCOUNT  : 0x00000000

ELF file SHA256: 0000000000000000

Backtrace: 0x4009bcf7:0x3ffdba20 0x40092955:0x3ffdbdf0 0x401372b2:0x3ffdbe80 0x4010bfa2:0x3ffdbec0 0x400d847c:0x3ffdbf60 0x400d8e59:0x3ffdbf80 0x400992de:0x3ffdbfd0
  #0  0x4009bcf7:0x3ffdba20 in _frxt_int_enter at /home/runner/work/esp32-arduino-lib-builder/esp32-arduino-lib-builder/esp-idf/components/freertos/portasm.S:106
  #1  0x40092955:0x3ffdbdf0 in _xt_lowint1 at /home/runner/work/esp32-arduino-lib-builder/esp32-arduino-lib-builder/esp-idf/components/freertos/xtensa_vectors.S:1139
  #2  0x401372b2:0x3ffdbe80 in vsnprintf at /Users/ivan/e/newlib_xtensa-2.2.0-bin/newlib_xtensa-2.2.0/xtensa-esp32-elf/newlib/libc/stdio/../../../.././newlib/libc/stdio/vsnprintf.c:41
  #3  0x4010bfa2:0x3ffdbec0 in Print::printf(char const*, ...) at /home/frieder/.platformio/packages/framework-arduinoespressif32@src-5ca93290a197adbe2ee160f158f219df/cores/esp32/Print.cpp:261
  #4  0x400d847c:0x3ffdbf60 in Log_Print(char const*, unsigned char, bool) at src/Log.cpp:41
  #5  0x400d8e59:0x3ffdbf80 in Rfid_Task(void*) at src/RfidPn5180.cpp:340
  #6  0x400992de:0x3ffdbfd0 in vPortTaskWrapper at /home/runner/work/esp32-arduino-lib-builder/esp32-arduino-lib-builder/esp-idf/components/freertos/port.c:355 (discriminator 1)

fschrempf, 2022-12-26:
Forget about it. Seems to be a bug I introduced myself when adding debugging logs...

Closed 2022-12-26.

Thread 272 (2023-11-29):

Remove convertAsciiToUtf8()

orempel, 2023-11-29:
Moin!

With the change to Arduino v2 "everything" is utf8 ready. Which means that the `convertAsciiToUtf8()` function is actually doing more harm that good:  playing some files result in constant errors in the terminal and no updates in the web interface:

```
I [21103] Kommando: Nächster Titel
I [21116] info        : Closing audio file
I [21131] info        : buffers freed, free Heap: 87180 bytes
I [21131] info        : Reading file: "/Giraffenaffen/Giraffenaffen 1/03-Hätt’ ich Dich heut’ erwartet (feat. Roman Lob).mp3"
I [21185] info        : MP3Decoder has been initialized, free Heap: 59360 bytes , free stack 2948 DWORDs
N [21189] '/Giraffenaffen/Giraffenaffen 1/03-Hätt’ ich Dich heut’ erwartet (feat. Roman Lob).mp3' wird abgespielt (3 von 17)D [21193] ws[/ws][1] error(1002): Invalid UTF-8 in text frame":3,"numberOﾭ�xV��K�?Q
D [21210] ws[/ws][1] disconnect
...
D [27104] ws[/ws][2] connect
D [27199] ws[/ws][2] error(1002): Invalid UTF-8 in text frame"],"active":ﾭ�xV����?0
D [27200] ws[/ws][2] disconnect
D [32940] ws[/ws][3] connect
D [33031] ws[/ws][3] error(1002): Invalid UTF-8 in text frame"],"active":ﾭ�xV����?0
D [33031] ws[/ws][3] disconnect
D [38878] ws[/ws][4] connect
D [38971] ws[/ws][4] error(1002): Invalid UTF-8 in text frame"],"active":ﾭ�xV����?�
D [38972] ws[/ws][4] disconnect
```

I will create a PR for that, but just want to ask if it make sense to rip out `convertFilenameToAscii()` as well. That function was updated for the utf8 change and is now just copying c-strings around.

Thanks!

tueddy, 2023-11-30:
`convertAsciiToUtf8()` is obsolete and can be removed. Copying arround was just for smooth porting to Arduino 2.
But i think removing does not fix `error(1002): Invalid UTF-8 in text frame"],"active":ﾭ�xV����?0` ?

orempel, 2023-11-30:
I've already checked that, removing `convertAsciiToUtf8()` fixes the problem.

And I've found out that the character ( ´ ) that looks like a single quote ( ' ) is actually U+2019. Which has/had its own code 0x92 in codepage windows-1252. (It seems the title name was created on a system using that codepage and/or someone who *really* likes utf8 codes).

U+2019 gets utf8 encoded as 0xe2 0x80 0x99. And the 0x99 (which is a 'Ö' in cp437) gets converted by `convertAsciiToUtf8()` into 0xc3 0x96. The result 0xe2 0x80 0xc3 0x96 in an invalid utf8 sequence, which crashes the webinterface. Q.E.D.

Thank you wikipedia for this (unwanted!) knowledge about codepages...

Back to the topic of fixing this:
There are four calls to `convertAsciiToUtf8()`, one of them is done inside `Web_DumpSdToNvs()`.
That function handles restoring a sd-card backup back to the nvs. I'm currently not sure if that place needs backwards compability code or not.

My current version is this: https://github.com/orempel/ESPuino/commit/f94377f74fde6f55c12c54eaa851bdeca7ec1b89

tueddy, 2023-11-30:
LGTM!

For backward compatibility:
Old master used Arduino 1 FS, it should be ANSI/OEM-852. For current master we have Arduino 2 FS with utf-8.
We now write a UTF-8 BOM marker into backup file, older backup without BOM, see
https://forum.espuino.de/t/nvs-kaputt-und-probleme-mit-umlauten-bei-backup-txt/2202/13

For correct import from old version we should make a character conversion from OEM-852 to UTF-8, this might be the reason for the line in `Web_DumpSdToNvs()`. Maybe this version from Arduino 1 branch does the right job for import?

https://github.com/biologist79/ESPuino/blob/d5c7ab44d49c67079cf8eeb3fc248e04a54734db/src/Common.h#L98

Another possibility would be to leave it as it is and the user has to save the backup once, e.g. with Notepad++ with new encoding

Closed 2024-02-08.

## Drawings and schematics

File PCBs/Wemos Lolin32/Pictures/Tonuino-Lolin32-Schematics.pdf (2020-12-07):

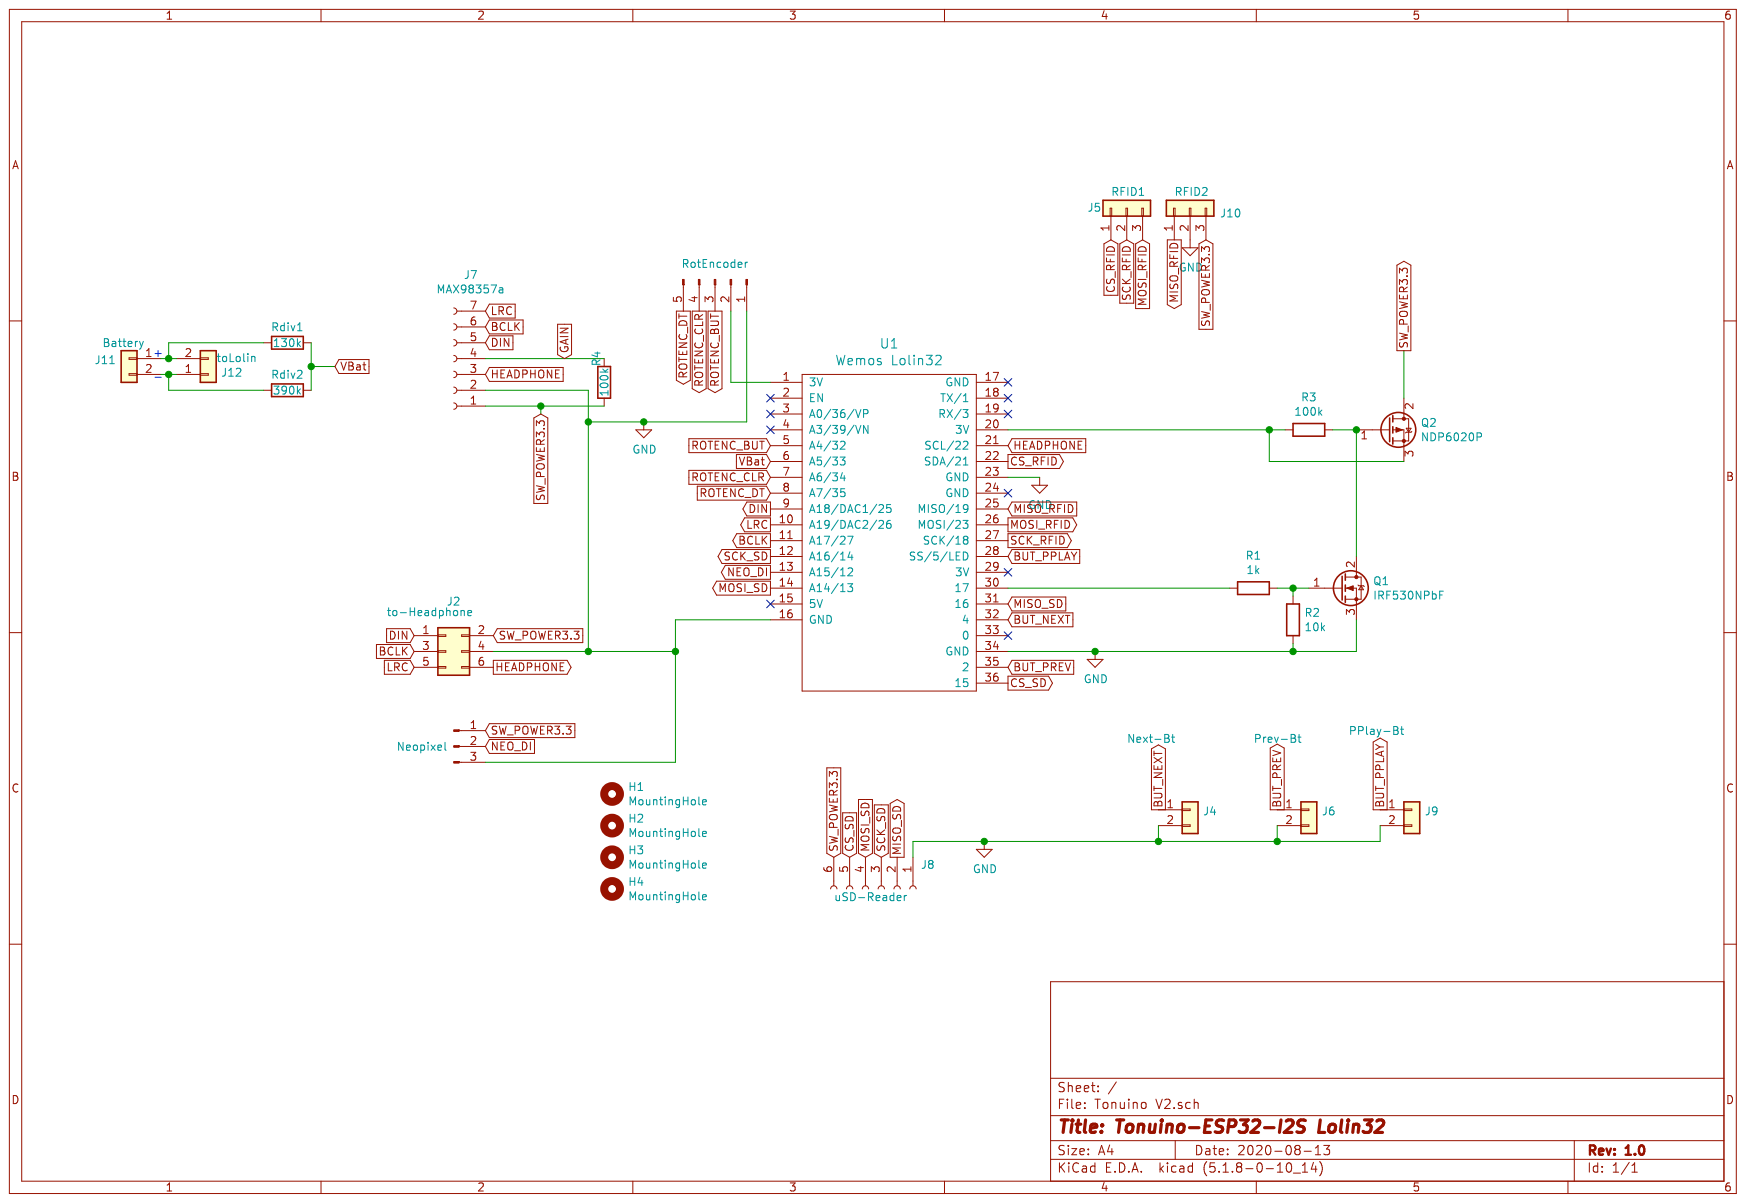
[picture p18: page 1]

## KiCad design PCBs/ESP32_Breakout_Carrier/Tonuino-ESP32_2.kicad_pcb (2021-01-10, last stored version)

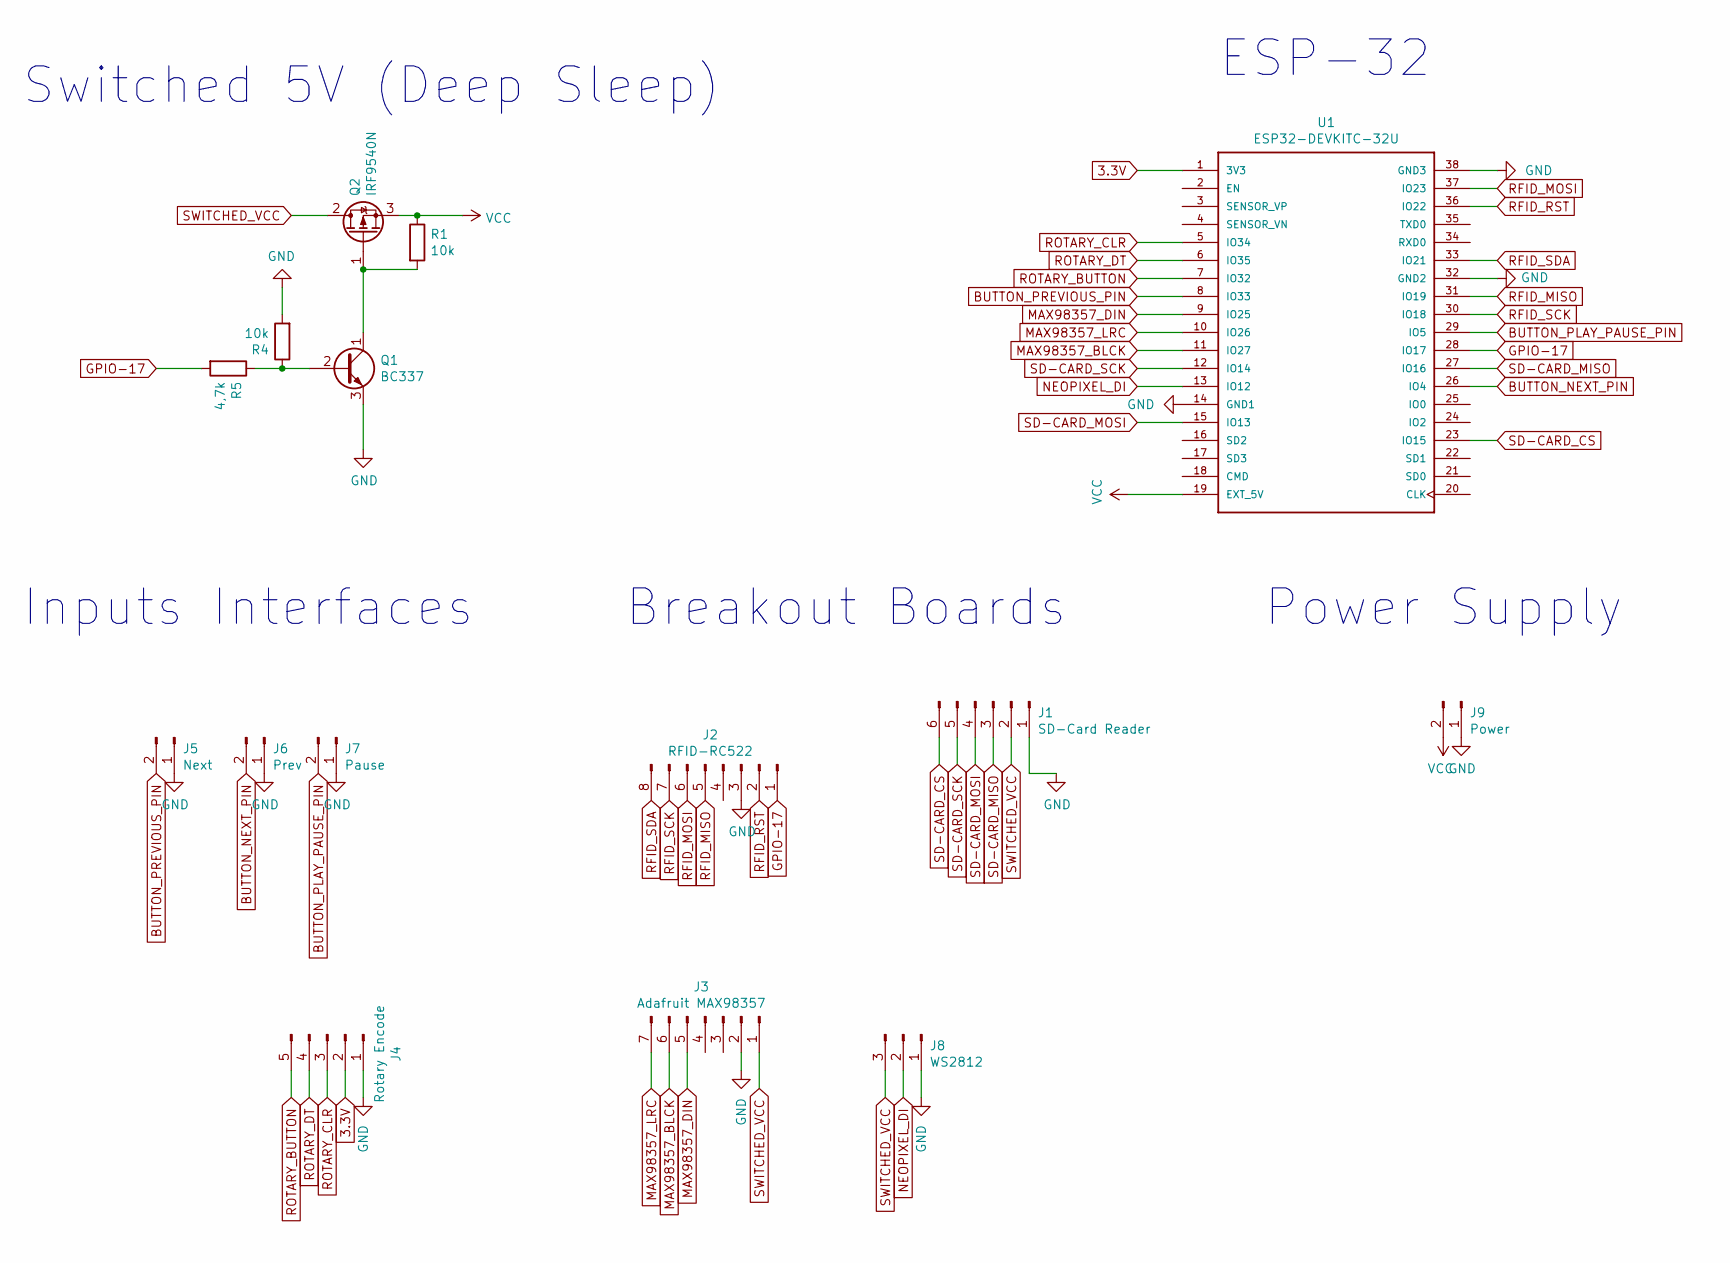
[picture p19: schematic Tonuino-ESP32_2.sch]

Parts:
J1: SD-Card Reader; PinHeader_1x06_P2.54mm_Vertical
J2: RFID-RC522; PinHeader_1x08_P2.54mm_Vertical
J3: Adafruit MAX98357; PinHeader_1x07_P2.54mm_Vertical
J4: Rotary Encode; PinHeader_1x05_P2.54mm_Vertical
J5: Next; PinHeader_1x02_P2.54mm_Vertical
J6: Prev; PinHeader_1x02_P2.54mm_Vertical
J7: Pause; PinHeader_1x02_P2.54mm_Vertical
J8: WS2812; PinHeader_1x03_P2.54mm_Vertical
J9: Power; PinHeader_1x02_P2.54mm_Vertical
Q1: BC337; TO-92_Inline_Wide
Q2: IRF9540N; TO-220-3_Vertical
R1, R4: 10k; 0207_9
R5: 4,7k; 0207_9
U1: ESP32-DEVKITC-32U; MODULE_ESP32-DEVKITC-32U

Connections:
3.3V: J4.2, U1.1 (3V3)
BUTTON_NEXT_PIN: J6.2, U1.26 (IO4)
BUTTON_PLAY_PAUSE_PIN: J7.2, U1.29 (IO5)
BUTTON_PREVIOUS_PIN: J5.2, U1.8 (IO33)
GND: J1.1, J2.3, J3.2, J4.1, J5.1, J6.1, J7.1, J8.1, J9.1, Q1.3 (E), R4.2, U1.14 (GND1), U1.32 (GND2), U1.38 (GND3)
GPIO-17: J2.1, R5.2, U1.28 (IO17)
MAX98357_BLCK: J3.6, U1.11 (IO27)
MAX98357_DIN: J3.5, U1.9 (IO25)
MAX98357_LRC: J3.7, U1.10 (IO26)
NEOPIXEL_DI: J8.2, U1.13 (IO12)
unnamed: Q1.1 (C), Q2.1 (G), R1.2
unnamed: Q1.2 (B), R4.1, R5.1
RFID_MISO: J2.5, U1.31 (IO19)
RFID_MOSI: J2.6, U1.37 (IO23)
RFID_RST: J2.2, U1.36 (IO22)
RFID_SCK: J2.7, U1.30 (IO18)
RFID_SDA: J2.8, U1.33 (IO21)
ROTARY_BUTTON: J4.5, U1.7 (IO32)
ROTARY_CLR: J4.3, U1.5 (IO34)
ROTARY_DT: J4.4, U1.6 (IO35)
SD-CARD_CS: J1.6, U1.23 (IO15)
SD-CARD_MISO: J1.3, U1.27 (IO16)
SD-CARD_MOSI: J1.4, U1.15 (IO13)
SD-CARD_SCK: J1.5, U1.12 (IO14)
SWITCHED_VCC: J1.2, J3.1, J8.3, Q2.2 (D)
VCC: J9.2, Q2.3 (S), R1.1, U1.19 (EXT_5V)

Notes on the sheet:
Breakout Boards
Inputs Interfaces
Switched 5V (Deep Sleep)
ESP-32
Power Supply

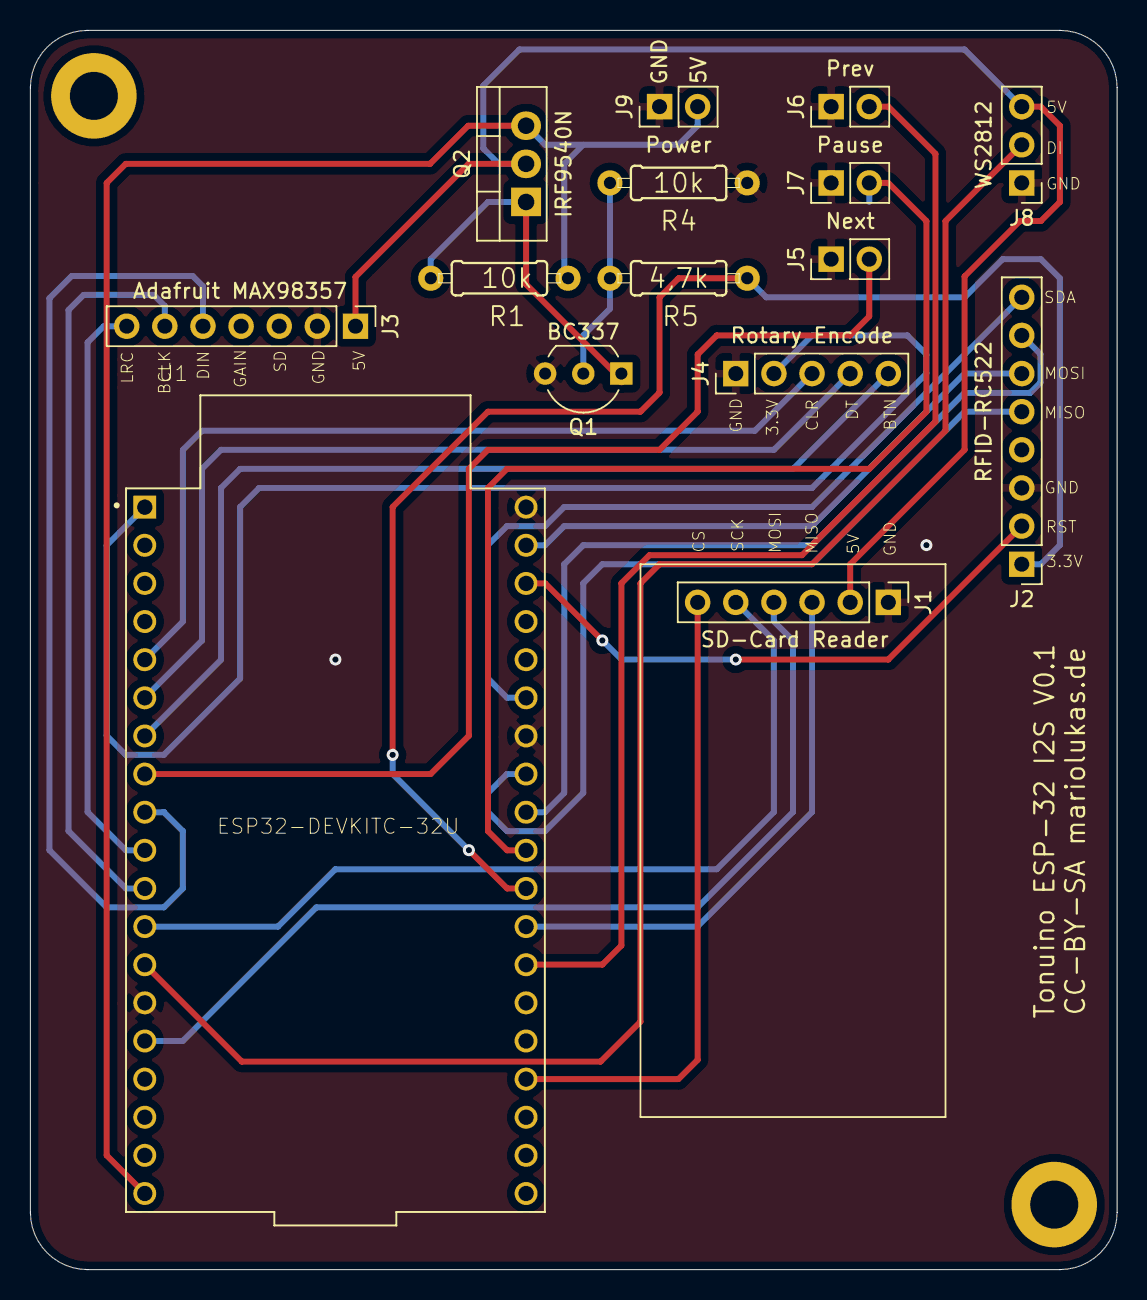
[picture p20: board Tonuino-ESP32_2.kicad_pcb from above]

Board: 2 copper layers, 72.4 x 82.6 mm, 15 parts (0 on the bottom side), 26 nets.

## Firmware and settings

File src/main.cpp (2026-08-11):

// !!! MAKE SURE TO EDIT settings.h !!!
#include <Arduino.h>
#include "settings.h" // Contains all user-relevant settings (general)

#include "main.h"

#include "AudioPlayer.h"
#include "Battery.h"
#include "Bluetooth.h"
#include "Button.h"
#include "Cmd.h"
#include "Common.h"
#include "Ftp.h"
#include "HallEffectSensor.h"
#include "IrReceiver.h"
#include "Led.h"
#include "Log.h"
#include "MemX.h"
#include "Mqtt.h"
#include "Port.h"
#include "Power.h"
#include "Queues.h"
#include "Rfid.h"
#include "RfidConfig.h"
#include "RotaryEncoder.h"
#include "SdCard.h"
#include "System.h"
#include "Web.h"
#include "Wlan.h"
#include "gitrevision.h"

#include <Wire.h>

bool gRetryRfidOnWifiConnect = false;
char gRetryRfidTagId[cardIdStringSize] = "";

static constexpr const char *logo = R"literal(
 _____   ____    ____            _
| ____| / ___|  |  _ \   _   _  (_)  _ __     ___
|  _|   \__  \  | |_) | | | | | | | | '_ \   / _ \
| |___   ___) | |  __/  | |_| | | | | | | | | (_) |
|_____| |____/  |_|      \__,_| |_| |_| |_|  \___/
         Rfid-controlled musicplayer


)literal";

// avoid PSRAM check while wake-up from deepsleep
bool testSPIRAM(void) {
	return true;
}

bool recoverLastRfid = true;
bool recoverBootCount = true;
bool resetBootCount = false;
uint32_t bootCount = 0;

////////////

// I2C
#ifdef I2C_2_ENABLE
TwoWire i2cBusTwo = TwoWire(1);
#endif

// If a problem occurs, remembering last rfid can lead into a boot loop that's hard to escape of.
// That reason for a mechanism is necessary to prevent this.
// At start of a boot, bootCount is incremented by one and after 30s decremented because
// uptime of 30s is considered as "successful boot".
void recoverBootCountFromNvs(void) {
	if (recoverBootCount) {
		recoverBootCount = false;
		resetBootCount = true;
		bootCount = gPrefsSettings.getUInt("bootCount", 999);

		if (bootCount == 999) { // first init
			bootCount = 1;
			gPrefsSettings.putUInt("bootCount", bootCount);
		} else if (bootCount >= 3) { // considered being a bootloop => don't recover last rfid!
			bootCount = 1;
			gPrefsSettings.putUInt("bootCount", bootCount);
			gPrefsSettings.putString("lastRfid", "-1"); // reset last rfid
			Log_Println(bootLoopDetected, LOGLEVEL_ERROR);
			recoverLastRfid = false;
		} else { // normal operation
			gPrefsSettings.putUInt("bootCount", ++bootCount);
		}
	}

	if (resetBootCount && millis() >= 30000) { // reset bootcount
		resetBootCount = false;
		bootCount = 0;
		gPrefsSettings.putUInt("bootCount", bootCount);
		Log_Println(noBootLoopDetected, LOGLEVEL_INFO);
	}
}

// Get last RFID-tag applied from NVS
void recoverLastRfidPlayedFromNvs(bool force) {
	if (recoverLastRfid || force) {
		if (System_GetOperationMode() == OPMODE_BLUETOOTH_SINK) { // Don't recover if BT-mode is desired
			recoverLastRfid = false;
			return;
		}
		recoverLastRfid = false;
		String lastRfidPlayed = gPrefsSettings.getString("lastRfid", "-1");
		if (!lastRfidPlayed.compareTo("-1")) {
			Log_Println(unableToRestoreLastRfidFromNVS, LOGLEVEL_INFO);
		} else {
			xQueueSend(gRfidCardQueue, lastRfidPlayed.c_str(), 0);
			Log_Printf(LOGLEVEL_INFO, restoredLastRfidFromNVS, lastRfidPlayed.c_str());
		}
	}
}

void setup() {
	Log_Init();
	Queues_Init();

	// Make sure all wakeups can be enabled *before* initializing RFID, which can enter sleep immediately
	Button_Init(); // To preseed internal button-storage with values

	System_Init_Rfid_Prefs();
	const bool pn5180LpcdEnabled = gPrefsRfid.getBool("pn5180Lpcd", false);
	if (pn5180LpcdEnabled) {
		// Only handle a possible deep-sleep wakeup here; starting the RFID scanning task
		// this early raced with the peripheral init below and could hang the boot (see
		// Rfid_StartTask() call further down).
		Rfid_WakeupHandling();
	}
	System_Init();

// Init 2nd i2c-bus if RC522 is used with i2c or if port-expander is enabled
#ifdef I2C_2_ENABLE
	i2cBusTwo.begin(ext_IIC_DATA, ext_IIC_CLK);
	delay(50);
	Log_Println(rfidScannerReady, LOGLEVEL_DEBUG);
#endif

#ifdef HALLEFFECT_SENSOR_ENABLE
	gHallEffectSensor.init();
#endif

	// Needs i2c first if port-expander is used
	Port_Init();

	// If port-expander is used, port_init has to be called first, as power can be (possibly) done by port-expander
	Power_Init();

	Battery_Init();

	// Init audio before power on to avoid speaker noise
	AudioPlayer_Init();

	// All checks that could send us to sleep are done, power up fully
	Power_PeripheralOn();

	Led_Init();

	// Needs power first
	SdCard_Init();

	// welcome message
	Serial.print(logo);

	// Software-version
	Log_Println(softwareRevision, LOGLEVEL_NOTICE);
	Log_Println(gitRevision, LOGLEVEL_NOTICE);
	Log_Printf(LOGLEVEL_NOTICE, "Arduino version: %d.%d.%d", ESP_ARDUINO_VERSION_MAJOR, ESP_ARDUINO_VERSION_MINOR, ESP_ARDUINO_VERSION_PATCH);
	Log_Printf(LOGLEVEL_NOTICE, "ESP-IDF version: %s", ESP.getSdkVersion());

	// print wake-up reason
	System_ShowWakeUpReason();
	// print SD card info
	SdCard_PrintInfo();

	Ftp_Init();
	if (!pn5180LpcdEnabled) {
		Rfid_Init();
	} else {
		// Peripherals are up now, safe to start the scanning task deferred above.
		Rfid_StartTask();
	}
	RotaryEncoder_Init();
	Bluetooth_Init();
	Wlan_Init();
	Mqtt_Init();

	if (OPMODE_NORMAL == System_GetOperationMode()) {
		Wlan_Cyclic();
	}

	IrReceiver_Init();
	System_UpdateActivityTimer(); // initial set after boot
	Led_Indicate(LedIndicatorType::BootComplete);

	Log_Printf(LOGLEVEL_DEBUG, "%s: %u", freeHeapAfterSetup, ESP.getFreeHeap());
	if (psramFound()) {
		Log_Printf(LOGLEVEL_DEBUG, "PSRAM: %u bytes", ESP.getPsramSize());
	} else {
		Log_Println("PSRAM: --", LOGLEVEL_DEBUG);
	}
	Log_Printf(LOGLEVEL_DEBUG, "Flash-size: %u bytes", ESP.getFlashChipSize());

	// setup timezone & show internal RTC date/time if available
	setenv("TZ", timeZone, 1);
	tzset();
	struct tm timeinfo;
	if (getLocalTime(&timeinfo, 5)) {
		static char timeStringBuff[255];
		snprintf(timeStringBuff, sizeof(timeStringBuff), dateTimeRTC, timeinfo.tm_mday, timeinfo.tm_mon + 1, timeinfo.tm_year + 1900, timeinfo.tm_hour, timeinfo.tm_min, timeinfo.tm_sec);
		Log_Println(timeStringBuff, LOGLEVEL_DEBUG);
	}

	if (Wlan_IsConnected()) {
		Log_Printf(LOGLEVEL_DEBUG, "RSSI: %d dBm", Wlan_GetRssi());
	}

#ifdef CONTROLS_LOCKED_BY_DEFAULT
	System_SetLockControls(true);
#endif
}

void loop() {
	Wlan_Cyclic();
	Web_Cyclic();
	if (OPMODE_BLUETOOTH_SINK == System_GetOperationMode()) {
		// bluetooth speaker mode
		Bluetooth_Cyclic();
	} else if (OPMODE_BLUETOOTH_SOURCE == System_GetOperationMode()) {
		// bluetooth headset mode
		Bluetooth_Cyclic();
	}
	RotaryEncoder_Cyclic();
	Ftp_Cyclic();
	AudioPlayer_Cyclic();
	Battery_Cyclic();
	Button_Cyclic();
	System_Cyclic();
	Rfid_PreferenceLookupHandler();

	if (gPrefsSettings.getBool("playLastOnBoot", false)) {
		recoverBootCountFromNvs();
		recoverLastRfidPlayedFromNvs();
	}

	IrReceiver_Cyclic();

#ifdef HALLEFFECT_SENSOR_ENABLE
	gHallEffectSensor.cyclic();
#endif

	vTaskDelay(portTICK_PERIOD_MS * 6u);
}

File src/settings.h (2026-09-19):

// clang-format off

#ifndef __ESPUINO_SETTINGS_H__
    	#define __ESPUINO_SETTINGS_H__
        #include "Arduino.h"
        #include "values.h"
#if __has_include("settings-override.h")
    	#include "settings-override.h"
#else
	//######################### INFOS ####################################
	// This is the general configfile for ESPuino-configuration.

	//################## HARDWARE-PLATFORM ###############################
	/* Make sure to also edit the configfile, that is specific for your platform.
	If in doubts (your board is not listed) use HAL 7

	!!!Only ESP32 with PSRAM are supported!!!

	HAL 4: Wemos Lolin D32 pro                  => settings-lolin_D32_pro.h
	HAL 5: Lilygo T8 (V1.7)                     => settings-ttgo_t8.h
	HAL 6: ESPuino complete                     => settings-complete.h
	HAL 7: Lolin D32 pro SDMMC Port-Expander    => settings-lolin_d32_pro_sdmmc_pe.h
	HAL 99: custom                              => settings-custom.h
	*/
	#ifndef HAL             // Will be set by platformio.ini. There's no need to adjust this manually right here
		#define HAL 7
	#endif

	// Enforce port expander for some HALs because it's mandatory for those and users constantly forget it. Endless story...
	#if (HAL == 6) || (HAL == 7)
		#define PORT_EXPANDER_ENABLE 
	#endif

	//########################## MODULES #################################
	//#define PORT_EXPANDER_ENABLE          // When enabled, buttons can be connected via port-expander PCA9555 (https://forum.espuino.de/t/einsatz-des-port-expanders-pca9555/306)
	//#define I2S_COMM_FMT_LSB_ENABLE       // Enables FMT instead of MSB for I2S-communication-format. Used e.g. by PT2811. Don't enable for MAX98357a, AC101 or PCM5102A)
	#define MDNS_ENABLE                     // When enabled, you don't have to handle with ESPuino's IP-address. If hostname is set to "ESPuino", you can reach it via ESPuino.local
	#define MQTT_ENABLE                     // Make sure to configure mqtt-server and (optionally) username+pwd
	#define FTP_ENABLE                      // Enables FTP-server; DON'T FORGET TO ACTIVATE AFTER BOOT BY PRESSING PAUSE + NEXT-BUTTONS (IN PARALLEL)!
	#define NEOPIXEL_ENABLE                 // Don't forget configuration of NUM_LEDS if enabled
	#define LANGUAGE DE                     // DE = deutsch; EN = english: FR = french
	#define HEADPHONE_ADJUST_ENABLE         // Used to adjust (lower) volume for optional headphone-pcb (refer maxVolumeSpeaker / maxVolumeHeadphone) and to enable stereo (headphones are always stereo, even if mono-playback is enabled via GUI)
	#define SHUTDOWN_IF_SD_BOOT_FAILS       // Will put ESP to deepsleep if boot fails due to SD. Really recommend this if there's in battery-mode no other way to restart ESP! Interval adjustable via deepsleepTimeAfterBootFails.
	#define MEASURE_BATTERY_VOLTAGE         // Enables battery-measurement via GPIO (ADC) and voltage-divider
	#define USEROTARY_ENABLE                // If rotary-encoder is used (don't forget to review WAKEUP_BUTTON if you disable this feature!)
	#define BLUETOOTH_ENABLE                // If enabled and bluetooth-mode is active, you can stream to your ESPuino or to a headset via bluetooth (a2dp-sink & a2dp-source). Note: This feature consumes a lot of resources and the available flash/ram might not be sufficient.
	//#define IR_CONTROL_ENABLE             // Enables remote control (https://forum.espuino.de/t/neues-feature-fernsteuerung-per-infrarot-fernbedienung/265)
	//#define HALLEFFECT_SENSOR_ENABLE      // Support for hallsensor. For fine-tuning please adjust HallEffectSensor.h Please note: only user-support provided (https://forum.espuino.de/t/magnetische-hockey-tags/1449/35)

	//################## select SD card mode #############################
	#define SD_MMC_1BIT_MODE              // run SD card in SD-MMC 1Bit mode (using GPIOs 15 + 14 + 2 is mandatory!)
	//#define SINGLE_SPI_ENABLE             // If only one SPI-instance should be used instead of two (not yet working!)
	//#define NO_SDCARD                     // enable to start without any SD card, e.g. for a webplayer only. SD card Settings above will be ignored


	//################## select RFID reader ##############################
	// Runtime RFID reader selection is now supported via web interface
	// Runtime RFID reader type configuration
	// 0 = Auto-detect
	// 1 = MFRC522 (SPI)
	// 2 = MFRC522 (I2C)
	// 3 = PN5180
	#define RFID_READER_TYPE_RUNTIME 0    // Default to Auto-detect

	#if defined(RFID_READER_TYPE_RUNTIME)
		#define MFRC522_ADDR 0x28           // default I2C-address of MFRC522
	#endif

	//############# Port-expander-configuration ######################
	#ifdef PORT_EXPANDER_ENABLE
		constexpr uint8_t expanderI2cAddress = 0x20;  // I2C-address of PCA9555 (0x20 is true if PCA's pins A0+A1+A2 are pulled to GND)
	#endif
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

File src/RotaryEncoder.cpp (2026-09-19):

#include <Arduino.h>
#include "settings.h"

#include "RotaryEncoder.h"

#include "AudioPlayer.h"
#include "Bluetooth.h"
#include "Button.h"
#include "Cmd.h"
#include "Log.h"
#include "System.h"

#ifdef USEROTARY_ENABLE
	#include <ESP32Encoder.h>
#endif

// Rotary encoder-configuration
#ifdef USEROTARY_ENABLE
ESP32Encoder encoder;
// Rotary encoder-helper
int32_t lastEncoderValue;
int32_t currentEncoderValue;
int32_t lastVolume = -1; // Don't change -1 as initial-value!
#endif

void RotaryEncoder_Init(void) {
// Init rotary encoder
#ifdef USEROTARY_ENABLE
	if (encoder.isAttached()) {
		encoder.detach();
	}
	#ifdef REVERSE_ROTARY
	const bool bReverse = true;
	#else
	const bool bReverse = false;
	#endif
	if (gPrefsSettings.getBool("rotaryReverse", bReverse)) {
		encoder.attachHalfQuad(ROTARYENCODER_DT, ROTARYENCODER_CLK);
	} else {
		encoder.attachHalfQuad(ROTARYENCODER_CLK, ROTARYENCODER_DT);
	}
	encoder.clearCount();
#endif
}

// Handles volume directed by rotary encoder
void RotaryEncoder_Cyclic(void) {
#ifdef USEROTARY_ENABLE
	// Tracks whether the currently-held modifier (if any) was resolved to CMD_SEEK_PREVIEW, i.e. whether
	// this hold-gesture is a seek-preview session rather than the generic per-detent-command dispatch below.
	static bool previewGestureActive = false;
	static uint8_t lastModifier = BUTTON_NONE;

	#ifdef INCLUDE_ROTARY_IN_CONTROLS_LOCK
	if (System_AreControlsLocked()) {
		if (previewGestureActive) {
			AudioPlayer_SeekPreviewCommit(); // don't leave a preview hanging if controls get locked mid-gesture
			previewGestureActive = false;
			lastModifier = BUTTON_NONE;
		}
		encoder.clearCount();
		return;
	}
	#endif

	// A button held down while turning acts as a modifier: the turn drives that button's rotary action
	// (brightness, seek, ...) instead of the volume. getCount() is stateful across ticks -- it keeps a
	// half-step that has not completed a detent yet -- so discard whatever has accumulated whenever the
	// modifier changes, otherwise a gesture inherits rotation from before the button went down (and the
	// volume inherits rotation from during the gesture).
	const uint8_t modifier = Button_GetHeldModifier();
	if (modifier != lastModifier) {
		if (previewGestureActive) {
			// Release (or switch to a different modifier) commits immediately -- don't make the user wait
			// out the idle-delay just because they let go of the button.
			AudioPlayer_SeekPreviewCommit();
			previewGestureActive = false;
		}
		lastModifier = modifier;
		encoder.clearCount();
		if (modifier != BUTTON_NONE) {
			// Either direction mapping to CMD_SEEK_PREVIEW makes the whole hold a preview session -- a
			// preview is inherently bidirectional, so a button with only one direction assigned to it
			// still previews both ways (the other direction falls back from volume to preview too, since
			// there is no other sensible meaning for "turn while holding this preview-mapped button").
			previewGestureActive = (Button_GetRotaryAction(modifier, true) == CMD_SEEK_PREVIEW) || (Button_GetRotaryAction(modifier, false) == CMD_SEEK_PREVIEW);
			if (previewGestureActive) {
				AudioPlayer_SeekPreviewStart();
			}
		}
		return;
	}

	int32_t encoderValue = encoder.getCount();
	// Only if initial run or value has changed. And only after "full step" of rotary encoder
	if ((encoderValue != 0) && (encoderValue % 2 == 0)) {
		System_UpdateActivityTimer(); // Set inactivity back if rotary encoder was used
		// just reset the encoder here, so we get a new delta next time
		encoder.clearCount();

		const int32_t detents = encoderValue / 2;

		if (modifier != BUTTON_NONE) {
			if (previewGestureActive) {
				// Swallow the held button's own short/long action, same as the generic gesture path below.
				Button_MarkModifierUsed(modifier);
				AudioPlayer_SeekPreviewAdjust(detents);
				return;
			}

			const uint8_t cmd = Button_GetRotaryAction(modifier, detents > 0);
			if (cmd != CMD_NOTHING) {
				// Tell Button.cpp to swallow this button's own short/long action -- otherwise letting go fires
				// e.g. play/pause, and holding past intervalToLongPress fires the long action mid-gesture.
				Button_MarkModifierUsed(modifier);

				if (cmd == CMD_SEEK_FORWARDS || cmd == CMD_SEEK_BACKWARDS) {
					// Seek is a magnitude, not a step: firing the command once per detent would jump the full
					// button step *each time*, so a flick of the encoder scrubs minutes. Apply the smaller
					// per-detent rotary step directly instead. Direction comes from the configured command, so
					// a user who maps CW to backwards still gets backwards.
					const int32_t step = gPrefsSettings.getUChar("rotSeekStep", SEEK_STEP_ROTARY_DEFAULT);
					const int32_t magnitude = abs(detents) * step;
					AudioPlayer_AddSeekOffset(static_cast<int16_t>((cmd == CMD_SEEK_FORWARDS) ? magnitude : -magnitude));
					return;
				}

				for (int32_t i = 0; i < abs(detents); i++) {
					Cmd_Action(cmd);
				}
				return;
			}
		}

		if ((OPMODE_NORMAL == System_GetOperationMode()) || (OPMODE_BLUETOOTH_SOURCE == System_GetOperationMode())) {
			auto newVol = AudioPlayer_GetCurrentVolume() + detents;
			AudioPlayer_SetVolume(newVol);
		} else {
			auto newVol = Bluetooth_GetCurrentVolume() + detents;
			Bluetooth_SetVolume(newVol);
		}
		return;
	}
#endif
}

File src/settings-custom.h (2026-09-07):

// clang-format off

#ifndef __ESPUINO_SETTINGS_CUSTOM_H__
#define __ESPUINO_SETTINGS_CUSTOM_H__
    #include "Arduino.h"

    //######################### INFOS ####################################
    /* This is not a develboard-specific config-file. It's intended for your own use.
    It's been originally derived from lolin32, but just change it according your needs!
    */

    //################## GPIO-configuration ##############################
    // Please note: GPIOs 34, 35, 36, 39 are input-only and don't have pullup-resistors.
    // So if connecting a button to these, make sure to add a 10k-pullup-resistor for each button.
    // Further infos: https://randomnerdtutorials.com/esp32-pinout-reference-gpios/
    #ifdef SD_MMC_1BIT_MODE
        // uSD-card-reader (via SD-MMC 1Bit)
        //
        // SD_MMC uses fixed pins
        //  (MOSI)    15  CMD
        //  (SCK)     14  SCK
        //  (MISO)     2  D0
    #else
        // uSD-card-reader (via SPI)
        #define SPISD_CS                    15          // GPIO for chip select (SD)
        #ifndef SINGLE_SPI_ENABLE
            #define SPISD_MOSI              13          // GPIO for master out slave in (SD) => not necessary for single-SPI
            #define SPISD_MISO              16          // GPIO for master in slave ou (SD) => not necessary for single-SPI
            #define SPISD_SCK               14          // GPIO for clock-signal (SD) => not necessary for single-SPI
        #endif
    #endif

    // RFID (via SPI)
    #define RST_PIN                         99          // Not necessary but has to be set anyway; so let's use a dummy-number
    #define RFID_CS                         21          // GPIO for chip select (RFID)
    #define RFID_MOSI                       23          // GPIO for master out slave in (RFID)
    #define RFID_MISO                       19          // GPIO for master in slave out (RFID)
    #define RFID_SCK                        18          // GPIO for clock-signal (RFID)

    #if defined(RFID_READER_TYPE_RUNTIME) 
        #define RFID_BUSY                   16          // PN5180 BUSY PIN
        #define RFID_RST                    22          // PN5180 RESET PIN
        #define RFID_IRQ                    39          // PN5180 IRQ PIN (only needed for low power card detection)
    #endif
    // I2S (DAC)
    #define I2S_DOUT                        25          // Digital out (I2S)
    #define I2S_BCLK                        27          // BCLK (I2S)
    #define I2S_LRC                         26          // LRC (I2S)

    // Rotary encoder
    #ifdef USEROTARY_ENABLE
        //#define REVERSE_ROTARY                        // To reverse encoder's direction; switching CLK / DT in hardware does the same
        #define ROTARYENCODER_CLK           34          // rotary encoder's CLK
        #define ROTARYENCODER_DT            35          // Info: Lolin D32 / Lolin D32 pro 35 are using 35 for battery-voltage-monitoring!
    #endif

    // Amp enable (optional)
    //#define GPIO_PA_EN                      112         // To enable amp for loudspeaker (GPIO or port-channel)
    //#define GPIO_HP_EN                      113         // To enable amp for headphones (GPIO or port-channel)

    // Control-buttons (set to 99 to DISABLE; 0->39 for GPIO; 100->115 for port-expander)
    #define NEXT_BUTTON                      4          // Button 0: GPIO to detect next
    #define PREVIOUS_BUTTON                  2          // Button 1: GPIO to detect previous (Important: as of 19.11.2020 changed from 33 to 2; make sure to change in SD-MMC-mode)
    #define PAUSEPLAY_BUTTON                 0          // Button 2: GPIO to detect pause/play
    #define ROTARYENCODER_BUTTON            32          // (set to 99 to disable; 0->39 for GPIO; 100->115 for port-expander)
    #define BUTTON_4                        99          // Button 4: unnamed optional button
    #define BUTTON_5                        99          // Button 5: unnamed optional button

    //#define BUTTONS_LED                   114         // Powers the LEDs of the buttons. Make sure the current consumed by the LEDs can be handled by the used GPIO

    // Channels of port-expander can be read cyclic or interrupt-driven. It's strongly recommended to use the interrupt-way!
    // Infos: https://forum.espuino.de/t/einsatz-des-port-expanders-pca9555/306
    #ifdef PORT_EXPANDER_ENABLE
        #define PE_INTERRUPT_PIN            99          // GPIO that is used to receive interrupts from port-expander
    #endif

    // I2C-configuration (necessary for RC522 [only via i2c - not spi!] or port-expander)
    #ifdef I2C_2_ENABLE
        #define ext_IIC_CLK                 4           // i2c-SCL (clock)
        #define ext_IIC_DATA                2           // i2c-SDA (data)
    #endif
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

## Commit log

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2020-12-13 * Add support for SD MMC 1 Bit mode: This mode doubles the SD card speed (FTP upload speed ~350 kB/s compared to ~180 kB/s in SPI mode). Needs one PIN less but fixed PIN assignments
    Add support for the PN5180 RFID reader:
    PN5180 has better RFID range/sensitivity and can read ISO-15693 / iCode SLIX2 aka Tonies
    [main.cpp, settings.h]
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2020-12-17 Fixed issue with non working SD card and RFID reader. Issue #9
    [main.cpp]
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2020-12-21 platformio.ini: Add common variables as dynamic variables to all board configs. main.cpp: -Bug Fix: Handle return code of connecttofs routine. If it is not successful the track is considered as finis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
    [main.cpp]
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2021-01-13 Correcting some syntax problems in the html file. Now the website can be loaded from ROM
    [main.cpp]
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2021-01-26 FileBrowser: Improve stability of folder recursive deletion by movin algorithm from js to esp32. FileList: Increase Json object size to 16384 Bytes in order to show folder with huge content better. J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
    [main.cpp]
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2021-01-28 Fixed '//' issue. Cleaning up code by removing commented out code from previous browser
    [main.cpp, settings.h]
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2021-10-30 Fixing crash when voltage was measured when no battery was plugged in
    [Led.cpp]
2021-11-05 Fix rare issue where the RFID tag is read before queues are initialized
    [LogMessages_DE.cpp, LogMessages_EN.cpp, main.cpp]
2021-11-08 fix PN5180 sleep issues
    Button wakeup will now be registered in case of spurious wakeups
    Correctly wake up on LOW signal
    [main.cpp]
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2021-11-29 better handling of coverimage: do not save image /.cover on SD card, instead just remember file, position and size for later use (avoid delays in playing) do not consume too much time in serving cove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
    [AudioPlayer.cpp, AudioPlayer.h]
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2022-01-11 - re-pin PN5180 library: better card recognition for ISO-14443 cards - remove state RFID_PN5180_NFC14443_STATE_SETUPRF: This is already handled in PN5180 library - wake-up from deep-sleep also with r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
    [Button.cpp, main.cpp]
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2022-01-11 Reverting some settings that were changed by accident. But SDMMC now default.
    [settings.h]
2022-01-13 Fixes wakeup from deepsleep while hp-PCB without inserted plug is connected with port-expander-PCB
    [Port.cpp]
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2022-01-30 Squashed commit of the following:
    commit 2e001bd3c07c5e5744c2d4d40cd4e7179dab6d4c
    Author: Torsten Stauder <stauder@ts-cs.de>
    Date: Sun Jan 30 22:33:29 2022 +0100
    Finalizing NTP-feature
    commit 5d13f340633ad96ad446954a2a102a134bff7079
    Author: tueddy <kaffee>
    Date: Sun Jan 30 21:07:07 2022 +0100
    make compile with SD in SPI mode
    commit 19d13041fa44ffeb0f6bb5d14f26a0f19ad00912
    Author: tueddy <kaffee>
    Date: Sun Jan 30 15:10:25 2022 +0100
    get current time and date at startup. Needed for correct SD card timestamp
    move SD card info to SdCard_PrintInfo();
    [LogMessages_DE.cpp, LogMessages_EN.cpp, main.cpp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]
2022-01-31 Fix #129 / Enable using button of RE without having RE enabled entirely
    [Button.cpp, settings-complete.h, settings-custom.h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]
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2022-02-03 Revert "Make ESPuino to jump back to first track if end was reached in loop-mode"
    This reverts commit e55904e912ce6ac3ac6fdd89fb68b6351365c302.
    [AudioPlayer.cpp, LogMessages_DE.cpp, LogMessages_EN.cpp]
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2022-02-08 improved web-upload progress minor fixes web-uplaod: show remaining time while uploading & time elapsed + KB/s when finished webpage: syntax fixes, own icon for images/cover image coverimage feature: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
    [AudioPlayer.cpp, AudioPlayer.h, main.cpp]
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2022-02-19 Bluetooth sink: update to latest library, no functional changes (make compile with Arduino 2.x.x) Bluetooth sink: Show AVRC-metadata web.cpp: fix compiler warnings
    [Bluetooth.cpp]
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2022-06-10 Progress-switch from uint8_t to double in order to eliminate indication-problems with large files
    [AudioPlayer.cpp, AudioPlayer.h, Led.cpp]
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2022-10-14 mqtt: Replace heartbeat by MQTT Last Will and Testament (LWT)
    Make use of the MQTT LWT feature to specify a message, that gets
    automatically posted by the broker to all subscribed clients when we
    disconnect ungracefully.
    This replaces the existing heartbeat message that is currently being
    sent every minute.
    [LogMessages_DE.cpp, LogMessages_EN.cpp]
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2022-10-14 mqtt: Load ClientId from NVM
    The MQTT Client-Id must be an MQTT broker wide unique id that
    identifies the client. When more than one ESPuino is added to the home
    network, it's uncomfortable having to change the define for the client
    id.
    Being able to specify the ClientId through the Web UI also simplifies
    a fully automatic MQTT setup in home automation systems. Since they
    need to know the ClientId it's helpful if they can directly use the Web
    UI to set it.
    An alternative approach would be to just use the WiFi hostname, but
    NVM is consistent with all other MQTT settings.
    [LogMessages_DE.cpp, LogMessages_EN.cpp, Mqtt.h]
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2022-10-18 revision: Add Git revision to logs
    This change adds a pre build script that generates a gitrevision.h
    header with the current git revision. That is then logged in the serial
    console and web log.
    When comparing log files (for instance to hunt issues) it's useful to
    know exactly the git version the software has been compiled with. If
    local modifications have been done, '-dirty' is added to the version
    so that uncommitted changes can easily be identified.
    [main.cpp]
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2022-10-18 audioplayer: Generalize handling of title
    This change generalizes the generation of the title that is shown in
    the Web UI and published over MQTT with the following goal in mind:
    - Save CPU cycles and memory since the formatting is just done once.
    - The exact same format is used for the Web UI and MQTT.
    - The initial title sent over MQTT is now correct and no longer "---".
    - Make the code easier to understand and maintain.
    [AudioPlayer.cpp, AudioPlayer.h]
2022-10-19 Prevents ESPuino from staying in mode BUSY forever if requested directory is empty
    [AudioPlayer.cpp]
2022-11-03 mqtt: Fix concurrency issue
    The existing code suffered from a race condition that eventually leads
    to broken MQTT messages being sent to the broker, that can cause the
    broker to terminate the connection.
    This issue is mainly caused by publishMqtt being called on different
    tasks at the same time (AudioPlayer_Task vs
    AudioPlayer_TrackQueueDispatcher).
    Adding logs around mqttPublish showed:
    RFID-Karte erkannt: (ISO-14443) ID: a7-ea-f6-ef
    RFID-Karte empfangen: 167234246239
    MQTT State/ESPuino/Rfid: 167234246239
    MQTT DONE State/ESPuino/Rfid: 167234246239
    MQTT State/ESPuino/LedBrightness: 0
    MQTT DONE State/ESPuino/LedBrightness: 0
    MQTT State/ESPuino/Playmode: 12
    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
    [AudioPlayer.cpp]
2022-11-03 mqtt: Avoid multiple topicTrackState messages
    The existing code sent topicTrackState 3 times. Before starting the
    track, once the track has started, once ID3/stream information is
    available.
    This commit now omits sending the message before a track has been
    started. In addition this now uses Audio_setTitle everywhere so that
    a bit of heap and stack memory is saved and there's also one less utf8
    conversion executed.
    [AudioPlayer.cpp]
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2022-11-21 mqtt: Fix title for webradio
    Starting with commit 751f182 the webradio stream title gets appended to
    the station title. This introduced a bug and now all further stream
    titles are simply appended.
    Fix the problem by simply replacing the title with the stream title
    updates. That way the station name is no longer visible after a while,
    but that behavior is aligned with titles on the SD card, where we
    also don't differentiate between the track title / artist / album / ...
    [AudioPlayer.cpp]
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2022-12-25 Led.cpp: Move condition check for progress redraw to separate function
    No functional changes. This prepares code for further refactoring and
    fixing.
    [Led.cpp]
2022-12-25 Led.cpp: Refactor volume level indication and fix small glitch
    This refactors the code that shows the volume level on the LEDs.
    Instead of waiting for further volume changes and then showing
    them in the next interation of the outer task loop, we simply
    loop and redraw in the tight loop.
    This also fixes a glitch where the LEDs briefly show the default
    pattern during volume control.
    [Led.cpp]
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2022-12-28 Button.cpp: Fix headphone detection while controls are locked
    When controls are locked Button_Cyclic() is aborted and Port_Cyclic()
    never gets called. This means we don't get the correct status of the
    HP_DETECT signal.
    To fix this abort Button_Cyclic() after Port_Cyclic() is called, so
    we can still detect if the headphones are connected.
    [Button.cpp]
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2022-12-30 Fix for settings-override.h.sample: - Avoid recursive includes - make the Constant unique - fix typo
    [settings.h]
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2023-02-11 Led improvements (#197)
    * initial commit
    * fix invalid line
    * complete rework
    * initial commit
    * fix dithering on dimmed LEDs
    * clean cast and rename of dim-function
    * rename some vars
    * remove special handling of volume
    * rework playlist-animation
    * some small cleanup
    * separate more animations. remove obsolte logic
    * cleanup
    * more cleanup and some bugfixes
    * fix bluetooth color for Sink-Mode
    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
    [AudioPlayer.cpp, Led.cpp, Led.h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]
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2023-03-22 Fix for stuck LED-Shutdown animation
    This commit fixes both parts of the Bug raised in the [forum](https://forum.espuino.de/t/bug-in-verbindung-mit-dem-led-ring-und-multibutton/1825?u=laszloh)
    [Led.cpp]
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2023-03-22 Change rotary encoder to delta mode
    Instead of calculating the audio volume with the position of the rotary encoder, just use it in a delta mode by resetting the counter after each read so it starts by zero.
    This allows us to just send the delta to the volume handler.
    [RotaryEncoder.cpp]
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2023-03-23 Change volume animation to triggered mode
    Make it so, that the volume animation can be triggered and always trigger it, even if we have reached min or max value.
    This fixes the feature request https://forum.espuino.de/t/verhalten-der-lautstaerke-anzeige-auf-dem-led-ring/1842/8
    [AudioPlayer.cpp, Led.cpp, Led.h]
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2023-04-03 Add missing translations
    Use translation system instead of defining the string hardcoded in the source code
    [AudioPlayer.cpp, LogMessages_DE.cpp, LogMessages_EN.cpp]
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2023-04-03 Fix remaining string trunctation warnings
    Reworked Web_DeleteCachefile to get a folder instead of a file path.
    This makes the function smaller and easier
    [AudioPlayer.cpp]
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2023-05-09 Bluetooth.cpp: Fix logging crash in sink mode (#238)
    In sink mode a2dp_source is NULL which causes a crash when the state
    change callbacks are called.
    To fix this pass the correct pointer to the sink or source object
    via the callback state variable and use a cast to BluetoothA2DPCommon
    for accessing the to_str() method.
    [Bluetooth.cpp]
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2023-05-22 This developer branch has stricter compiler rules, fix some of (mostly harmless) warnings
    [Led.cpp]
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2023-06-13 Bluetooth configuration tab in web-interface (#244)
    * Bluetooth configuration tab in web-interface
    * spelling correction
    * Spelling corrections #2
    [Bluetooth.cpp, settings.h]
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2023-07-04 fix volume jumping at startup when initVolume <> factory default (3u) fix log message for maxVolumeSet
    [AudioPlayer.cpp]
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2023-07-20 NTP: Allow to configure the timezone in settings.h fix .IRAM linking error from previous commit
    [LogMessages_DE.cpp, LogMessages_EN.cpp, settings.h]
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2023-08-04 Support for .oga audio files (Ogg Vorbis Audio container) spelling correction fix warning about unused variable
    [LogMessages_DE.cpp]
2023-08-11 check & avoid excessive "PING" calls from web-ui see bug discussion https://forum.espuino.de/t/tts-bugs-und-ein-mini-fix/2119
    [AudioPlayer.cpp, LogMessages_DE.cpp, LogMessages_EN.cpp]
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2023-09-24 avoid buffer-overflow in NVS import with invalid files check for NO_PLAYLIST for writing NVS entry
    [AudioPlayer.cpp]
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2023-10-21 Show free heap before & after creating new playlist Avoid log message "NVS entry not found"
    [LogMessages_DE.cpp, LogMessages_EN.cpp]
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2023-10-26 PlatformIO package 6.4.0 (Arduino Version remains 2.0.11) LPCD, RFID_IRQ on port-expander: fix compiler warning portTICK_RATE_MS is deprecated, use portTICK_PERIOD_MS instead (https://github.com/espr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
    [AudioPlayer.cpp, Bluetooth.cpp, Led.cpp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]
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2023-11-04 LPCD: wakeup check for ISO-14443 cards also with IRQ connected to port-expander Bugfix for showing wrong loglevel
    [Log.cpp]
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2023-11-22 Bugfix: Some commands e.g. Play/Pause did not work in BT-Source mode New command CMD_TOGGLE_MODE to switch Normal => BT-Sink => BT-Source Faster pairing animation in BT-Source mode to better distingu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
    [Led.cpp]
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2023-12-05 Fix LED visualization for battery measurement if a battery module other than voltage is used (#273)
    [Led.cpp]
2023-12-08 Fix webstream playlist abort when track fails (#276)
    When the webstream connects but is redirected to a 404 page, we should not abort the playlist but jump to the next entry.
    [AudioPlayer.cpp]
2023-12-09 Fix webstream playlist abort when track fails (#276), thanks to @laszloh !
    [AudioPlayer.cpp]
2023-12-10 Fix wrong states on PE output pins (and SD-card failure on restart) #278, thanks to @36b6fp6s !
    [Port.cpp]
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2023-12-28 improve port expander handling (#283)
    * suppress spurious interrupts from PE
    The PORT_ExpanderISR() is called very often although no interrupt
    was triggered by the PCA9555. The interrupt line is held low by the
    PCA9555 until the input registers are read. So if the interrupt
    line is not low, there is no need to read the registers.
    * disable PORT_ExpanderISR until the input registers have been read
    The interrupt line is active low so switch from FALLING to ONLOW.
    To then prevent continuous calling of the ISR, it needs to be disabled.
    Port_ExpanderHandler() re-enables it after handling things. It also
    takes care to enable it in the first place.
    While at it, use digitalPinToInt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
    [Port.cpp]
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2024-01-02 Partly revert: Fix webstream playlist abort when track fails (#276), af0b078 (#285)
    Some properties like repeatCurrentTrack, repeatPlaylist, sleepAfterCurrentTrack, sleepAfterPlaylist, saveLastPlayPosition got lost with https://github.com/biologist79/ESPuino/commit/af0b07801194b55a6ccdfa3c2f7da1ab7e615600
    See also https://forum.espuino.de/t/3-bugs-in-audioplayer-cpp-hoerbuchmodus-speichern-der-playposition-sleepafter/2456/3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
    [AudioPlayer.cpp]
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2024-01-17 JSON buffer overflow checks fix some hints found with cppcheck move save settings errors to logmessages
    [AudioPlayer.cpp, Led.cpp, LogMessages_DE.cpp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]
2024-01-21 Update Led.cpp
    - Fix missing "#ifdef NEOPIXEL_ENABLE" which cause the build to fail if the neopixel feature is disabled
    [Led.cpp]
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2024-02-01 Remove nvsDump fix some warnings compiled with -Wdouble-promotion (float to double conversion)
    [Led.cpp]
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2024-02-08 Playlist fixes (#299)
    * fix crash when playing invalid file
    * avoid unnecessary string copying
    [LogMessages_DE.cpp, LogMessages_EN.cpp, LogMessages_FR.cpp]
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2024-02-15 Rework playlist generation (#275)
    * Rename and adapt playlist destruction function
    Rename freeMultiCharArray to freePlaylist and specialise it so that it can be used to destroy the content of a playlist.
    Move all playlist related functions into it's own header
    * Optimise playlist generation
    Use std::vector instead of POD char* array so that we do not have to care about memory managment.
    We still have to take care of the strings in the playlist manually.
    Make x_malloc more forgiving by prefereing the PSRAM and not enforcing it.
    * Change playlist to std::vector pointer
    * rework SdCard_pickRandomSubdirectory
    Rework SdCard_pickRandomSubdirectory to fir into the new playlis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
    [AudioPlayer.cpp, AudioPlayer.h, Led.cpp]
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2024-03-15 MQTT receive: Bug fix and avoid payload copy (#309)
    * Check if there is enough data to copy an item to the queue
    xQueueSend will copy as many bytes to the queue as defined for the items
    when the queue was initialized. gRfidCardQueue was initialized with an
    item size of cardIdStringSize (= 13). If the MQTT payload would be
    shorter, this would previously lead to an out of bounds access.
    * No null terminated string for logging by passing the length to printf
    * No payload copy on MQTT receive anymore by using std::string_view
    [LogMessages_DE.cpp, LogMessages_EN.cpp, LogMessages_FR.cpp]
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2024-03-28 Fix some warnings with upcoming Arduino 3 (ESP-IDF v5.1) for ref: https://github.com/espressif/esp-idf/issues/9511
    [AudioPlayer.cpp, Log.cpp]
2024-03-30 Update PlatformIO package to 6.6.0 https://github.com/platformio/platform-espressif32/releases/tag/v6.6.0 RC522: Fork reposity to avoid warning "MFRC522Extended.cpp:824:29: warning: ordered compariso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
    [AudioPlayer.cpp]
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2024-04-07 Equalizer settings to WebUI (#313)
    * adding equalizer controls to settings page and storing values in NVS
    * restoring playMono behaviour
    * appending " db" to the equalizer tooltips
    * translations changed to less technical terms for lows, mids and highs
    * German translation had one miss
    * duplication in english log messages
    * Equalizer settings moved to dialog on Control page
    * Infos added
    * Translations
    * Fix for title translation
    * Visual improvments for Equalizer button and slider sections
    * Setting equalizer settings regardless of stereo/mono
    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
    [AudioPlayer.cpp, AudioPlayer.h, LogMessages_DE.cpp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]
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2024-04-14 Fix warning "clearing an object of non-trivial type 'struct playProps'" update changelog & revision
    [AudioPlayer.cpp]
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2024-04-18 Correct calculation of newFilePos for SEEK_POS_PERCENT, thanks to @sfields!
    If audio->getAudioDataStartPos() is not zero, newFilePos was not calculated properly, and would always be too small, maybe even smaller than audio->getAudioDataStartPos().
    [AudioPlayer.cpp]
2024-04-22 Added virtual RFID-Cards (#319)
    * replaced magic websocket codes with WebsocketCodeType
    * added 10 virtual RFID cards and corresponding cmds
    * clang
    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
    [AudioPlayer.cpp]
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2024-11-25 Moving settings to the Web UI (#350)
    * Transferring defines from `settings.h` to be manageable on the Web UI:
    * PLAY_MONO_SPEAKER
    * SAVE_PLAYPOS_BEFORE_SHUTDOWN
    * SAVE_PLAYPOS_WHEN_RFID_CHANGE
    * SAVE_PLAYPOS_WHEN_RFID_CHANGE
    * USE_LAST_VOLUME_AFTER_REBOOT
    * VOLUMECURVE
    * clang and personal settings ...
    * So much clang!
    * Moving settings to settings-override.h
    * Cleaning `settings.h` from now unused defines
    * added missing volume curve checkbox in html
    * mke clang happy
    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
    [AudioPlayer.cpp, AudioPlayer.h, Bluetooth.cpp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]
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2024-12-27 Fix audio dropouts in BT-Source mode avoid WDT reset & give audio/other tasks more CPU time Send all the audio data to the ring buffer in a single call, not every single sample. - arduino-audio-tools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
    [AudioPlayer.cpp, Bluetooth.cpp]
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2025-01-28 Make led, rotary & button settings configurable at runtime (#358)
    * Make led, rotary & button settings configurable at runtime
    * NEOPIXEL_REVERSE_ROTATION + LED_OFFSET
    * add extended settings to html frontend
    * translation corrected
    * bugfix get hui start/end from NVS
    * bugfix dynamic list of control leds. Co-authored-by @trainbird , thanks!
    * hue start/end with slider. Co-authored-by @Trainbird , thanks!
    * import/export settings not ready yet
    * refactor led-task
    - led settings struct
    - notify task for changed settings with a queue
    * refactor Led_InitialBrightness, Led_Brightness, Led_NightBrightness to struct LedSettin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
    [Button.cpp, Led.cpp, Led.h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]
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2025-04-24 Make PAUSE_WHEN_RFID_REMOVED & DONT_ACCEPT_SAME_RFID_TWICE configurable at runtime (#362)
    * make PAUSE_WHEN_RFID_REMOVED conifurable at runtime
    * Make DONT_ACCEPT_SAME_RFID_TWICE_ENABLE configurable at runtime
    * Add missing changes for DONT_ACCEPT_SAME_RFID_TWICE
    * Make pauseIfRfidRemoved working for RC522
    * On load settings: disable #dontAcceptRfidTwice if #pauseIfRfidRemoved is enabled
    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
    [AudioPlayer.cpp, AudioPlayer.h]
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2025-10-23 New feature: recursive playlists (#381)
    * Adding new recursive playmodes
    * Update README
    * Regression fix: remove volume-queue from IRreceiver.cpp
    * Removal of 4bit-bitmask from playmode (thanks to @Joe91)
    * Switch to long commit IDs
    * Rewrite + rename of findNextOrPrevDirectoryTrack()
    * Refactoring of NVS-wrapper to enable AUDIOBOOK_RECURSIVE (thanks to @Joe91)
    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
    [AudioPlayer.cpp, AudioPlayer.h, Led.cpp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]
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2025-11-24 Audio Library Update: Switch to callbacks, restore cover images (#383)
    * Audio Library Update: Switch to callbacks, restore cover images
    - Updated ESP32-audioI2S library:
    - Added seeking support for OGG and Opus; improved seeking for FLAC (essential for audiobook mode)
    - Enhanced cover image extraction for MP3, OGG, and Opus (more covers can now be extracted)
    - Fixed playback of previously unplayable OGG/Opus files (more files can now be played)
    - Now provides ID3/Vorbis metadata for OGG and Opus via evt_id3data
    - Replaced deprecated weak function bindings with functional callbacks.
    Old overrides (e.g. audio_showstation, audio_id3data) are no longer supported. This fixes the time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
    [AudioPlayer.cpp]
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2026-01-08 More flexible MQTT-handling and new MQTT naming scheme (#373)
    * remove audio-tak
    * rename queues and remove queues
    * place audio into ps-ram again
    * move rfid-task to core 1
    * fix: add log for audio-level again
    * some more tweaks on LED and RFID-Task (seems to remove the audio-issues, but not tested yet)
    * also remove LED-Task
    * more performant main-loop
    * some cleanup. No flicker at all anymore
    * separate cores more strictly
    * save wip
    * separate cores more strictly
    * use original positioin of loop again and add pause-mechanism again
    * fix from wolle (set file pos works again)
    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
    [AudioPlayer.cpp, Led.cpp, Mqtt.h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]
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2026-03-28 Bug fix: Suppression of sound artifacts on the speaker during Bluetooth playback (#397)
    [Bluetooth.cpp]
2026-05-08 Rfid at runtime (#403)
    * create rfid-runtime
    * undo sdkconfig-changes
    * some cleanup. Fix python 3.14
    * fix formatting, verify selected reader
    * get rid of lpcd-setting
    * put rfid-stuff in gPrefsRfid
    * rename System_init_LPCD
    * fix json formatting
    * handle rfid-exit as well
    * enable processhtml again
    * fix i2c-define, reduce firmware-versions
    * fix GPIO-PA-EN in BT
    * try to fix commit-step
    * remove some defines
    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
    [AudioPlayer.cpp, Bluetooth.cpp, Led.cpp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]
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2026-05-25 BT and other stuff for dev (#405)
    * support special chars in filesystem
    * fix in ftp
    * update ftp
    * fix settings on mobile devices
    * fix bluetooth (rollback)
    * some more updates
    * fix missing ram in BT-mode
    * prevent stuff in BT-speaker-mode
    * don't build bt-builds anymore
    * disable ttgo_t8 for now and node js20 update
    * test: only use one folder for each target
    * fix of bluetooth-headphones
    * fix autoformat issue on .json files
    * fix review issues
    [AudioPlayer.cpp, Bluetooth.cpp, LogMessages_DE.cpp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]
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

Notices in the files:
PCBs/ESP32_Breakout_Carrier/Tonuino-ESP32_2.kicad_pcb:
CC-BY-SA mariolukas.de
